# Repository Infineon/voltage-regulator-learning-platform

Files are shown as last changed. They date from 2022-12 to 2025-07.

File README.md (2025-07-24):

# Learning Platform for Switching Regulators

<p align="center">
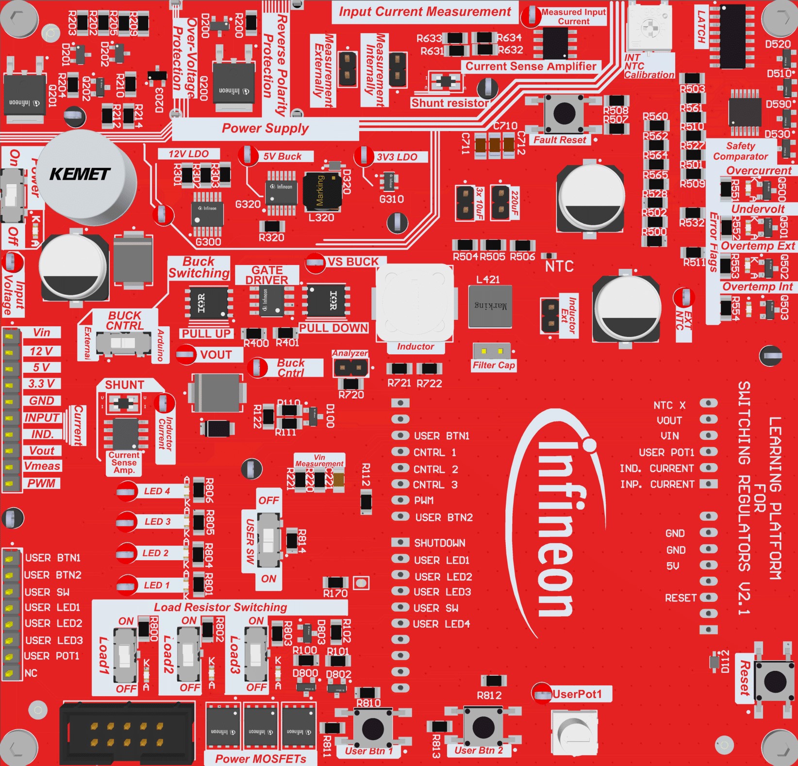
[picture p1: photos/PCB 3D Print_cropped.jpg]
  
</p>

This platform is designed with the intention of providing an interactive educational opertunity to university students with diverse technical backgrounds on switching regulators (namely buck converters). The project aims to develop the students' skills on using basic microcontroller IO features as starters and then build upon those skills to use a gate driver to implement a buck converter and monitor its output and efficiency. Along the Buck converter design process, the students get to use the the on board's peripherals to understand the different properties of buck converters and how they could be optimized. 

## Project's History
The project was introduced as a bachelor thesis of **Lukas Wiegert**. (*version 1.0*). Continued and further developed by **Adrian Keil** (*Versions: 1.0 ,1.1 ,1.2*) and finalized by **Youssef Tarkhan** (*versions: 2.0, 2.1*). The latest update was done 2025 from **David Lopez** (*version: PCBv3*). The boards are used by the Technical University of Munich to teach the students and assess the quality and functionality of these boards and provide an open source curriculum.

# Latest Update PCBv3

The latest update included mainly following changes:
- Removing the 3.3V rail. Only two remaining power supply rails (12V for power part, 5V for digital logik and measurements).
- Fixed common error that current measurement opamps burn because of shorted ouputs (male pinheaders get easily shorted when probed)
- Additional output resistance as second safety measure

# Board Breakdown

<p align="center">
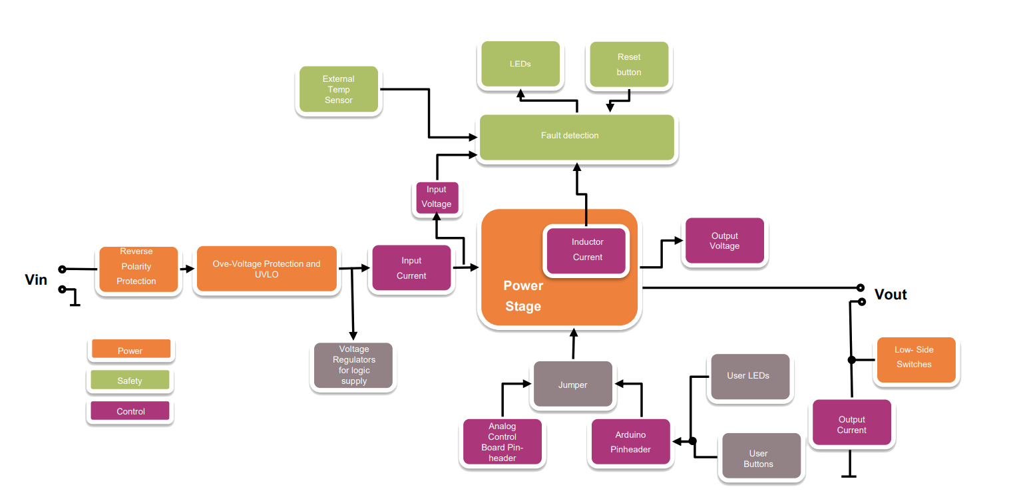
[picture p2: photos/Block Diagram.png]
  
</p>

**Brief summary**: As you can see from the block diagram, the board needs an input connection. (Bannana ports are provided at the bottom side of the board).  After the board makes sure that the polarity and the voltage are in check, the power is fed into the board's internal powersupply compartment. If the voltage level is below 10V then you will observe the undervoltage LED glowing in RED. The powerline feeding the whole board interfaces two optional possibilities for input current measurement. Power is then fed onto the power stage which consists of the components needed for the buck switching with a **VOut** output (*In older versions of the board there used to be additional banana ports for the **Vout** terminal and an additional ground banana port*.) Power is additionally fed into the arduino peripherals for basic microcontroller usage (LEDS, Switches, Buttons and Potentiometers). 

*Note that for every measurable quantity such as the input current for instance, there is a testpoint that could be attached onto an oscilloscope in order to have an easier experience when trying the measure this quantity*

# Microcontroller Pinouts
This platform is an arduino compatable shield. It is intended to be used in combination with the XMC1100 Bootkit
The labelling of the XMC1100 Bootkit pins is placed on the bottom layer's silk screen.

>An Arduino compatible shield is a hardware expansion board that is designed to be compatible with Arduino microcontroller boards. It is called a "shield" because it typically attaches on top of an Arduino board, extending its capabilities and providing additional functionalities

<p align="center">
  
</p>

<center>

## XMC 1100 Bootkit Pins
| Pin | Net | Type | Description |
|---|---|---|---|
| A0 | In_Curr_ADC | Input  | Analog input for current measurement |
| A1 | Inductor_Current_ADC  | Input  | Analog input for inductor current sensing |
| A2 | UserPot1 | Input  | Analog input for user potentiometer 1 |
| A3 | Vin_Meas | Input  | Analog input for voltage measurement |
| A4 | Vout_Meas | Input  | Analog input for output voltage measurement |
| A5 | NTC_ext | Input  | Analog input for external NTC temperature |
| D0 | NC | NC | Not connected |
| D1 | NC | NC | Not connected |
| D2 | UserBtn1 | Input  | Digital input for user button 1 |
| D3 | Cntrl1 | Output | Digital output for control signal 1 |
| D4 | Cntrl2 | Output | Digital output for control signal 2 |
| D5 | Cntrl3 | Output | Digital output for control signal 3 |
| D6 | Buck_Cntrl_Arduino | Output | Digital output for Arduino buck control |
| D7 | UserBtn2 | Input  | Digital input for user button 2 |
| D8 | Shutdown | Input  | Digital input for shutdown signal |
| D9 | User_LED1 | Output | Digital output for user LED 1 |
| D10 | User_LED2 | Output | Digital output for user LED 2 |
| D11 | User_LED3 | Output | Digital output for user LED 3 |
| D12 | UserSw | Input  | Digital input for user switch |
| D13 | User_LED4 | Output | Digital output for user LED 4 |

<br><br>
</center>

> **Note:** The following code snippet defines all the required arduino pins for using the platform, simply copy it to the beginning of your code (before the setup)

<br><br>
<center>

```cpp
// Define all Arduino pins
// Digital Out
#define USER_LED1     9
#define USER_LED2     10
#define USER_LED3     11
#define USER_LED4     13
#define BUCK_PIN      6

// Digital In
#define USER_BTN1     2
#define USER_BTN2     7
#define SHUTDOWN      8
#define USER_SW       12

// Analog In
#define IN_CURR       A0
#define INDUCTOR_CURR A1
#define USER_POTI     A2

#define VIN_MEAS      A3
#define VOUT_MEAS     A4
#define NTC           A5

```

</center>
<br>
<br>
Also add the following pin setup lines into your setup loop 

<center>

```cpp
  pinMode(BUCK_PIN, OUTPUT);
  pinMode(USER_LED1, OUTPUT);
  pinMode(USER_LED2, OUTPUT);
  pinMode(USER_LED3, OUTPUT);
  pinMode(USER_LED4, OUTPUT);
  pinMode(USER_BTN1, INPUT);
  pinMode(USER_BTN2, INPUT);
  pinMode(USER_SW, INPUT);
  pinMode(SHUTDOWN,INPUT);
  pinMode(USER_POTI,INPUT);
  pinMode(INDUCTOR_CURR,INPUT);
  pinMode(IN_CURR,INPUT);

```

</center>
<br>
<br>

> **Note:** In order to use both user buttons you'll have to unsolder the resistor at Pin 1.4 (check out the diagram below)

<p align="center">
  <a href="https://www.infineon.com/cms/de/product/evaluation-boards/kit_xmc11_boot_001/">
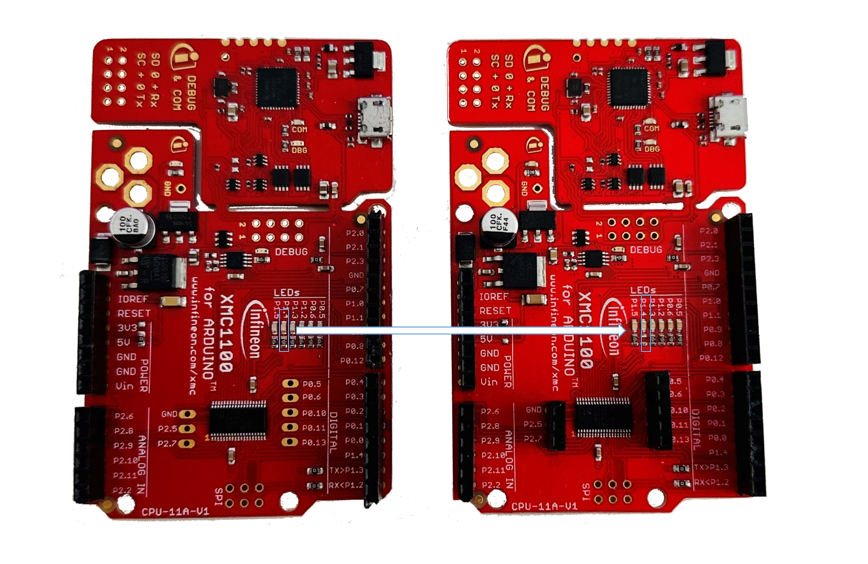
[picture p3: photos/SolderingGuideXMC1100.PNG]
  
  </a>
</p>

# Power Input
The board is equipped with a variety of safety measures to ensure that it not only has a long life, but also ensure that students get to have a higher level of freedom with it. The board is to be powered with a DC power supply through banana plugs. 

<p align="center">
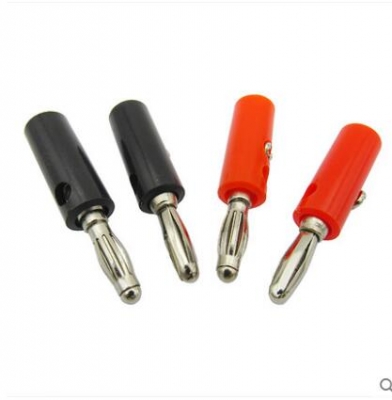
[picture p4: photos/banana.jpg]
  
</p>

- First stage of the power input is going through the reverse polarity protection circuit, following by over voltage detection circuit. ( In case of an overvoltage detection, power is cut from the main circuit through a MOSFET) Note that the board supports up to 30V but has a recommended to be used in the 15V input range
- Voltage is then delivered to the board compartments : Powersupply, Safety Comparator, Powerstage stage & Miscellaneous  

# Power Supply
The Optimum input Voltage for the board input is around **15V**. In case the voltage goes over 19V the board goes into a hysterisis where it only gets back in operation when the voltage level goes below ****. Feel free to check the simulation files if you want to get a deeper insight into how the hysterisis works on a circuit design level. (You will have to install the spice model files for the ATL431, [click here](https://www.youtube.com/watch?v=EwAxUvS5z-0) for a guide on how to do that)
Along with the input being fed into the board, the board additionally has 3 additional power components which are:
<center>

 **12V LDO**: 
<p align="center">
  <a href="https://www.infineon.com/cms/de/product/power/linear-voltage-regulator/linear-voltage-regulators-for-automotive-applications/tlt807b0epv/">
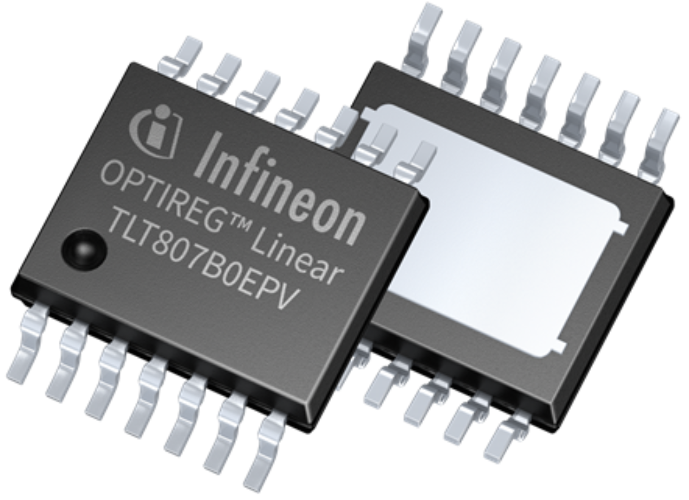
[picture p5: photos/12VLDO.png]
    
  </a>
</p>
	- Gate driver IC
	- Input Internal Current Sense Amplifier
	- Safety Latch 
	- Safety Circuit Comparator
	- Safety LEDs

**5V Buck**: 
<p align="center">
  <a href="https://www.infineon.com/cms/de/product/power/dc-dc-converters/switching-regulators/optireg-switchers-automotive/tlf50211el/">
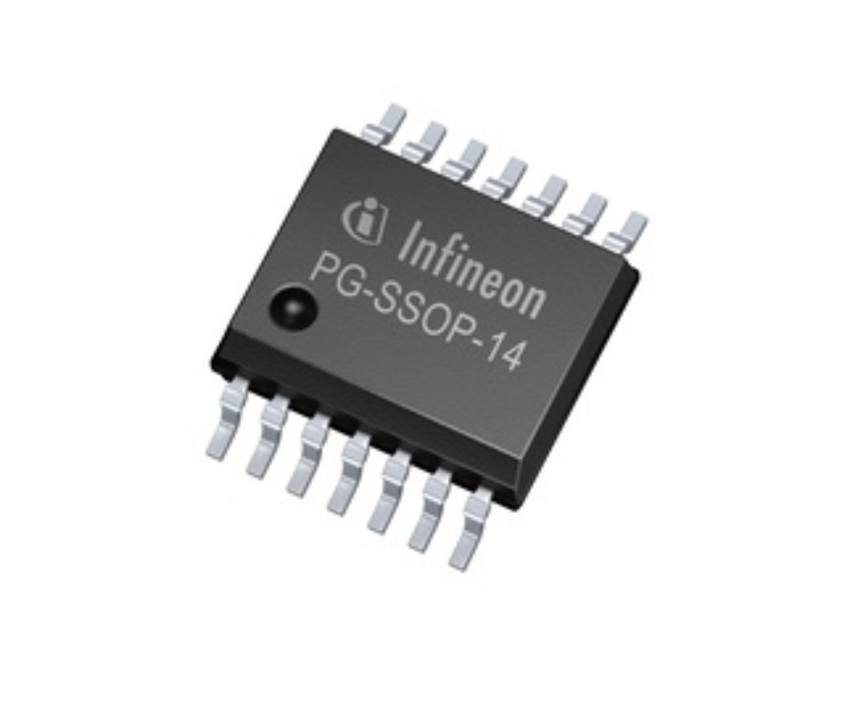
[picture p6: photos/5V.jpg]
    
  </a>
</p>
	- 3V3 LDO
	- Arduino Compatable MCU 
	- Safety Circuitry Voltage Threshhold (*Under-Voltage Detection*)
  
**3V3 LDO**:
<p align="center">
  <a href="https://www.infineon.com/cms/de/product/power/linear-voltage-regulator/linear-voltage-regulators-for-automotive-applications/tle4295g-v33/">
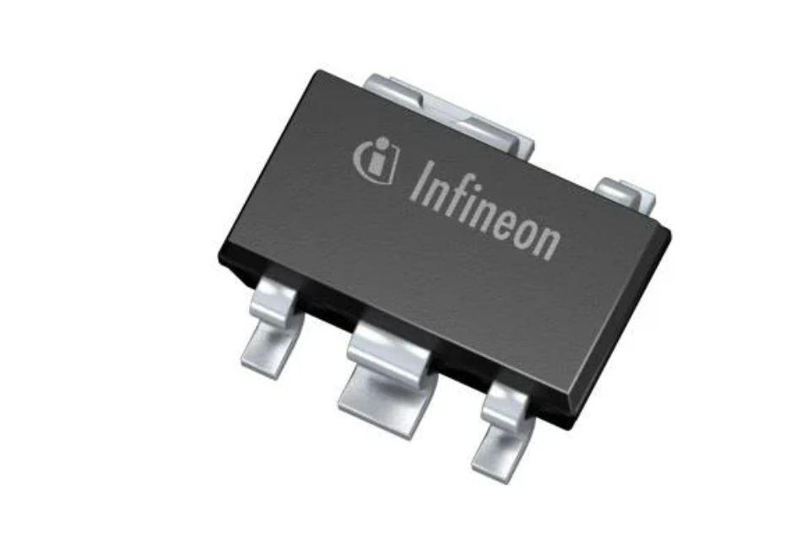
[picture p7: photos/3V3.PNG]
    
  </a>
</p>
	- Output Internal Current Sense Amplifier
	- ADC Compensation for MCU Input
	- Safety Comparator Circuit
</center>		

<br><br>

# Safety
The safety compartment of the board is comprised mainly of a comparator and a safety latch, where when the safety comparator detects a flag, this flag is saved on the latch. (To reset the latch all you'll have to do is press the latch reset button)

For example if the undervoltage flag is raised (Input voltage goes below 10V), the undervoltage flag will be raised and the corresponding LED will turn on. Aslong as the latch has not been reset, even if the input voltage goes above 10V, the LED will stay on and the shutdown signal will keep getting sent to the microcontroller and the power components. 

**Flags**

When safety flags are triggered, a **shutdown** signal is generated and the corresponding flag's LED is lit. The **shutdown** signal is delivered to the microcontroller and the power stage components. The powerstage is disabled as long as the shutdown signal is being delivered to its components.  

- **Overcurrent**
  - The output current from the powerstage is measured over a shuntresistor and a current sense amplifier. The output signal is then fed into a the safety comparator, which is compared to a constant reference voltage. (This reference voltage is equal to the corresponding output of the amplifier when the output current is around **2.8A**). 
  	<p align="center">
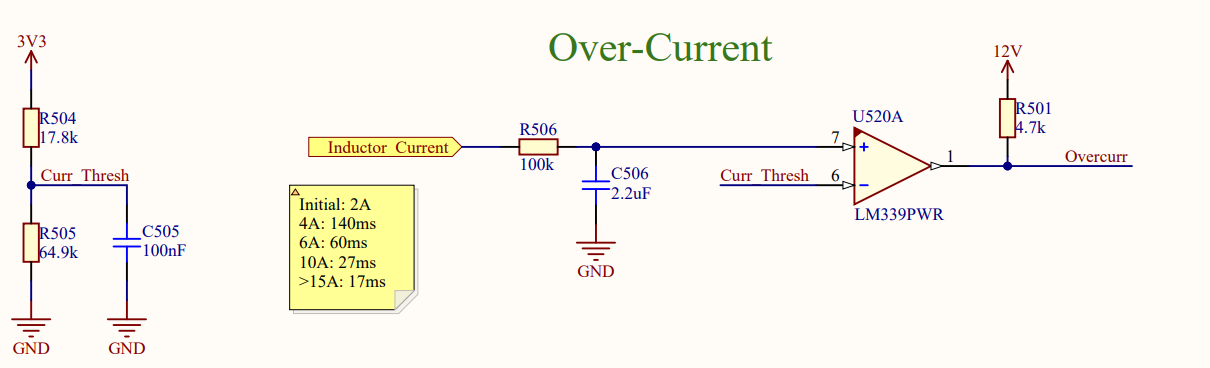
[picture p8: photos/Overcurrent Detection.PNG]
	
	</p>

- **Undervoltage**
  - the input voltage is fed through the two equal value resistors R510 and R511 and the signal is halfed (voltage divider Law), and is then fed into the comparator. As reference the 5V Buck output is fed into the other input of the comparator. If the input voltage goes below 10V , then half of that signal will be lower than 5V and so the undervoltage flag would be triggered.
  <p align="center">
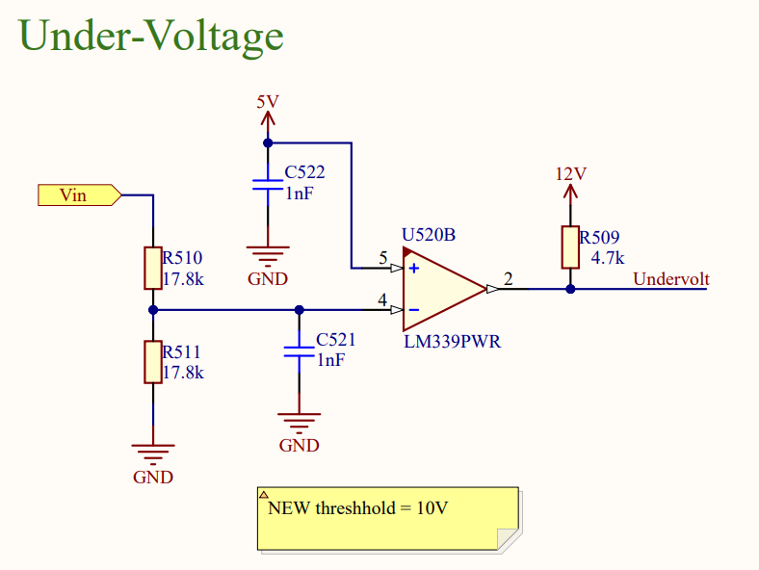
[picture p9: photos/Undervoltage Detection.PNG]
	
	</p>

- **Overtemperature (External)**
  - An NTC is connected on the external resistor board. (Negative Thermal cooefficient resistor; pretty much a fancy word for a resistor, who's resistance value changes when its temperature changes). The NTC's signal is connected to an input of the safety comparator with a reference signal connected to the other input.
    <p align="center">
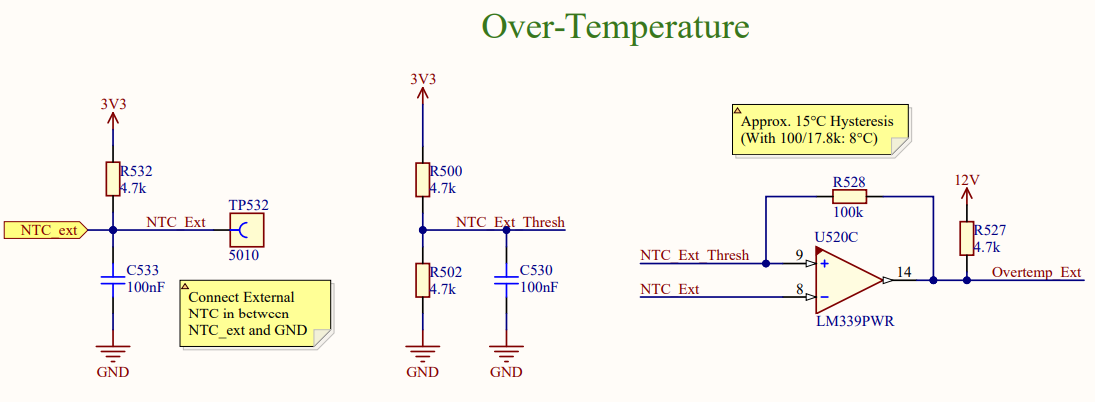
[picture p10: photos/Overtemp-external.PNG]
	
	</p>
- **Overtemperature (Internal)**
  - Similar to external overtemperature detection, however the NTC is onboard and there is a variable resisotr on board to calibrate the onboard overtemperature limit of the board. 
<p align="center">
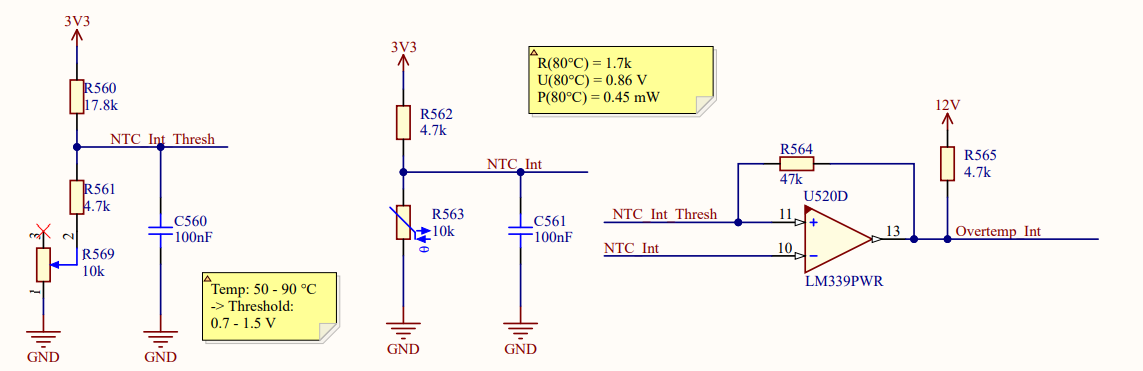
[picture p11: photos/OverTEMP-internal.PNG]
	
	</p>

- **Safety Flag LEDs**
  - you can find the safety LEDs are placed on the top right corner of the PCB
<p align="center">
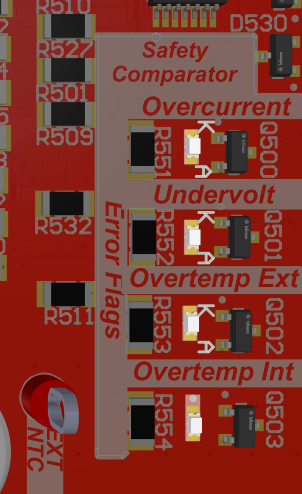
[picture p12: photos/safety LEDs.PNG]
	
	</p>

<br><br>
## Miscellaneous
The board is equipped with:
- 1 User programmable potentiometer
  
- 2 User programmable buttons
  
- 4 User programmable LEDs

- 1 User programmable Switch

<br>

##  Buck Operation
The buck operation takes place over a gate driver; what happens: is that the gate driver takes in pulse width modulated signals from the microcontroller (**XMC 1100 Bootkit**) or an external controller through the **PWM** pin on the external control pin header.  The users have to modify the **BUCK CNTRL** switch to adapt the circuitry to whether or not the control signal would be coming from the external control pin header or through the onboard controller pins. The students get to change the frequency and duty cycle of the signal in order to achieve their desired output voltage. 

<p align="center">
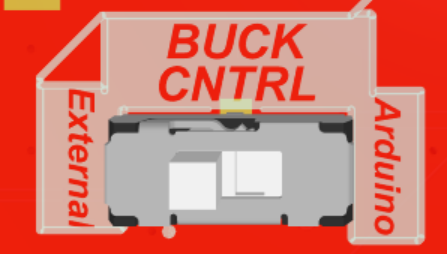
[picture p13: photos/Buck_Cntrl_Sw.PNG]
	
	</p>

There are also some jumpers on board that could adjust the output circuity of the buck operation.
Jumpers are available for: 
- Connecting three 10 uF Capacitors 
- Connecting a 220uF capacitor
- Connecting a 15uH inductor

<p align="center">
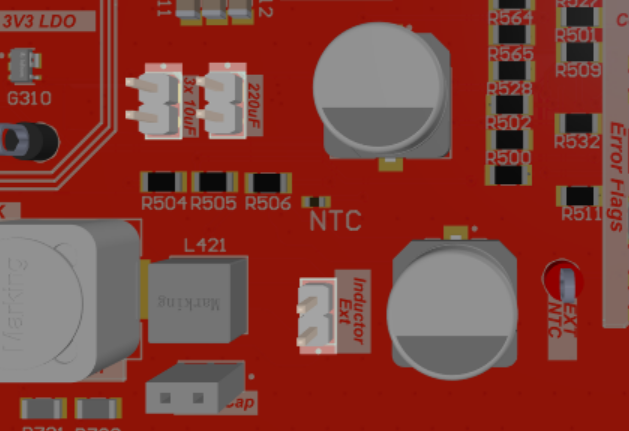
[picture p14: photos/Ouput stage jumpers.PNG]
	
	</p>

## External Control

Aside from using the board as a shield, it could also just be connected to an external controller circuit.

<p align="center">
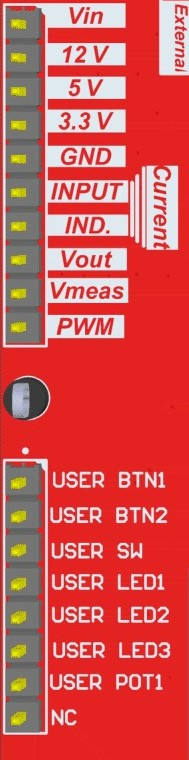
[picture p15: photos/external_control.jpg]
	
	</p>

As shown in the diagram above, using jumper cables, the user externally has access to: 

- Input voltage to through the Banana cables
- 12V Output of the LDO
- 5V Output of the Buck Controller
- 3.3V Output of the LDO
- Input Current Sensor Reading
- Output Current Sensor Reading
- Output Voltage 
- Output Voltage (Calibrated to 0 to 5V)
- External Buck Control
- User Button 1 Input
- User Button 2 Input
- User Switch Input
- User LEDs (1 to 3)
- User Potentiometer 1 Input

### NTC Calibration
- For making sure that the temperature on board is in check, negative thermal coefficient resistors are chosen . The onboard maximum temperature could easily be calibrated by adjusting a potentiometer for temperature limitation between (50°C and 90°C)

## Current Measurement
The main method of current measurement is the combination of a shunt resistor and a current sense amplifier. This setup is repeated in the input and output current measurement system. The operation relies on a voltage drop accross the shunt resistor proportional to the current flowing through it. This voltage drop is amplified by the current sense amplifier into a new voltage value. This voltage value is read by the micro-controller's ADC and it's used to subsequently calculate the value of the current.

<p align="center">
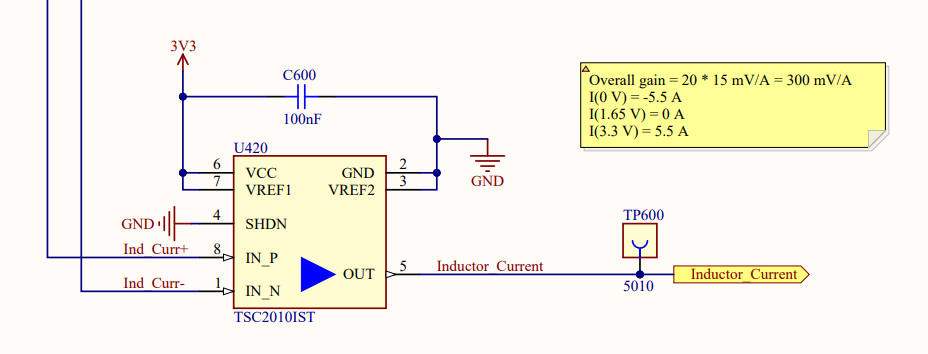
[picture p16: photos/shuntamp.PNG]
	
	</p>

the main component (TSC2010IST) in the diagram above is a current sense amplifier. This current sense amplifier is connected over a shunt resistor (pins: 1 & 8). The output of this amplifier is proportional to the amount of current going through the shunt resistor. 

<br>

# Testpoints

The board is equiped with test points to make it easier for students to observe different quantities using an oscilloscope.

<center>
<p align="center">
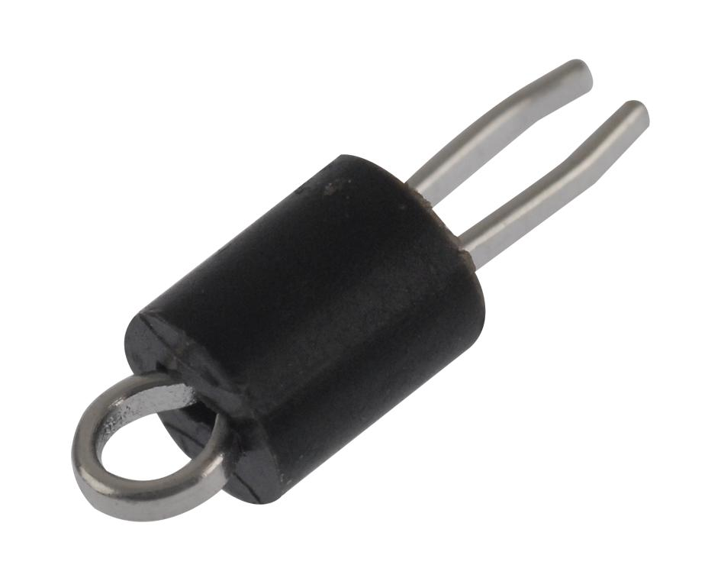
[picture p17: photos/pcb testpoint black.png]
	
	</p>
All black testpoints are Ground testpoints
 
<p align="center">
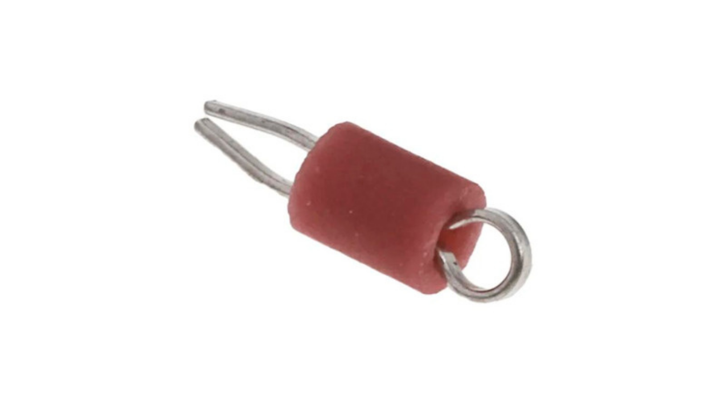
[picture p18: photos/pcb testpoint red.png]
	
	</p>
Red testpoints are labelled with their corresponding measurement quantity. 

</center>
<br>

# Simulation Files
To provide a rich experience to students, the simulation files for most of the building blocks of the learning platform are provided. These simulations are accessable on LTSPICE, which is an open source freeware, that is very popular in the industry.  

You can find these simulations under the Directory /Simulations.
<br>

# Future Strategy 
This project is not yet fully disclosed, and it will remain under  development so feel free to reach out to youssef.tarkhan@infineon.com for any inquiries or suggestions anytime.

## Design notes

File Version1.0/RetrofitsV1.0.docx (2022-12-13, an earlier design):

# Necessary Changes on V1.0 Board

# Drain and Soruce of Q201 are reversed

1. Desolder Q201
2. Cut the traces as shown by the red marks in the following image:

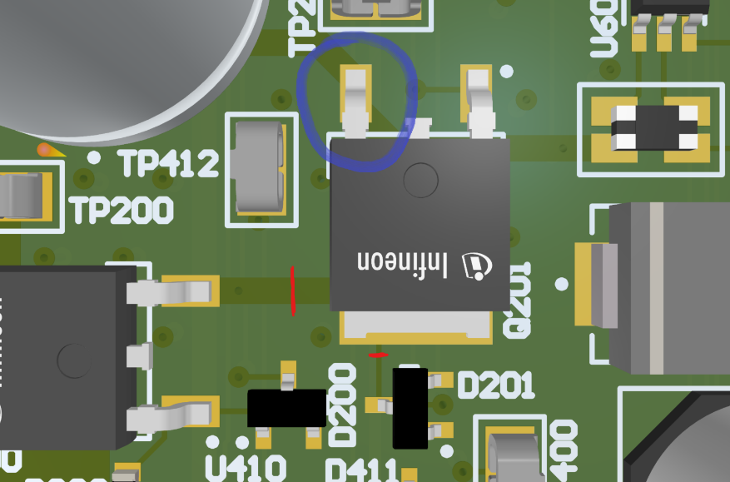
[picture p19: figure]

3. Straighten the leg of Q201 that is marked blue. Q201 has to be desoldered for this! Use flat pliers and just hold down on the leg, not at the case. Otherwise you will damage the transistor.
4. Use a piece of desoldering braid or something similar to connect the two pads of Q201 as shown below:

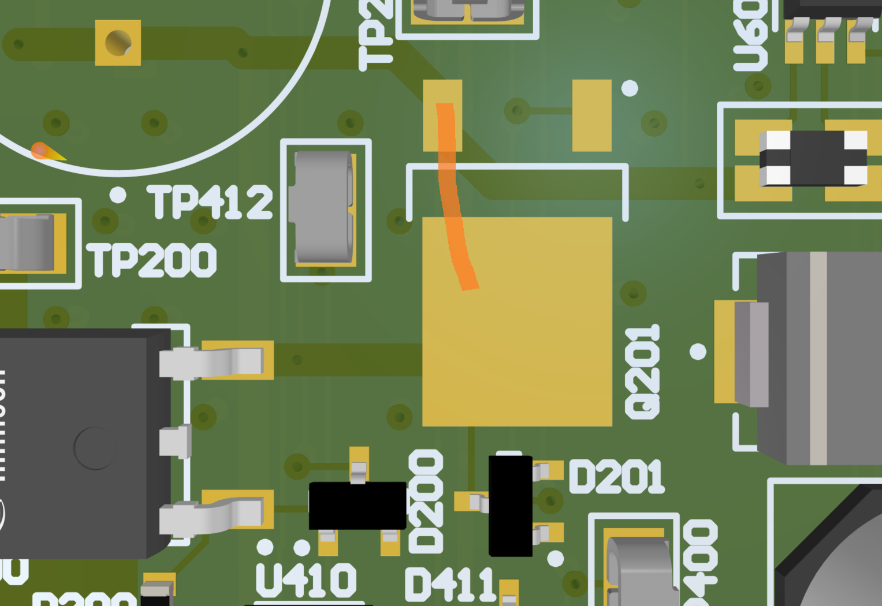
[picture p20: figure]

5. Now resolder Q201 (just on the two pads, the bent pin is left open)
6. Now use some thick copper wire to connect the bent leg of Q201 (not the pad below) and Q200 as shown below and finally some thin copper wire to connect Q201 to the Diode D201:

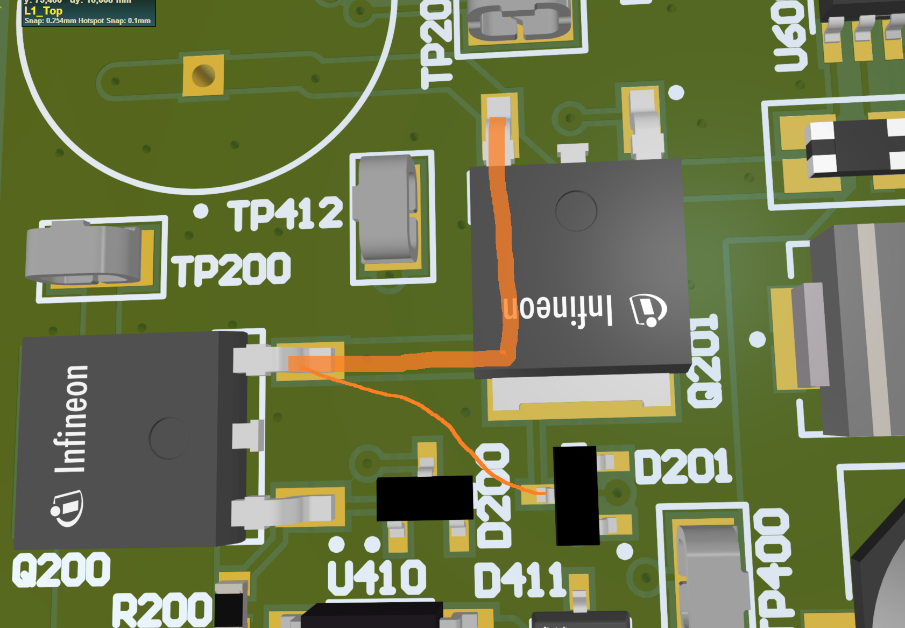
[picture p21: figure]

# Arduino powers logic supply through its Vin

Cut the trace in the shown location (red). Scrape off solder mask on both sides and solder the diode in place as shown. I used an MBR120ESFT1G (20V, 1A Schottky). But the diode can also be soldered somewhere else between Arduino 12V and Board 12V.

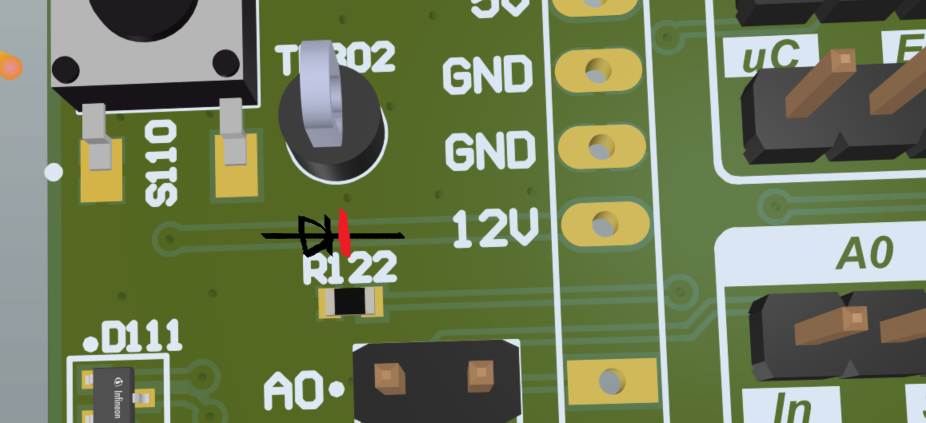
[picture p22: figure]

# Floating Boost_Cntrl

Rotate R123 90° and then connect its left leg to the center pin of the Boost Cntrl Header (run wire to the back side of the PCB)

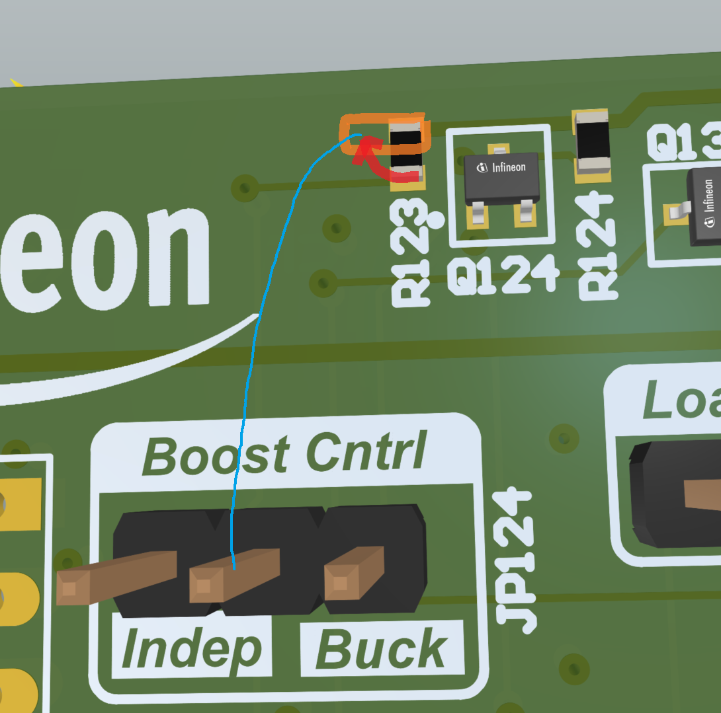
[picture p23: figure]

# Arduino powers logic supply through gate drivers

1. Option 1:
  a. Desolder U400 and U430
  b. Straighten Pin 1 or bend slightly upwards
  c. Resolder U400 and U430
  d. Insert a 4k7 resistor between Pin 1 and the pad below
2. Option 2:
  a. Cut the trace on the back, scrape off solder mask and insert 4k7 resistor (the banana plugs are the top ones)

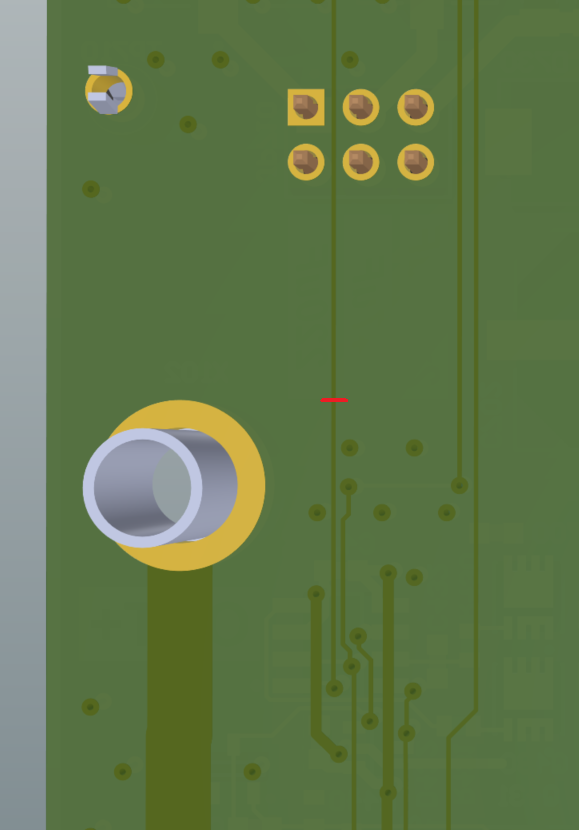
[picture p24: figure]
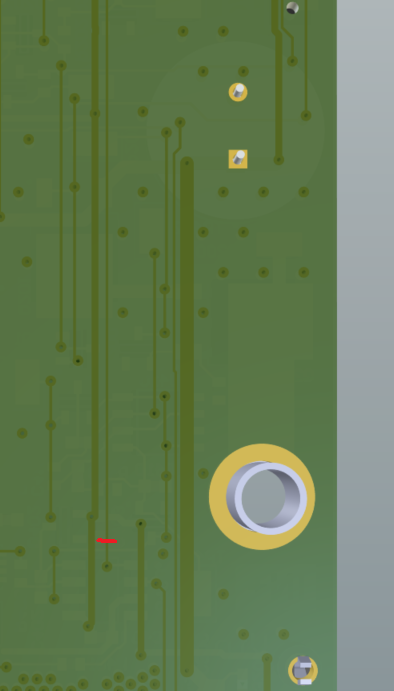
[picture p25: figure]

3. Add clamping diodes as shown below (make sure to use diodes with low leakage current and low capacitance)

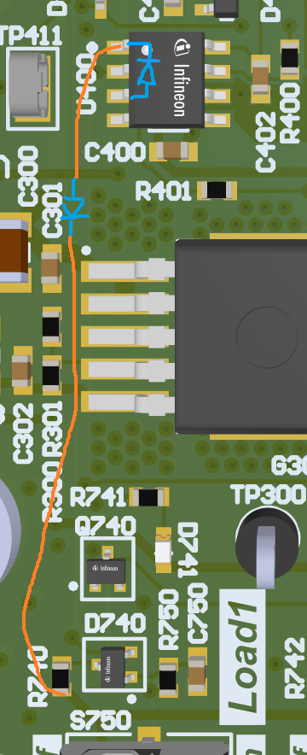
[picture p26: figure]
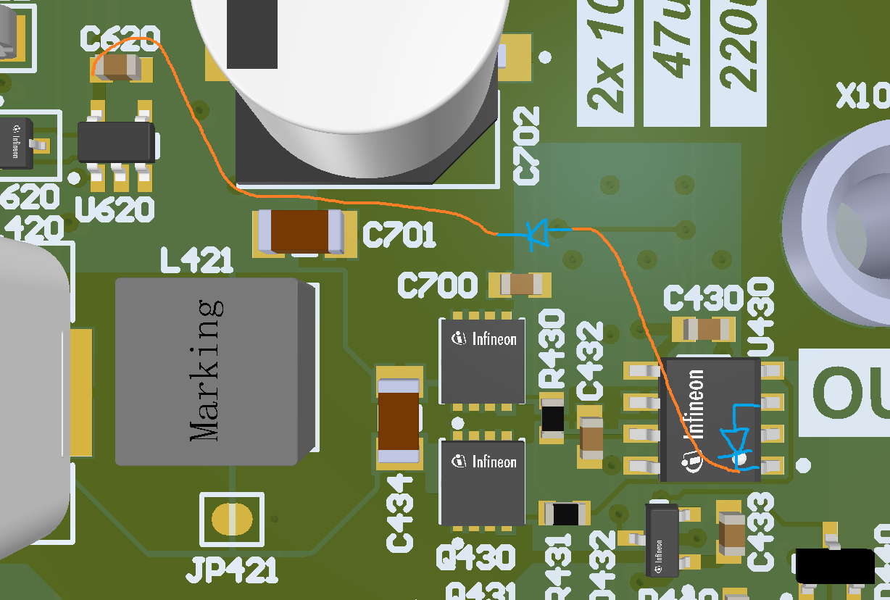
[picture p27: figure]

# Boost shutdown

Cut the trace going to D440 as shown. Add the clamping 15V Zener diode on top of U430. Then add the two diodes: VB->D440 and 12V->D440

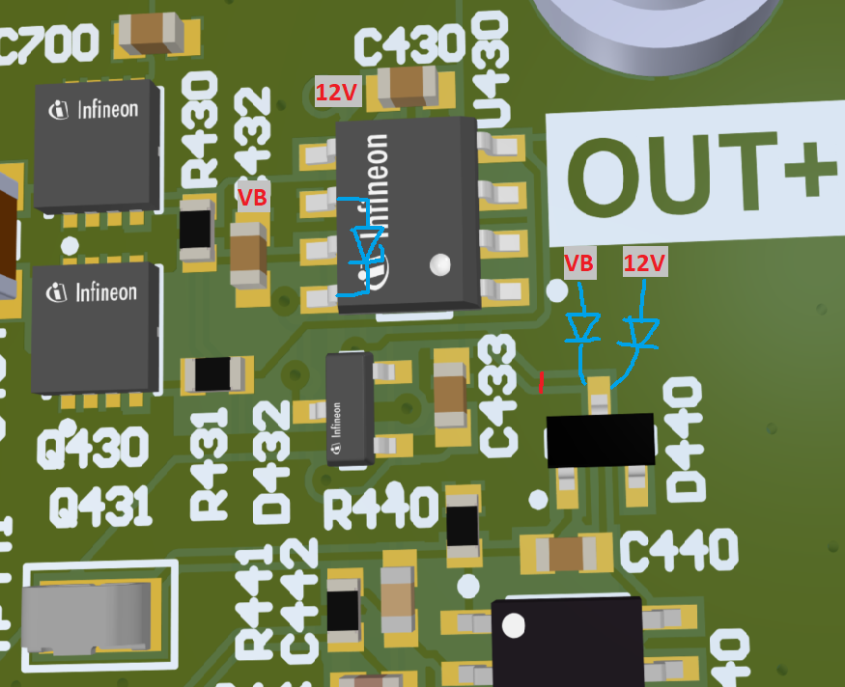
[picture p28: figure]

# Change Vcc of U500 to 12V

Cut the trace on the back side of the board:

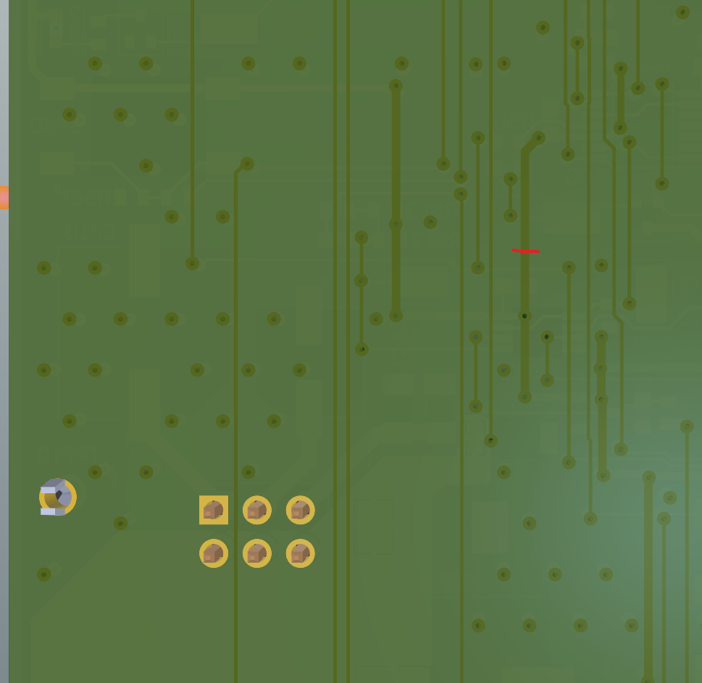
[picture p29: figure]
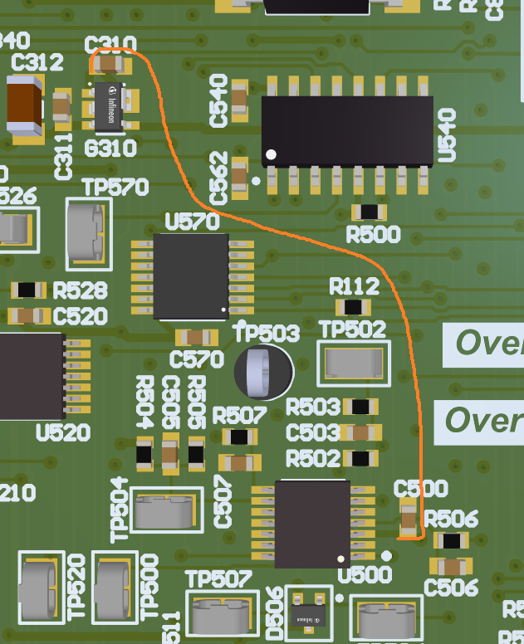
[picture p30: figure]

Rotate R502 180° and connect to D506

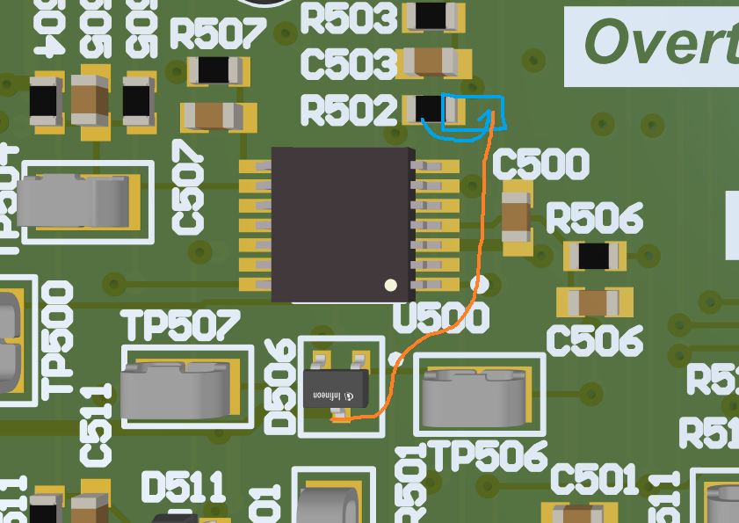
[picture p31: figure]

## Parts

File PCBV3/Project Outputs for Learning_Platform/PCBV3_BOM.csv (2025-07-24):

Quantity | Designator | Value | Part Type | Manufacturer | Article Number | Combined Parameters | Manufacturer Order Number | PackageReference | SheetNumber | LCSC Part # | MPN
1 | 190 | 61201021621 | Connector | Wurth Elektronik | 638630 | Board-to-Board/Cable Header (male);5x2;Mounting:THT;Orient:0° (vertical);Shielded:No | 61201021621 | THT |  |  | 61201021621
1 | C210 | 1mF | Capacitor | Kemet | 646789 | TC:Aluminiumelectrolytic;Tol.:-20%/+20%;Vdc:35V | ESY108M035AL4AA | Radial |  |  | ESY108M035AL4AA
3 | C212, C701, C715 | 220uF | Capacitor | Nippon Chemi-Con | 699376 | TC:Aluminiumelectrolytic;Tol.:-20%/+20%;Vdc:50V | EMZL500ARA221MJA0G | EMZL500ARA221MJA0G |  | C6845235 | EMZL500ARA221MJA0G
10 | C213, C321, C324, C331, C332, C404, C700, C710, C711, C712 | 10uF | Capacitor, [NoParam] | Taiyo Yuden, [NoParam] | 648992, [NoParam] | TC:X5R (EIA);Tol.:-20%/+20%;Vdc:50V, [NoParam] | C97712, UMK316BBJ106ML-T, [NoParam] | 1206 (3216), [NoParam] |  | [NoValue], [NoParam], C97712 | UMK316BBJ106ML-T
18 | C220, C320, C322, C400, C402, C500, C505, C520, C530, C533, C540, C560, C561, C600, C630, C811, C813, C814 | 100nF | Capacitor, [NoParam] | MuRata, [NoParam] | 282874, [NoParam] | TC:X7R (EIA);Tol.:-10%/+10%;Vdc:50V, [NoParam] | GRM31MR71H104KA01, [NoParam] | 1206 (3216), [NoParam] |  | C82601, C97928 | KAM31NR72A104KU
1 | C221 | 1nF | Capacitor | MuRata | 280698 | TC:X7R (EIA);Tol.:-10%/+10%;Vdc:50V | GRM319R71H102KA01 | 1206 (3216) |  | C440200 | C1206C102J1RACTU
1 | C506 | 22nF |  |  |  |  |  |  |  | C97929 | GRM3195C1H223JA01D
1 | D112, D320 | BAS3010A03WE6327HTSA1 |  |  |  |  |  |  |  |  | BAS3010A03WE6327HTSA1
3 | D200, D201, D202 | 12V | Diode | Nexperia | 659605 | Vf:900mV;If:10mA;Ur:8V;Ir:100nA;Pmax:250mW | BZX84-C12,215 | SOT-23 |  | C12773 | BZX84-C12,215
1 | D203 | ATL431AQDBZR | Integrated Circuit | Texas Instruments | 644060 | - -;Vdc min/max:-;Iout:-;Fmax:- | ATL431AQDBZR | SOT23-3 (DBZ) |  | C92572 | ATL431AQDBZR
12 | D210, D502, D503, D504, D550, D741, D801, D804, D805, D806, D807, D808 | Red | Diode | Wurth Elektronik | 625459 | Vf:2.4V;If:30mA;Ur:5V;Ir:10uA;Pmax:72mW | 150060RS75000 | 1608 (0603) |  | C3030991 | 150060RS75000
1 | D211 | SMDJ20A | Diode | Littelfuse | 646382 | Vf:5V;If:-;Ur:20V;Ir:2uA;Pmax:6.5W | SMDJ20A | DO-214AB |  | C2990194 | SMDJ20A
1 | D400 | PMEG3010ER,115 |  |  |  |  |  |  |  |  | PMEG3010ER,115
7 | D510, D520, D530, D590, D800, D802, D803 | BAT54-05 | Diode | Infineon Technologies | 430837 | Vf:800mV;If:200mA;Ur:30V;Ir:2uA;Pmax:230mW | BAT54-05 | PG-SOT23-3-11 |  | C533646 | BAT5405E6327HTSA1
1 | D730 | SMC5K40A-M3/I | Diode | Vishay | 646377 | Vf:-;If:-;Ur:40V;Ir:-;Pmax:5kW | SMC5K40A-M3/I | SMC (DO-214AB) |  |  | 5.0SMDJ40AS
1 | D731 | PMEG6030ETPX | Diode | Nexperia | 646087 | Vf:530mV;If:4.2A;Ur:60V;Ir:200uA;Pmax:750mW | PMEG6030ETPX | SOD128 |  |  | PMEG6030ETPX
1 | G320 | LMR51420XFDDCR |  |  |  |  |  |  |  | C5752071 | LMR51420XFDDCR
1 | G330 | LP3875EMP-5.0/NOPB |  |  |  |  |  |  |  | C2860557 | LP3875EMP-5.0/NOPB
4 | J421, J710, J715, P110 | 61300211121 | Connector, [NoParam] | Wurth Elektronik, [NoParam] | 386760, [NoParam] | Board-to-Board Header (male);2x1;Mounting:THT;Orient:0° (vertical);Shielded:No, [NoParam] | 61300211121, [NoParam] |  |  |  | 61300211121
1 | L320 | 22uH | Inductor | Wurth Elektronik | 638654 | Tol.:-20%/+20%;Rdc:89mR;Idc:2.1A;Fres:15MHz | 74404064220 | SMD |  | C1331921 | 74404064220
1 | L420 | 27uH | Inductor | Wurth Elektronik | 657324 | Tol.:-20%/+20%;Rdc:40mR;Idc:4.6A;Fres:8MHz | 7447709270 | 1210 |  | C6404671 | 7447709270
1 | L421 | 15uH | Inductor | Bourns | 657326 | Tol.:-20%/+20%;Rdc:43mR;Idc:5.8A;Fres:11MHz | SRP6060FA-150M | 6.6 x 6.4 mm |  | C2047415 | SRP6060FA-150M
1 | NTC | NTC | Resistor | MuRata | 466242 | TCR:-;Tol.:-1%/+1%;Vdc:-;Idc:-;P:100mW | NCP18XH103F03RB | 0603 |  |  | NCP18XH103F03RB
2 | Q200, Q201 | IPD650P06NM | Transistor FET | Infineon Technologies | 644075 | P-Channel Enhancement;Uds:-60V;Id:-22A;Rds:65R;P:83W | IPD650P06NM | PG-TO252-3-313 |  |  | IPD650P06NMATMA1
5 | Q202, Q500, Q501, Q502, Q503 | ISS17EP06LM | Transistor FET | Infineon Technologies | 615536 | P-Channel Enhancement;Uds:-60V;Id:-300mA;Rds:1.7R;P:360mW | ISS17EP06LM | PG-SOT23-3-5 |  |  | ISS17EP06LMXTSA1
2 | Q400, Q401 | BSC067N06LS3 G |  |  |  |  |  |  |  |  | BSC067N06LS3 G
1 | Q402 | IPD70P04P4L08ATMA2 |  |  |  |  |  |  |  |  | IPD70P04P4L08ATMA2
3 | Q741, Q800, Q801 | BSC0906NS | Transistor FET | Infineon Technologies | 691273 | N-Channel Enhancement;Uds:30V;Id:63A;Rds:4.5R;P:30W | BSC0906NS | TDSON-8 |  |  | BSC0906NSATMA1
7 | R100, R101, R102, R204, R507, R527, R565 | 100k | Resistor, [NoParam] | Vishay, Vishay Dale | 354752, [NoParam] | TCR:100ppm/K;Tol.:-1%/+1%;Vdc:200V;Idc:-;P:250mW, [NoParam] | CRCW1206100KFK, [NoParam] | 1206 (3216), [NoParam] |  | C205048 | CRCW1206100KFKEAC
11 | R112, R200, R202, R203, R205, R209, R503, R528, R564, R810, R812 | 47k | Resistor, [NoParam] | Vishay, Vishay Dale | 354562, [NoParam] | TCR:100ppm/K;Tol.:-1%/+1%;Vdc:200V;Idc:-;P:250mW, [NoParam] | CRCW120647K0FK, [NoParam] | 1206 (3216), [NoParam] |  | C844663 | CRCW120647K0FKEAC
1 | R160 | 3362P-1-103T_LF | Resistor | Bourns | 647233 | TCR:100ppm/K;Tol.:-10%/+10%;Vdc:300V;Idc:-;P:500mW | 3362P-1-103T_LF | THT |  | C6807374 | 3362P-1-103TLF
4 | R210, R212, R511, R814 | 18k |  |  |  |  |  |  |  |  | CRCW120618K0FKEA
2 | R211, SHUNT | 15mR | Resistor | Ohmite | 644055 | TCR:75ppm/K;Tol.:-1%/+1%;Vdc:-;Idc:-;P:500mW | L4T12FR015FER | 1206 (3216) |  |  | L4T12FR015FER
1 | R214 | 1MEG | Resistor | Vishay | 355322 | TCR:100ppm/K;Tol.:-1%/+1%;Vdc:200V;Idc:-;P:250mW | CRCW12061M00FK | 1206 (3216) |  | C108083 | CRCW12061M00FKEA
4 | R220, R500, R560, R721 | 22k |  |  |  |  |  |  |  | C844656 | CRCW120622K0FKEA
6 | R221, R332, R402, R501, R509, R722 | 4.7k | [NoParam], Resistor | Vishay Semiconductor, Vishay | [NoParam], 353992 | [NoParam], TCR:100ppm/K;Tol.:-1%/+1%;Vdc:200V;Idc:-;P:250mW | [NoParam], CRCW12064K70FK | [NoParam], 1206 (3216) |  | C137262, [NoParam] | CRCW12064K70FKEA
1 | R321 | 39k |  |  |  |  |  |  |  |  | CRCW120639K0FKEA
2 | R400, R401 | 20.5R | Resistor | Vishay | 352637 | TCR:100ppm/K;Tol.:-1%/+1%;Vdc:200V;Idc:-;P:250mW | CRCW120620R5FK | 1206 (3216) |  | C488728 | CRCW120620R5FKEA
13 | R502, R551, R552, R553, R554, R561, R800, R801, R802, R803, R804, R805, R806 | 4.7KOhm |  | Vishay Semiconductor |  |  |  |  |  | C137262 | CRCW12064K70FKEA
4 | R504, R505, R811, R813 | 64.9k | [NoParam], Resistor | [NoParam], Vishay | [NoParam], 354647 | [NoParam], TCR:100ppm/K;Tol.:-1%/+1%;Vdc:200V;Idc:-;P:250mW | [NoParam], CRCW120664K9FK | [NoParam], 1206 (3216) |  | C274045 | CRCW120664K9FKEA
3 | R506, R532, R562 | 10k |  | Vishay Dale |  |  |  |  |  | C313977 | CRCW120610K0FKEAHP
3 | R508, R610, R635 | 2.2k | Resistor, [NoParam] | Vishay, [NoParam] | 353792, [NoParam] | TCR:100ppm/K;Tol.:-1%/+1%;Vdc:200V;Idc:-;P:250mW, [NoParam] | CRCW12062K20FK, [NoParam] | 1206 (3216), [NoParam] |  | C204754 | CRCW12062K20FKEA
1 | R510 | 56k |  |  |  |  |  |  |  | C137251 | CRCW120656K0FKEA
1 | R569 | 3361P-1-103GLF |  |  |  |  |  |  |  | C840679 | 3361P-1-103GLF
2 | R611, R636 | 0k |  |  |  |  |  |  |  | C844861 | CRCW12060000Z0EA
4 | S110, S560, S810, S812 | 1301.9314 | Electro Mechanic | Schurter | 380147 |  | 1301.9314 |  |  |  | 1301.9314
6 | S122, S200, S800, S801, S802, S814 | 500SSP1S2M2QEA |  |  |  |  |  |  |  |  | 500SSP1S2M2QEA
6 | TP100, TP101, TP102, TP103, TP104, TP105 | 5011 | Connector | Keystone Electronics Corp. | 382410 | Board-to-Cable None (onboard);1x1;Mounting:THT;Orient:0° (vertical);Shielded:No | 5011 |  |  | [NoValue], C238127 | 5011
9 | TP160, TP211, TP320, TP400, TP401, TP431, TP532, TP600, TP630 | 5010 | Connector | Keystone Electronics Corp. | 382400 | Board-to-Cable None (onboard);1x1;Mounting:THT;Orient:0° (vertical);Shielded:No | 5010 |  |  | C2906765 | 5010
1 | U400 | LTC4449EDCBTRMPBF |  |  |  |  |  |  |  | C580913 | LTC4449EDCB#TRMPBF
1 | U420 | TSC2010HYDT |  |  |  |  |  |  |  | C4370994 | TSC2010HYDT
1 | U520 | LM339PWR | Analog Parts | Texas Instruments | 409035 | Res.:-;Fmax:- | LM339PWR | TSSOP-14 (PW) |  |  | LM339PWR
1 | U540 | HEF4043BT,653 | Integrated Circuit | Nexperia | 648079 | - Digital;Vdc min/max:3V/15V;Iout:2.4mA;Fmax:- | HEF4043BT,653 | SO-16 |  |  | HEF4043BT,653
1 | U630 | TSC2011HYDT |  |  |  |  |  |  |  |  | TSC2011HYDT
1 | X100 | 973 582-101 | Connector | Hirschmann Test & Measurement | 377341 | Board-to-Cable Socket (female);2x1;Mounting:THT;Orient:90° (right angle);Shielded:No | 973 582-101 |  |  |  | 973582101
1 | X101 | 973 582-100 | Connector | Hirschmann Test & Measurement | 377401 | Board-to-Cable Socket (female);-x-;Mounting:THT;Orient:90° (right angle);Shielded:No | 973 582-100 |  |  |  | 973582100
1 | X110 | Arduino-Uno | Connector | Infineon Technologies | 644888 | Board-to-Board Socket (female);-x-;Mounting:THT;Orient:0° (vertical);Shielded:- | Arduino-Uno | THT
1 | X140 | CES-105-01-L-S |  |  |  |  |  |  |  |  | CES-105-01-L-S

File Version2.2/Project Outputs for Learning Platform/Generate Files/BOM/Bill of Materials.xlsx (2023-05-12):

Quantity | Article Number | Designator | Value | Manufacturer | Manufacturer Order Number | Combined Parameters | Fitted | Part Type | PackageReference | SheetNumber | Supplier 1 | Supplier 2 | Supplier 3 | Supplier Part Number 1 | Supplier Part Number 2 | Supplier Part Number 3
1 | 646789 | C210 | 1mF | Kemet | ESY108M035AL4AA | TC:Aluminiumelectrolytic;Tol.:-20%/+20%;Vdc:35V | Fitted | Capacitor | Radial |  | Farnell | DigiKey | Mouser | 2835188 | 399-6120-ND | 80-ESY108M035AL4AA
3 | 699376 | C212, C701, C715 | 220uF | Nippon Chemi-Con | EMZL500ARA221MJA0G | TC:Aluminiumelectrolytic;Tol.:-20%/+20%;Vdc:50V | Fitted | Capacitor | EMZL500ARA221MJA0G |  | Farnell | DigiKey | Mouser |  |  | 661-EMZL500ARA221MJA
8 | 648992 | C213, C321, C324, C404, C700, C710, C711, C712 | 10uF | Taiyo Yuden | UMK316BBJ106ML-T | TC:X5R (EIA);Tol.:-20%/+20%;Vdc:50V | Fitted | Capacitor | 1206 (3216) |  | Farnell | DigiKey | Mouser | 2779059 | 587-3248-1-ND | 963-UMK316BBJ106ML-T
19 | 282874 | C220, C300, C310, C320, C400, C401, C402, C500, C505, C520, C530, C533, C540, C560, C561, C630, C811, C813, C814 | 100nF | MuRata | GRM31MR71H104KA01 | TC:X7R (EIA);Tol.:-10%/+10%;Vdc:50V | Fitted | Capacitor | 1206 (3216) |  | Farnell | DigiKey | Mouser
3 | 280698 | C221, C521, C522 | 1nF | MuRata | GRM319R71H102KA01 | TC:X7R (EIA);Tol.:-10%/+10%;Vdc:50V | Fitted | Capacitor | 1206 (3216) |  | Farnell | DigiKey | Mouser
4 | 279853 | C301, C311, C312, C506 | 2.2uF | MuRata | GRM316R61E225KA12 | TC:X5R (EIA);Tol.:-10%/+10%;Vdc:25V | Fitted | Capacitor | 1206 (3216) |  | Farnell | DigiKey | Mouser
1 | 687895 | Current Sense Amp. | TSC2010HYDT | STMicroelectronics | TSC2010HYDT | Res.:-;Fmax:- | Fitted | Analog Parts | SOIC-8 |  | Farnell | DigiKey | Mouser | 3864633RL | 497-TSC2010HYDTCT-ND | 511-TSC2010HYDT
8 | 430837 | D100, D510, D520, D530, D590, D800, D802, D803 | BAT54-05 | Infineon Technologies | BAT54-05 | Vf:800mV;If:200mA;Ur:30V;Ir:2uA;Pmax:230mW | Fitted | Diode | PG-SOT23-3-11 |  | Farnell | DigiKey | Mouser | 2725759 | BAT5405E6327HTSA1TR-ND | 726-BAT5405E6327HTSA
2 | 420617 | D112, D320 | BAS3010A-03W | Infineon Technologies | BAS3010A-03W | Vf:410mV;If:1A;Ur:30V;Ir:200uA;Pmax:- | Fitted | Diode | SOD323 |  | Farnell | DigiKey | Mouser |  | BAS3010A03WE6327HTSA1TR-ND | 726-BAS3010A-03WE6
3 | 659605 | D200, D201, D202 | 12V | Nexperia | BZX84-C12,215 | Vf:900mV;If:10mA;Ur:8V;Ir:100nA;Pmax:250mW | Fitted | Diode | SOT-23 |  | Farnell | DigiKey | Mouser | 1081407 | 1727-2936-1-ND | 771-BZX84-C12-T/R
1 | 644060 | D203 | ATL431AQDBZR | Texas Instruments | ATL431AQDBZR | - -;Vdc min/max:-;Iout:-;Fmax:- | Fitted | Integrated Circuit | SOT23-3 (DBZ) |  | Farnell | DigiKey | Mouser |  | 296-47201-1-ND | 595-ATL431AQDBZR
12 | 625459 | D210, D502, D503, D504, D550, D741, D801, D804, D805, D806, D807, D808 | Red | Wurth Elektronik | 150060RS75000 | Vf:2.4V;If:30mA;Ur:5V;Ir:10uA;Pmax:72mW | Fitted | Diode | 1608 (0603) |  | Farnell | DigiKey | Mouser | 2322071 | 732-4978-1-ND | 710-150060RS75000
1 | 646382 | D211 | SMDJ20A | Littelfuse | SMDJ20A | Vf:5V;If:-;Ur:20V;Ir:2uA;Pmax:6.5W | Fitted | Diode | DO-214AB |  | Farnell | DigiKey | Mouser | 2777300 | SMDJ20ACT-ND | 576-SMDJ20A
1 | 646377 | D730 | SMC5K40A-M3/I | Vishay | SMC5K40A-M3/I | Vf:-;If:-;Ur:40V;Ir:-;Pmax:5kW | Fitted | Diode | SMC (DO-214AB) |  | Farnell | DigiKey | Mouser |  | SMC5K40A-M3/IGICT-ND | 78-SMC5K40A-M3/I
1 | 646087 | D731 | PMEG6030ETPX | Nexperia | PMEG6030ETPX | Vf:530mV;If:4.2A;Ur:60V;Ir:200uA;Pmax:750mW | Fitted | Diode | SOD128 |  | Farnell | DigiKey | Mouser | 2311228 | 1727-1348-1-ND | 771-PMEG6030ETPX
1 | 431580 | G300 | TLT807B0EPV | Infineon Technologies | TLT807B0EPV | Linear Not applicable -;Vo:1.2V to 20V | Fitted | Power Supply | PG-TSDSO-14 |  | Farnell | DigiKey | Mouser |  | TLT807B0EPVXUMA1TR-ND | 726-TLT807B0EPVXUMA1
1 | 617559 | G310 | TLE4295G V33 | Infineon Technologies | TLE4295G V33 | - - -;Vo:3.17V to 3.43V | Fitted | Power Supply | PG-SCT595-5-2 |  | Farnell | DigiKey | Mouser | 2762385 | 448-TLE4295GV33HTSA1CT-ND | 726-TLE4295GV33HTSA1
1 | 508204 | G320 | TLF50211EL | Infineon Technologies | TLF50211EL | - - -;Vo:- to - | Fitted | Power Supply | PG-SSOP-14-3 |  | Farnell | DigiKey | Mouser |  | TLF50211ELXUMA2-ND | 726-TLF50211ELXUMA2
1 | 583359 | GATE DRIVER | 2ED2184S06F | Infineon Technologies | 2ED2184S06F |  | Fitted | Motors and Drives | PG-DSO-8-53 |  | Farnell | DigiKey | Mouser |  | 448-2ED2184S06FXUMA1TR-ND | 726-2ED2184S06FXUMA1
6 | 386760 | J211, J219, J421, J710, J715, X720 | 61300211121 | Wurth Elektronik | 61300211121 | Board-to-Board Header (male);2x1;Mounting:THT;Orient:0° (vertical);Shielded:No | Fitted | Connector |  |  | Farnell | DigiKey | Mouser | 2356153 | 732-5315-ND | 710-61300211121
1 | 638654 | L320 | 22uH | Wurth Elektronik | 74404064220 | Tol.:-20%/+20%;Rdc:89mR;Idc:2.1A;Fres:15MHz | Fitted | Inductor | SMD |  | Farnell | DigiKey | Mouser | 2431542 | 732-5554-1-ND | 710-74404064220
1 | 657324 | L420 | 27uH | Wurth Elektronik | 7447709270 | Tol.:-20%/+20%;Rdc:40mR;Idc:4.6A;Fres:8MHz | Fitted | Inductor | 1210 |  | Farnell | DigiKey | Mouser | 2211547 | 732-4121-1-ND | 710-7447709270
1 | 657326 | L421 | 15uH | Bourns | SRP6060FA-150M | Tol.:-20%/+20%;Rdc:43mR;Idc:5.8A;Fres:11MHz | Fitted | Inductor | 6.6 x 6.4 mm |  | Farnell | DigiKey | Mouser | 2901829 | SRP6060FA-150MCT-ND | 652-SRP6060FA-150M
4 | 455343 | MP100, MP101, MP102, MP103 | 0082 3 16 | Wurth Elektronik | 0082 3 16 | Steel Hexagonal 19x5.68 Screw | Fitted | Mechanical | THT |  | Farnell | DigiKey | Mouser
1 | 466242 | NTC | 10k | MuRata | NCP18XH103F03RB | TCR:-;Tol.:-1%/+1%;Vdc:-;Idc:-;P:100mW | Fitted | Resistor | 0603 |  | Farnell | DigiKey | Mouser | 2456122RL | 490-4800-2-ND | 81-NCP18XH103F03RB
2 | 584303 | PULL DOWN, PULL UP | IRFH5406TRPbF | Infineon Technologies | IRFH5406TRPbF | N-Channel Enhancement;Uds:60V;Id:40A;Rds:14.4R;P:46W | Fitted | Transistor FET | PQFN-5X6 |  | Farnell | DigiKey | Mouser | 2580010 | IRFH5406TRPBFCT-ND | 942-IRFH5406TRPBF
2 | 644075 | Q200, Q201 | IPD650P06NM | Infineon Technologies | IPD650P06NM | P-Channel Enhancement;Uds:-60V;Id:-22A;Rds:65R;P:83W | Fitted | Transistor FET | PG-TO252-3-313 |  | Farnell | DigiKey | Mouser | 3267848 | 448-IPD650P06NMATMA1CT-ND | 726-IPD650P06NMATMA1
5 | 615536 | Q202, Q500, Q501, Q502, Q503 | ISS17EP06LM | Infineon Technologies | ISS17EP06LM | P-Channel Enhancement;Uds:-60V;Id:-300mA;Rds:1.7R;P:360mW | Fitted | Transistor FET | PG-SOT23-3-5 |  | Farnell | DigiKey | Mouser | 3267800 | 448-ISS17EP06LMXTSA1CT-ND | 726-ISS17EP06LMXTSA1
3 | 691273 | Q741, Q800, Q801 | BSC0906NS | Infineon Technologies | BSC0906NS | N-Channel Enhancement;Uds:30V;Id:63A;Rds:4.5R;P:30W | Fitted | Transistor FET | TDSON-8 |  | Farnell | DigiKey | Mouser | 2480745 | BSC0906NSATMA1CT-ND | 726-BSC0906NS
8 | 354752 | R100, R101, R102, R122, R204, R506, R507, R528 | 100k | Vishay | CRCW1206100KFK | TCR:100ppm/K;Tol.:-1%/+1%;Vdc:200V;Idc:-;P:250mW | Fitted | Resistor | 1206 (3216) |  | Farnell | DigiKey | Mouser
10 | 354562 | R110, R111, R112, R200, R202, R203, R205, R209, R320, R564 | 47k | Vishay | CRCW120647K0FK | TCR:100ppm/K;Tol.:-1%/+1%;Vdc:200V;Idc:-;P:250mW | Fitted | Resistor | 1206 (3216) |  | Farnell | DigiKey | Mouser
1 | 647233 | R160 | 10k | Bourns | 3362P-1-103T_LF | TCR:100ppm/K;Tol.:-10%/+10%;Vdc:300V;Idc:-;P:500mW | Fitted | Resistor | THT |  | Farnell | DigiKey | Mouser | 1739325 | 3362P-103TLF-ND | 652-3362P-1-103TLF
4 | 352637 | R170, R400, R401, R720 | 20.5R | Vishay | CRCW120620R5FK | TCR:100ppm/K;Tol.:-1%/+1%;Vdc:200V;Idc:-;P:250mW | Fitted | Resistor | 1206 (3216) |  | Farnell | DigiKey | Mouser
14 | 354312 | R210, R212, R220, R301, R504, R510, R511, R551, R552, R553, R554, R560, R721, R814 | 17.8k | Vishay | CRCW120617K8FK | TCR:100ppm/K;Tol.:-1%/+1%;Vdc:200V;Idc:-;P:250mW | Fitted | Resistor | 1206 (3216) |  | Farnell | DigiKey | Mouser
2 | 644055 | R211, SHUNT | 15mR | Ohmite | L4T12FR015FER | TCR:75ppm/K;Tol.:-1%/+1%;Vdc:-;Idc:-;P:500mW | Fitted | Resistor | 1206 (3216) |  | Farnell | DigiKey | Mouser | 3274221 | 273-L4T12FR015FERCT-ND | 284-L4T12FR015FER
1 | 355322 | R214 | 1MEG | Vishay | CRCW12061M00FK | TCR:100ppm/K;Tol.:-1%/+1%;Vdc:200V;Idc:-;P:250mW | Fitted | Resistor | 1206 (3216) |  | Farnell | DigiKey | Mouser
1 |  | R219 |  |  |  |  | Fitted
12 | 353792 | R221, R302, R303, R508, R722, R800, R801, R802, R803, R804, R805, R806 | 2.2k | Vishay | CRCW12062K20FK | TCR:100ppm/K;Tol.:-1%/+1%;Vdc:200V;Idc:-;P:250mW | Fitted | Resistor | 1206 (3216) |  | Farnell | DigiKey | Mouser
12 | 353992 | R500, R501, R502, R503, R509, R527, R532, R561, R562, R565, R810, R812 | 4.7k | Vishay | CRCW12064K70FK | TCR:100ppm/K;Tol.:-1%/+1%;Vdc:200V;Idc:-;P:250mW | Fitted | Resistor | 1206 (3216) |  | Farnell | DigiKey | Mouser
5 | 354647 | R505, R632, R634, R811, R813 | 64.9k | Vishay | CRCW120664K9FK | TCR:100ppm/K;Tol.:-1%/+1%;Vdc:200V;Idc:-;P:250mW | Fitted | Resistor | 1206 (3216) |  | Farnell | DigiKey | Mouser
1 | 630020 | R569 | 10k | Bourns | 3361P-1-103GLF | TCR:100ppm/K;Tol.:-10%/+10%;Vdc:-;Idc:-;P:500mW | Fitted | Resistor | SMD |  | Farnell | DigiKey | Mouser | 1696060 | 3361P-103GLFCT-ND | 652-3361P-1-103GLF
2 | 353672 | R631, R633 | 1.3k | Vishay | CRCW12061K30FK | TCR:100ppm/K;Tol.:-1%/+1%;Vdc:200V;Idc:-;P:250mW | Fitted | Resistor | 1206 (3216) |  | Farnell | DigiKey | Mouser
4 | 380147 | S110, S560, S810, S812 | 1301.9314 | Schurter | 1301.9314 |  | Fitted | Electro Mechanic |  |  | Farnell | DigiKey | Mouser | 1217763 | 1301.9314-ND | 693-1301.9314
6 | 650099 | S122, S200, S800, S801, S802, S814 | CL-SB-12A-01T | NIDEC COPAL ELECTRONICS, Inc. | CL-SB-12A-01T |  | Fitted | Electro Mechanic |  |  | Farnell | DigiKey | Mouser | 2854744 | 563-1314-1-ND | 229-CL-SB-12A-01T
6 | 382410 | TP100, TP101, TP102, TP103, TP104, TP105 | 5011 | Keystone Electronics Corp. | 5011 | Board-to-Cable None (onboard);1x1;Mounting:THT;Orient:0° (vertical);Shielded:No | Fitted | Connector |  |  | Farnell | DigiKey | Mouser | 2431148 | 36-5011-ND | 534-5011
15 | 382400 | TP211, TP300, TP310, TP320, TP400, TP532, TP600, TP630, UserPot1, VOUT, VS BUCK, X801, X805, X806, X808 | 5010 | Keystone Electronics Corp. | 5010 | Board-to-Cable None (onboard);1x1;Mounting:THT;Orient:0° (vertical);Shielded:No | Fitted | Connector |  |  | Farnell | DigiKey | Mouser | 2301288 | 36-5010-ND | 534-5010
1 | 409035 | U520 | LM339PWR | Texas Instruments | LM339PWR | Res.:-;Fmax:- | Fitted | Analog Parts | TSSOP-14 (PW) |  | Farnell | DigiKey | Mouser | 2436009 | 296-6607-2-ND | 595-LM339PWR
1 | 648079 | U540 | HEF4043BT,653 | Nexperia | HEF4043BT,653 | - Digital;Vdc min/max:3V/15V;Iout:2.4mA;Fmax:- | Fitted | Integrated Circuit | SO-16 |  | Farnell | DigiKey | Mouser |  | 1727-1799-1-ND | 771-HEF4043BT653
1 | 699374 | U630 | OPA197IDR | Texas Instruments | OPA197IDR | Res.:-;Fmax:10MHz | Fitted | Analog Parts | SOIC |  | Farnell | DigiKey | Mouser | 3117357 | 296-43866-1-ND | 595-OPA197IDR
1 | 377341 | X100 | 973 582-101 | Hirschmann Test & Measurement | 973 582-101 | Board-to-Cable Socket (female);2x1;Mounting:THT;Orient:90° (right angle);Shielded:No | Fitted | Connector |  |  | Farnell | DigiKey | Mouser | 497332 |  | 845-973582101
1 | 377401 | X101 | 973 582-100 | Hirschmann Test & Measurement | 973 582-100 | Board-to-Cable Socket (female);-x-;Mounting:THT;Orient:90° (right angle);Shielded:No | Fitted | Connector |  |  | Farnell | DigiKey | Mouser | 497344 |  | 845-973582100
1 | 433601 | X105 | Solder Jumper 2 Pins | Infineon Technologies | Solder Jumper 2 Pins | - None (onboard);2x1;Mounting:SMT;Orient:None (onboard);Shielded:No | Fitted | Connector |  |  | Farnell | DigiKey | Mouser
1 | 644888 | X110 | Arduino-Uno | Infineon Technologies | Arduino-Uno | Board-to-Board Socket (female);-x-;Mounting:THT;Orient:0° (vertical);Shielded:- | Fitted | Connector | THT |  | Farnell | DigiKey | Mouser
1 | 382944 | X140 | TSW-110-07-L-S | Samtec | TSW-110-07-L-S | Board-to-Board Header (male);10x1;Mounting:THT;Orient:0° (vertical);Shielded:No | Fitted | Connector |  |  | Farnell | DigiKey | Mouser | 2035612 | SAM1031-10-ND
1 | 382934 | X150 | TSW-108-07-L-S | Samtec | TSW-108-07-L-S | Board-to-Board Header (male);8x1;Mounting:THT;Orient:0° (vertical);Shielded:No | Fitted | Connector |  |  | Farnell | DigiKey | Mouser | 2035610 | SAM1031-08-ND
1 | 638630 | X150 | 61201021621 | Wurth Elektronik | 61201021621 | Board-to-Board/Cable Header (male);5x2;Mounting:THT;Orient:0° (vertical);Shielded:No | Fitted | Connector | THT |  | Farnell | DigiKey | Mouser | 1642019 | 732-2094-ND | 710-61201021621
1 | 614137 | X400 | SSW-102-01-G-S | Samtec | SSW-102-01-G-S | Board-to-Board/Cable Socket (female);2x1;Mounting:THT;Orient:0° (vertical);Shielded:Yes | Fitted | Connector | THT |  | Farnell | DigiKey | Mouser | 200-SSW10201GS | SAM1209-02-ND | 1668331

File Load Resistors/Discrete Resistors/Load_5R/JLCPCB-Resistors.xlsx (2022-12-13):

Widerstand Gesamt | Widersand Einzeln | Bestellnummer | Toleranz | Preis in ct | Gesamtpreis pro Last (bei 10 Stück)
3.96 | 2.2 | C25480 | 5% | 1.53 | 6.885
19.8 | 11 | C30206 | 1% | 2.08 | 9.36
3.6 | 2 | C49298 | 1% | 2.53 | 11.385
21.6 | 12 | C32443 | 5% | 0.98 | 4.41
21.6 | 12 | C30210 | 1% | 2.02 | 9.09

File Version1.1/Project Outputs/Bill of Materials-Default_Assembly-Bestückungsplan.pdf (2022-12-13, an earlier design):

Quantity | Designator | Value | Manufacturer | Manufacturer Order Number | Part Type | SheetNumber
2 | U500, U520 | LM339PWR | Texas Instruments | LM339PWR | Analog Parts | 6
1 | U501 | MCP6567-E/MS | Microchip Technology | MCP6567-E/MS | Analog Parts | 6
1 | U600 | MAX4073FAUT+T | Maxim Integrated Products | MAX4073FAUT+T | Analog Parts | 7
1 | U610 | MAX40056TAUA+ | Maxim Integrated Products | MAX40056TAUA+ | Analog Parts | 7
1 | U620 | INA180A1IDBVR | Texas Instruments | INA180A1IDBVR | Analog Parts | 7
1 | U630 | TLV197QDGKRQ1 | Texas Instruments | TLV197QDGKRQ1 | Analog Parts | 7
3 | C204, C411, C441 | 10nF | TDK Corporation | C1608X8R1H103K080AA | Capacitor | 3, 5
Don't place | C210 | 1mF | Kemet | ESY108M035AL4AA | Capacitor | 3
3 | C211, C702, C710 | 220uF | Wurth Elektronik | 865080657018 | Capacitor | 3, 8
8 | C212, C300, C313, C404, C434, C701, C712, C713 | 10uF | Taiyo Yuden | UMK316BBJ106ML-T | Capacitor | 3, 4, 5, 8
40 | C213, C214, C215, C301, C302, C311, C312, C400, C402, C403, C410, C430, C432, C433, C440, C500, C501, C503, C505, C510, C514, C520, C523, C526, C530, C533, C540, C562, C570, C600, C610, C620, C630, C700, C750, C751, C752, C811, C813, C814 | 100nF | AVX | 06035C104KAT2A | Capacitor | 3, 4, 5, 6, 7, 8, 9
5 | C221, C412, C442, C722, C723 | 1nF | Wurth Elektronik | 885012206083 | Capacitor | 3, 5, 8
1 | C303 | 22uF | Taiyo Yuden | TMK325BJ226KM-P | Capacitor | 4
5 | C310, C405, C435, C506, C507 | 2.2uF | MuRata | GRM188R61E225KA12D | Capacitor | 4, 5, 6
Don't place | C511, C515 | 22pF | AVX | 06035A220K4T2A | Capacitor | 6
1 | C711 | 47uF | Wurth Elektronik | 865080645012 | Capacitor | 8
1 | JP110 | 61301221121 | Wurth Elektronik | 61301221121 | Connector | 2
1 | JP111 | 61302021121 | Wurth Elektronik | 61302021121 | Connector | 2
1 | JP112 | 61301621121 | Wurth Elektronik | 61301621121 | Connector | 2
7 | JP120, JP121, JP122, JP123, JP124, JP128, JP130 | 61300311121 | Wurth Elektronik | 61300311121 | Connector | 2
5 | JP125, JP126, JP127, X720, X723 | 61300211121 | Wurth Elektronik | 61300211121 | Connector | 2, 8
1 | JP710 | 61300621121 | Wurth Elektronik | 61300621121 | Connector | 8
7 | TP103, TP202, TP300, TP421, TP503, TP710, TP802 | 5011 | Keystone Electronics Corp. | 5011 | Connector | 2, 3, 4, 5, 6, 8, 9
44 | TP200, TP201, TP203, TP205, TP210, TP220, TP400, TP401, TP411, TP412, TP430, TP431, TP441, TP442, TP500, TP501, TP502, TP504, TP506, TP507, TP508, TP511, TP520, TP522, TP525, TP526, TP528, TP532, TP540, TP541, TP542, TP543, TP570, TP600, TP601, TP602, TP610, TP611, TP612, TP620, TP621, TP622, TP630, TP721 | S1751-46R | Harwin | S1751-46R | Connector | 3, 5, 6, 7, 8
4 | X100, X101, X102, X103 | 575-8 | Keystone Electronics Corp. | 575-8 | Connector | 2
1 | X140 | 61301211121 | Wurth Elektronik | 61301211121 | Connector | 2
1 | X150 | 61201021621 | Wurth Elektronik | 61201021621 | Connector | 2
3 | D110, D111, D112 | BAT54-05W | Infineon | BAT54-05W | Diode | 2
3 | D200, D201, D202 | 12V | Nexperia | BZX84-C12,215 | Diode | 3
1 | D203 | 20V | Nexperia | BZX84-C20,215 | Diode | 3
1 | D211 | SMDJ20A | Littelfuse | SMDJ20A | Diode | 3
14 | D320, D330, D340, D550, D551, D552, D553, D741, D743, D745, D801, D803, D805, D807 | Red | Wurth Elektronik | 150060RS75000 | Diode | 4, 6, 8, 9

Quantity | Designator | Value | Manufacturer | Manufacturer Order Number | Part Type | SheetNumber
12 | D402, D404, D405, D411, D432, D434, D435, D441, D442, D443, D511, D515 | BAS70-04 | Infineon | BAS70-04 | Diode | 5, 6
3 | D410, D433, D440 | 15V | Nexperia | BZX84-C15,215 | Diode | 5
4 | D620, D740, D742, D744 | BAT54-06W | Infineon | BAT54-06W | Diode | 7, 8
1 | D730 | SMC5K40A-M3/I | Vishay | SMC5K40A-M3/I | Diode | 8
1 | D731 | PMEG6030ETPX | Nexperia | PMEG6030ETPX | Diode | 8
4 | S110, S560, S810, S812 | 1301.9314 | Schurter | 1301.9314 | Electro Mechanic | 2, 6, 9
5 | S200, S750, S751, S752, S814 | CL-SB-12A-01T | NIDEC COPAL ELECTRONICS, Inc. | CL-SB-12A-01T | Electro Mechanic | 3, 8, 9
1 | L420 | 27uH | Wurth Elektronik | 7447709270 | Inductor | 5
1 | L421 | 15uH | Bourns | SRP6060FA-150M | Inductor | 5
1 | D204 | ATL431AQDBZR | Texas Instruments | ATL431AQDBZR | Integrated Circuit | 3
2 | U410, U440 | ICM7555IBAZ | Renesas | ICM7555IBAZ | Integrated Circuit | 5
1 | U540 | HEF4043BT,653 | Nexperia | HEF4043BT,653 | Integrated Circuit | 6
1 | U570 | 74HC4002PW,118 | Nexperia | 74HC4002PW,118 | Integrated Circuit | 6
1 | G300 | TLE42764GV | Infineon | TLE42764GV | Power Supply | 4
1 | G310 | TLE4266-2GS V33 | Infineon | TLE4266-2GS V33 | Power Supply | 4
2 | U400, U430 | IRS2184SPBF | Infineon | IRS2184SPBF | Power Supply | 5
4 | R103, R211, R420, R421 | 15mR | Ohmite | L4T12FR015FER | Resistor | 2, 3, 5
22 | R110, R111, R112, R130, R200, R202, R203, R205, R209, R220, R411, R441, R503, R504, R508, R512, R521, R528, R800, R802, R804, R806 | 47k | Vishay | CRCW060347K0FK | Resistor | 2, 3, 5, 6, 9
9 | R122, R123, R173, R505, R506, R507, R740, R742, R744 | 100k | Vishay | CRCW0603100KFK | Resistor | 2, 6, 8
8 | R124, R131, R132, R410, R440, R631, R633, R722 | 1.3k | Vishay | CRCW06031K30FK | Resistor | 2, 5, 7, 8
4 | R160, R524, R531, R611 | 10k | Bourns | 3361P-1-103GLF | Resistor | 2, 6, 7
15 | R170, R207, R300, R320, R330, R500, R522, R529, R621, R622, R721, R741, R743, R745, R814 | 17.8k | Vishay | CRCW060317K8FK | Resistor | 2, 3, 4, 6, 7, 8, 9
6 | R171, R400, R401, R430, R431, R720 | 20R | Vishay | CRCW060320R0FK | Resistor | 2, 5, 8
24 | R172, R221, R301, R404, R405, R434, R501, R502, R510, R511, R514, R515, R520, R523, R525, R527, R530, R532, R561, R750, R751, R752, R810, R812 | 4.7k | Vishay | CRCW06034K70FK | Resistor | 2, 3, 4, 5, 6, 8, 9
2 | R204, R208 | 2MEG | Vishay | CRCW06032M00FK | Resistor | 3
6 | R206, R562, R632, R634, R811, R813 | 64.9k | Vishay | CRCW060364K9FK | Resistor | 3, 6, 7, 9
12 | R340, R402, R403, R435, R550, R551, R552, R553, R801, R803, R805, R807 | 2.2k | Vishay | CRCW06032K20FK | Resistor | 4, 5, 6, 9
Don't place | R509, R513 | 100k | Vishay | CRCW0603100KFK | Resistor | 6
1 | R526 | 10k | MuRata | NCP18XH103F03RB | Resistor | 6
13 | Q124, Q130, Q550, Q551, Q552, Q553, Q740, Q742, Q744, Q800, Q802, Q804, Q806 | BSS816NW | Infineon | BSS816NW | Transistor FET | 2, 6, 8, 9
2 Q170, Q202 | | BSS84PH6327XTSA 2 | Infineon | BSS84PH6327XTSA2 | Transistor FET | 2, 3
2 | Q200, Q201 | IPD650P06NM | Infineon | IPD650P06NM | Transistor FET | 3
7 | Q400, Q401, Q430, Q431, Q741, Q743, Q745 | BSZ100N06NS | Infineon | BSZ100N06NS | Transistor FET | 5, 8

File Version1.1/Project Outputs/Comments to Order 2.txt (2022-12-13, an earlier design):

Spares from first V1.1 order: 
8x ATL431
8x 27uH 
8x 15uH
3x Shunt
6x IRS2184

Deleted in new Order because of new order: ATL431, 27uH Inductor, IRS2184
Deleted because spares from V1.0 available: SMDJ20A, BAT54-05, 74HC4002PW, MCP6567, SMDJ20A

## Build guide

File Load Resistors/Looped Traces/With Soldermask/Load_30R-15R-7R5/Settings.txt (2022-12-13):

FILENAME = "output.txt"                     # Output file
NETNAMES = ["net 3", "net 3", "net 3"]      # Net names for the load resitors

# Thickness of the individual load resitors. Add more entries to generate more resistors
THICKNESS = [0.163, 0.257, 0.395]

# Board Specific
BOARDX = 100  # Board dimensions
BOARDY = 100
OFFSETX = 50  # Offset refers to top left corner
OFFSETY = 50
CLEARANCE = 0.15  # Between traces of the same net
LOAD_CLEARANCE = 0.2  # Between traces of different nets (how much do you trust the manufacturer?)
OUTLINE_CLEARANCE = 0.3  # Between traces and the edge
COPPER_THICKNESS = 35e-6  # Thickness of the copper layer

# Keepouts
# There are keepouts in each edge for mounting holes and a keepout in the top center for a connector
# You have to add clearance by yourself!
SCREW_KEEPOUT = 7.5  # Square keepout in the corners for the screw
CONNECTOR_KEEPOUT_X = 6.5  # 1/2 of the width of the connector
CONNECTOR_KEEPOUT_Y = 7.5  # Height of the connector

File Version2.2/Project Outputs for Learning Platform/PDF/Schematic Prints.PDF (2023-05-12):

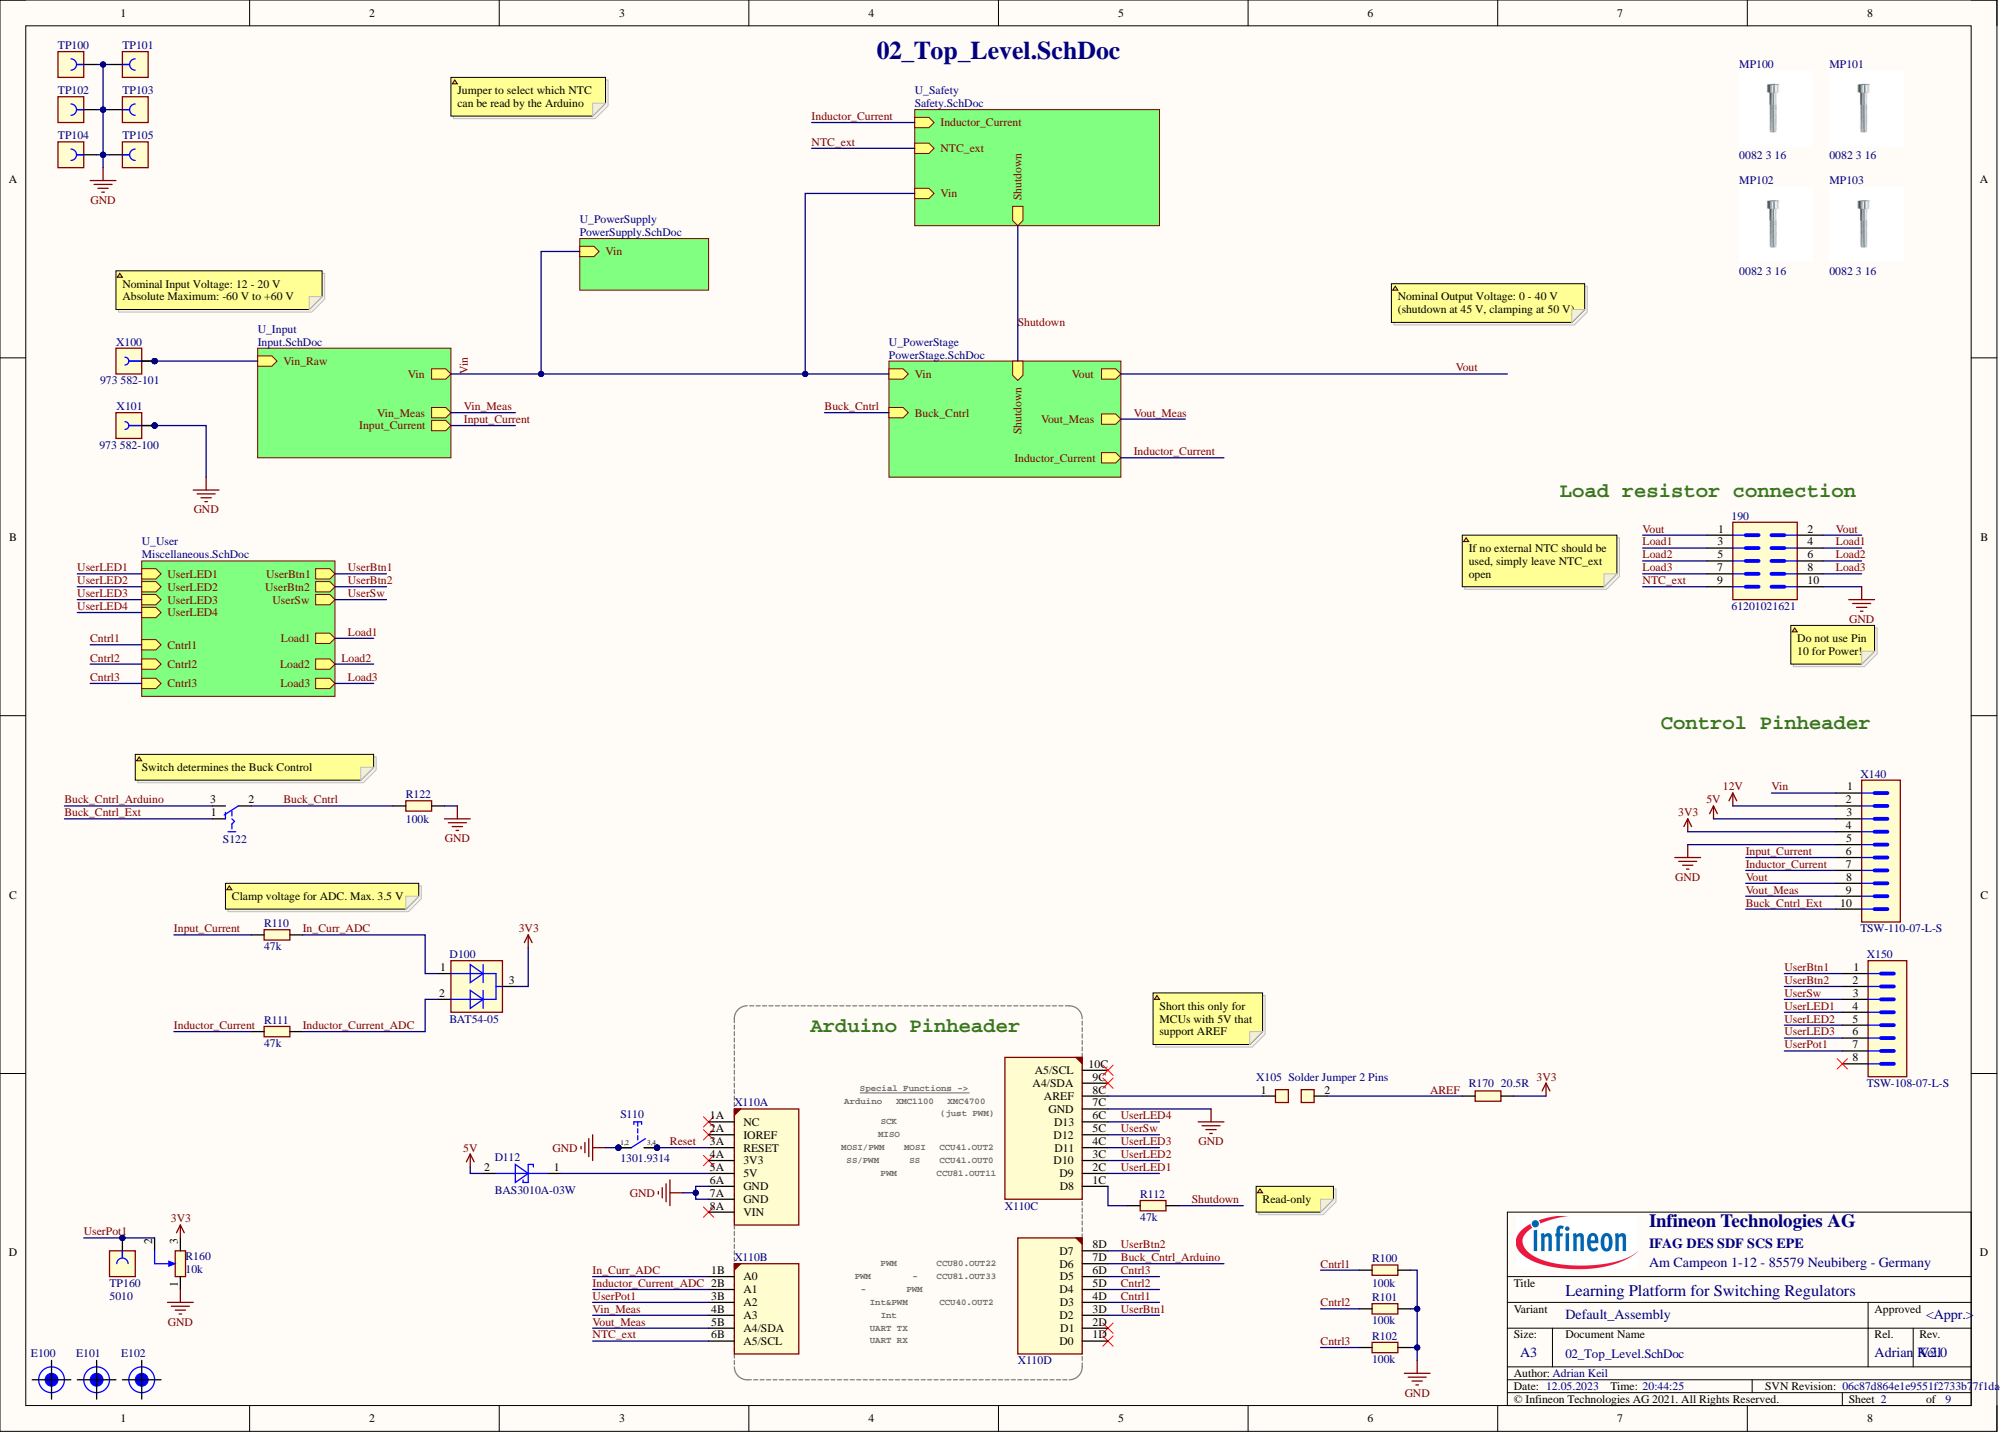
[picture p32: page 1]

Jumper to select which NTC
can be read by the Arduino

(shutdown at 45 V, clamping at 50 V)

If no external NTC should be
used, simply leave NTC_ext
open

Do not use Pin
10 for Power!

Switch determines the Buck Control

Clamp voltage for ADC. Max. 3.5 V

Short this only for
MCUs with 5V that
support AREF

Infineon Technologies AG
IFAG DES SDF SCS EPE
Am Campeon 1-12 - 85579 Neubiberg - Germany

Learning Platform for Switching Regulators

Date: 12.05.2023 Time: 20:44:25
© Infineon Technologies AG 2021. All Rights Reserved. | Sheet of

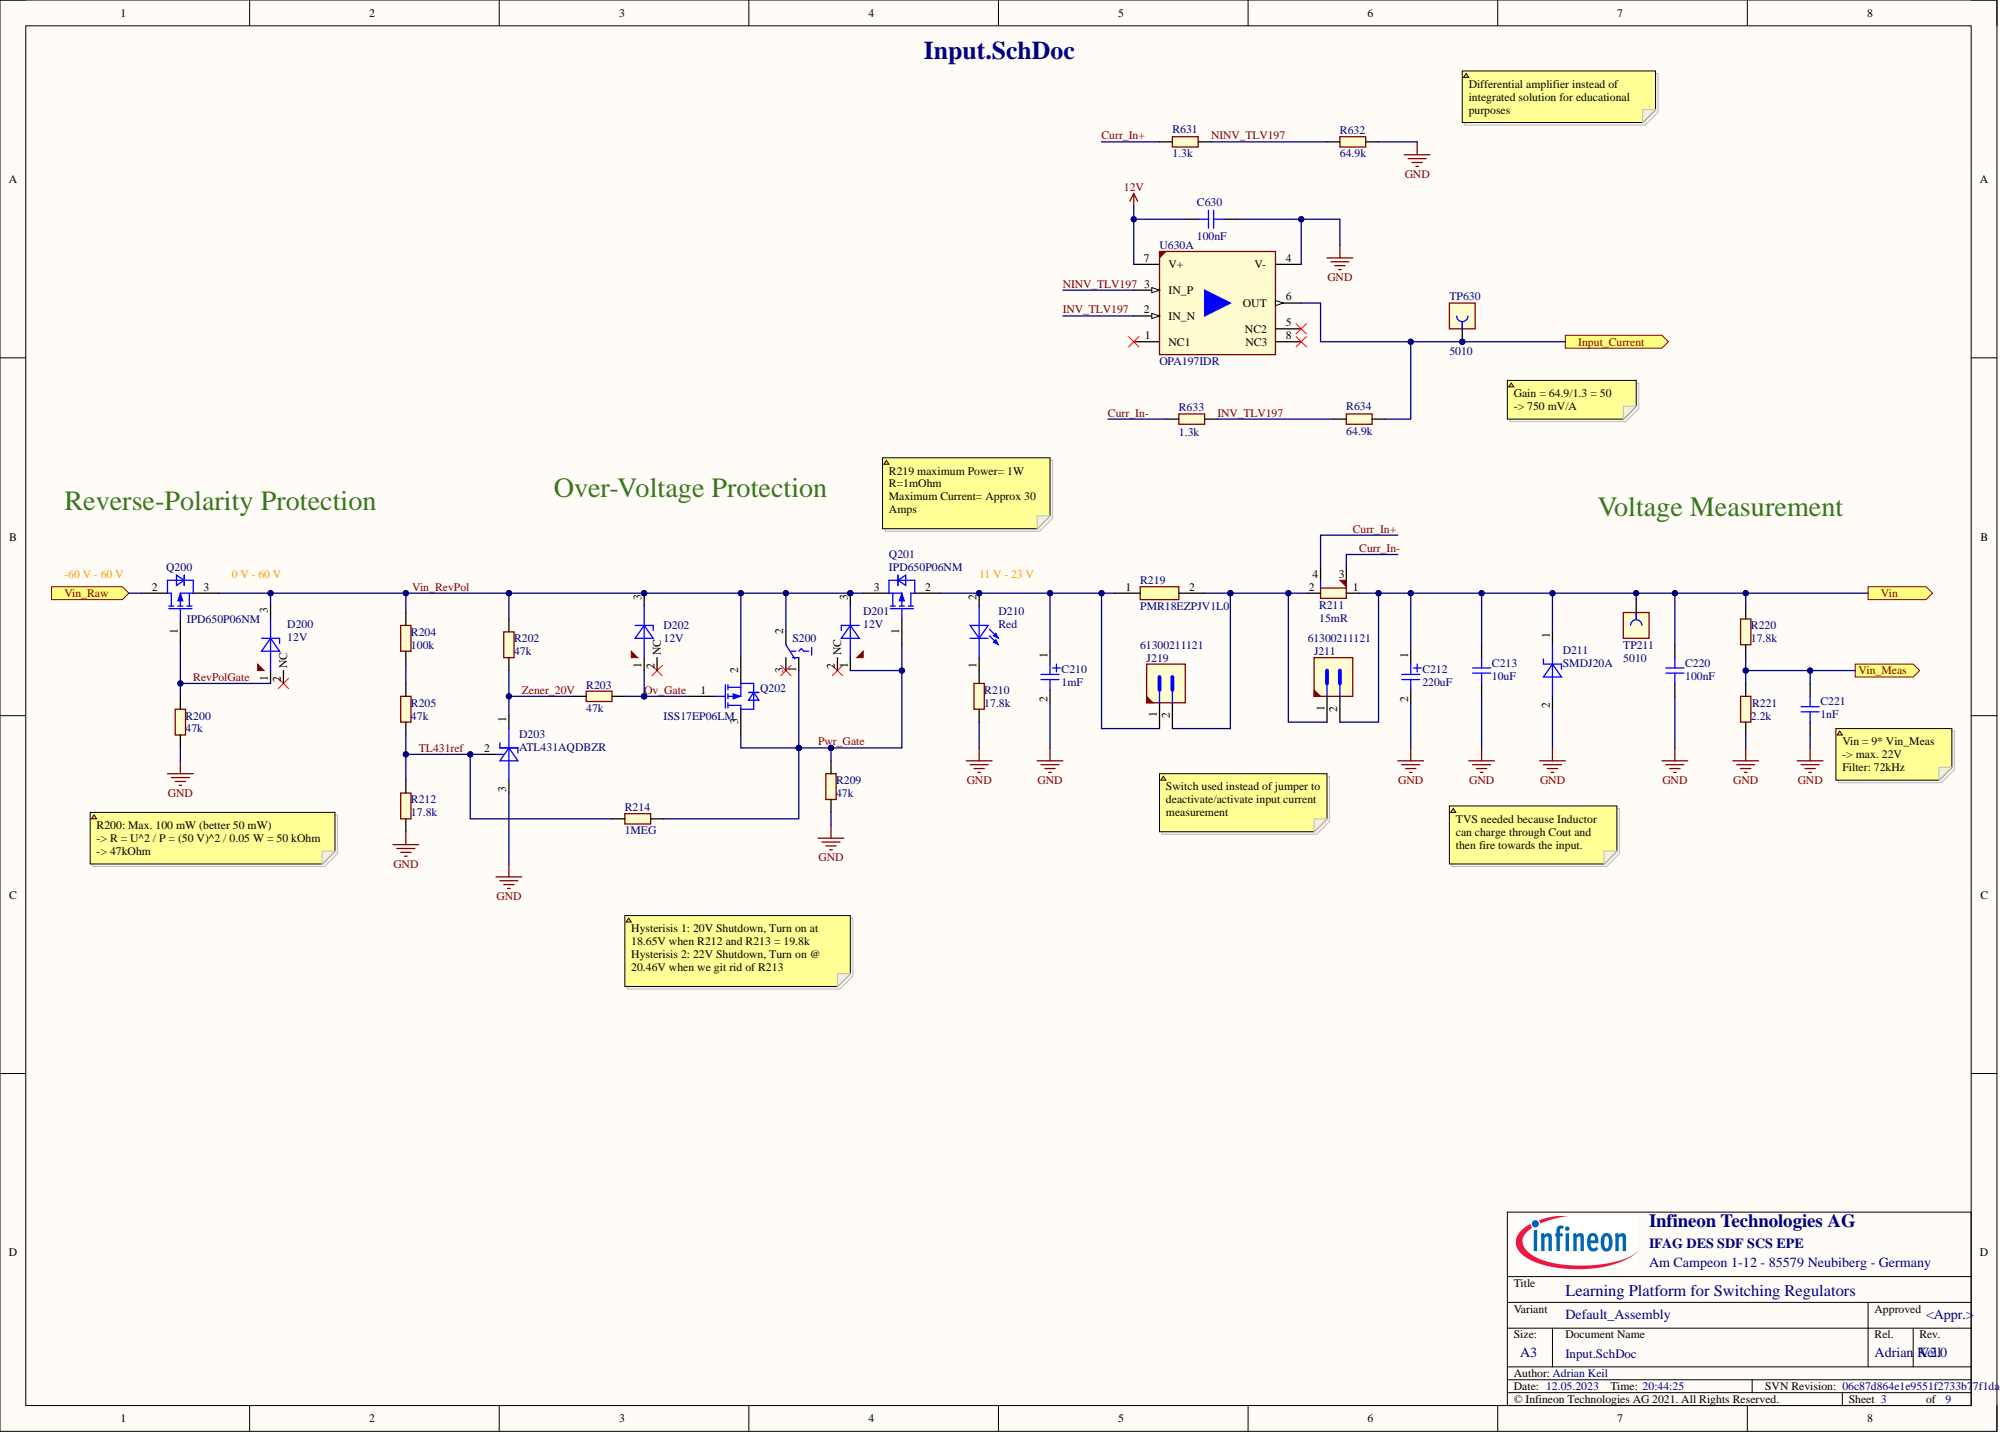
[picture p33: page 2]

Differential amplifier instead of
integrated solution for educational
purposes

Switch used instead of jumper to
deactivate/activate input current
measurement

TVS needed because Inductor
can charge through Cout and
then fire towards the input.

Hysterisis 1: 20V Shutdown, Turn on at
18.65V when R212 and R213 = 19.8k
Hysterisis 2: 22V Shutdown, Turn on @
20.46V when we git rid of R213

Infineon Technologies AG
IFAG DES SDF SCS EPE
Am Campeon 1-12 - 85579 Neubiberg - Germany

Learning Platform for Switching Regulators

Variant Default_Assembly | Approved <Appr.>

Input.SchDoc

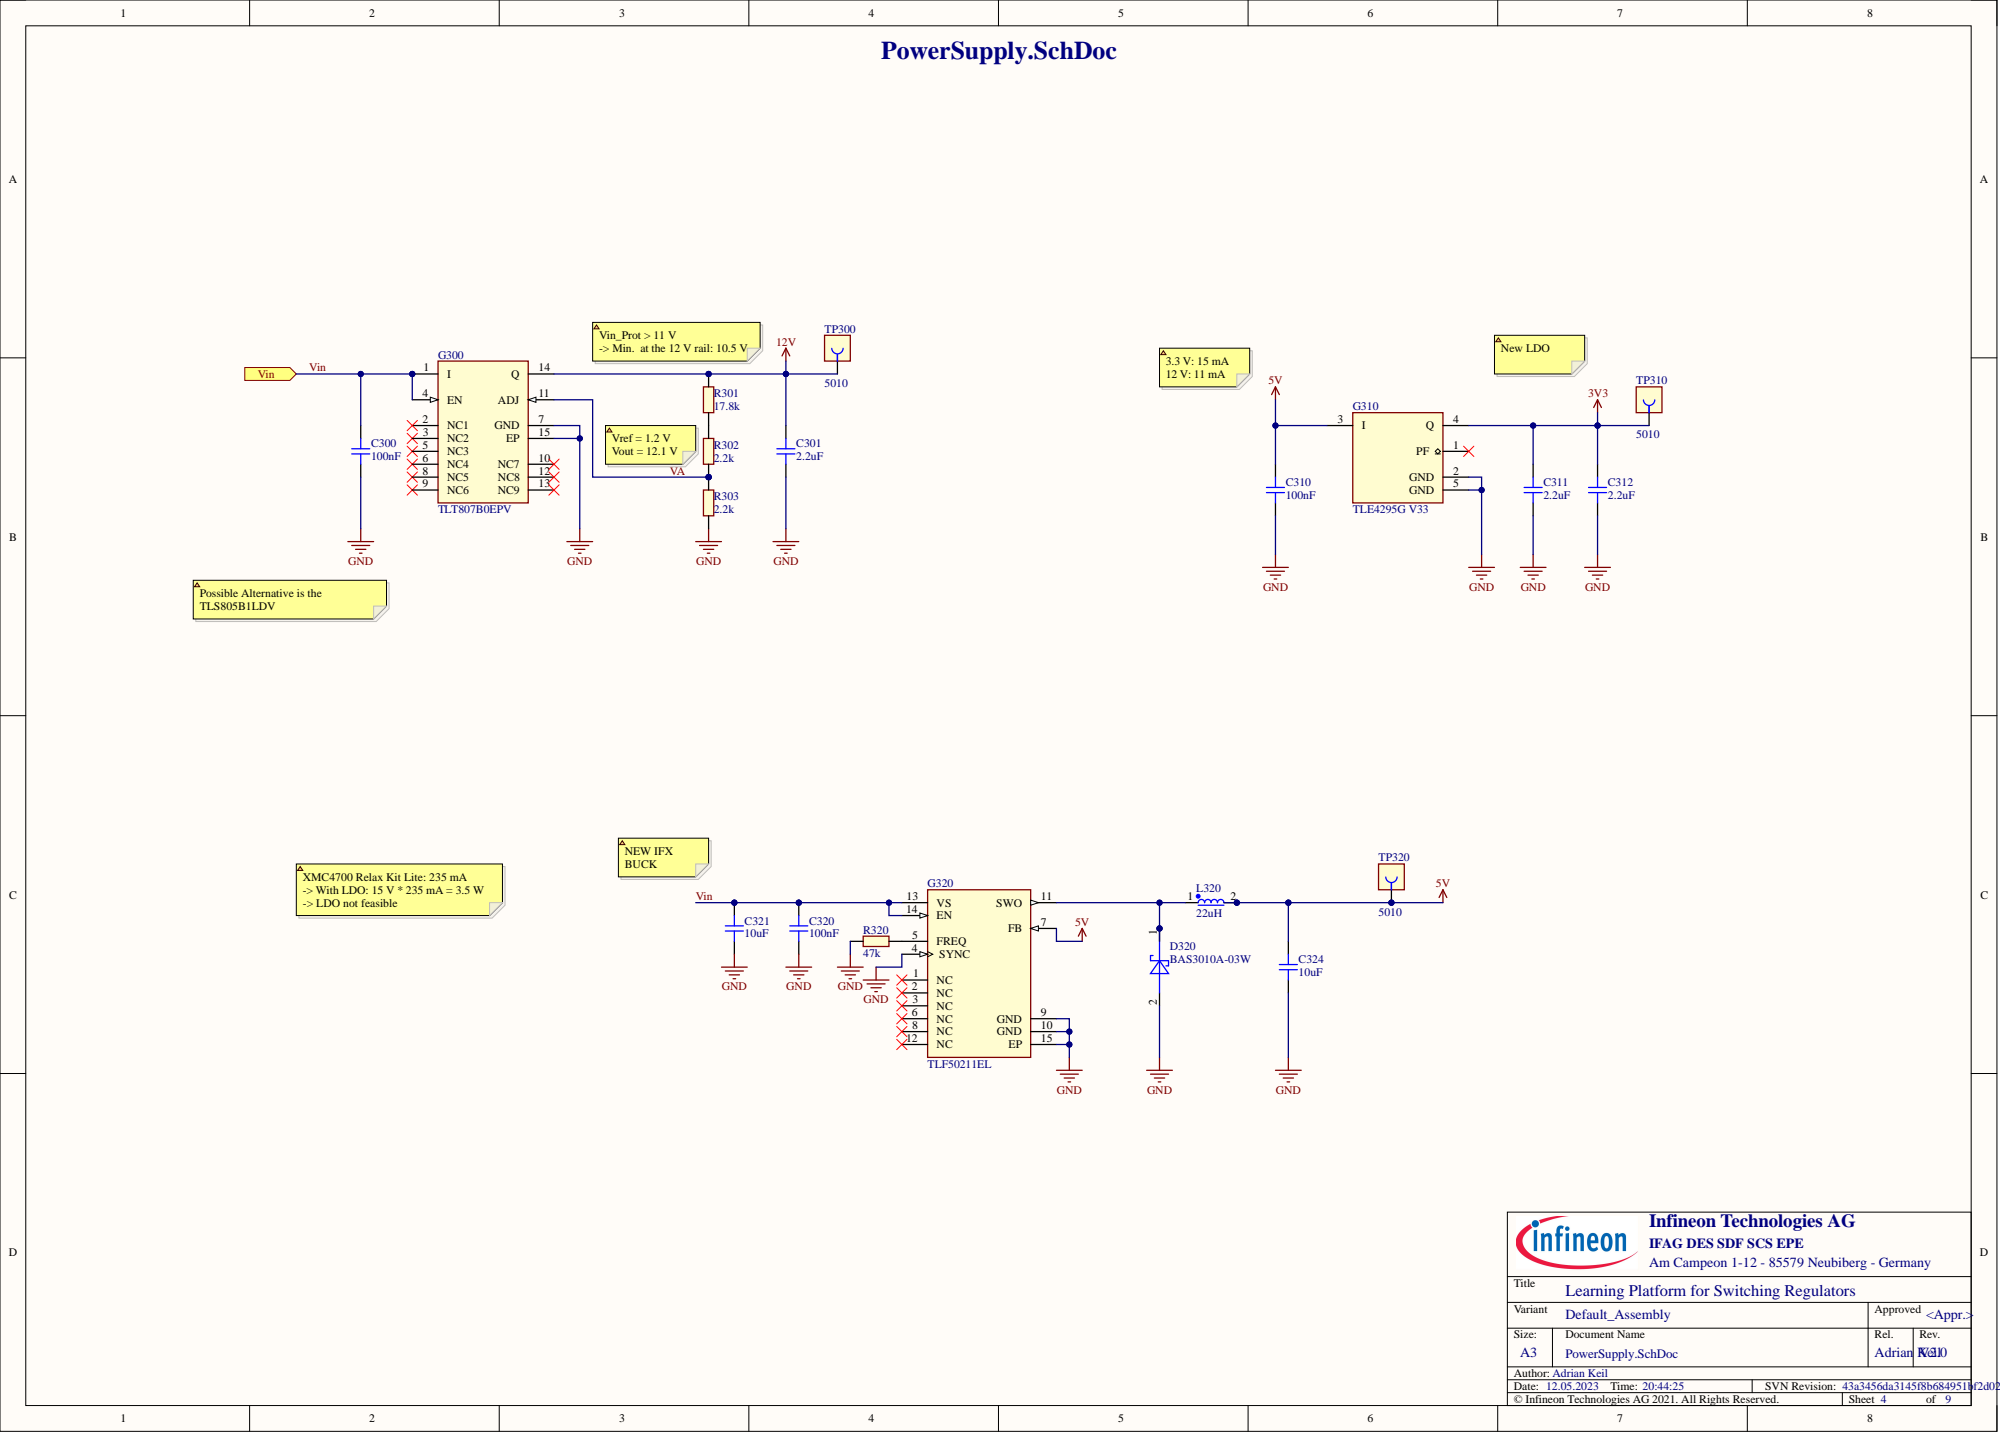
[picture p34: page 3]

Vin_Prot > 11 V
-> Min. at the 12 V rail: 10.5 V

Possible Alternative is the
TLS805B1LDV

XMC4700 Relax Kit Lite: 235 mA
-> With LDO: 15 V * 235 mA = 3.5 W
-> LDO not feasible

Infineon Technologies AG
IFAG DES SDF SCS EPE
Am Campeon 1-12 - 85579 Neubiberg - Germany

Learning Platform for Switching Regulators

Variant Default_Assembly | Approved <Appr.>

PowerSupply.SchDoc

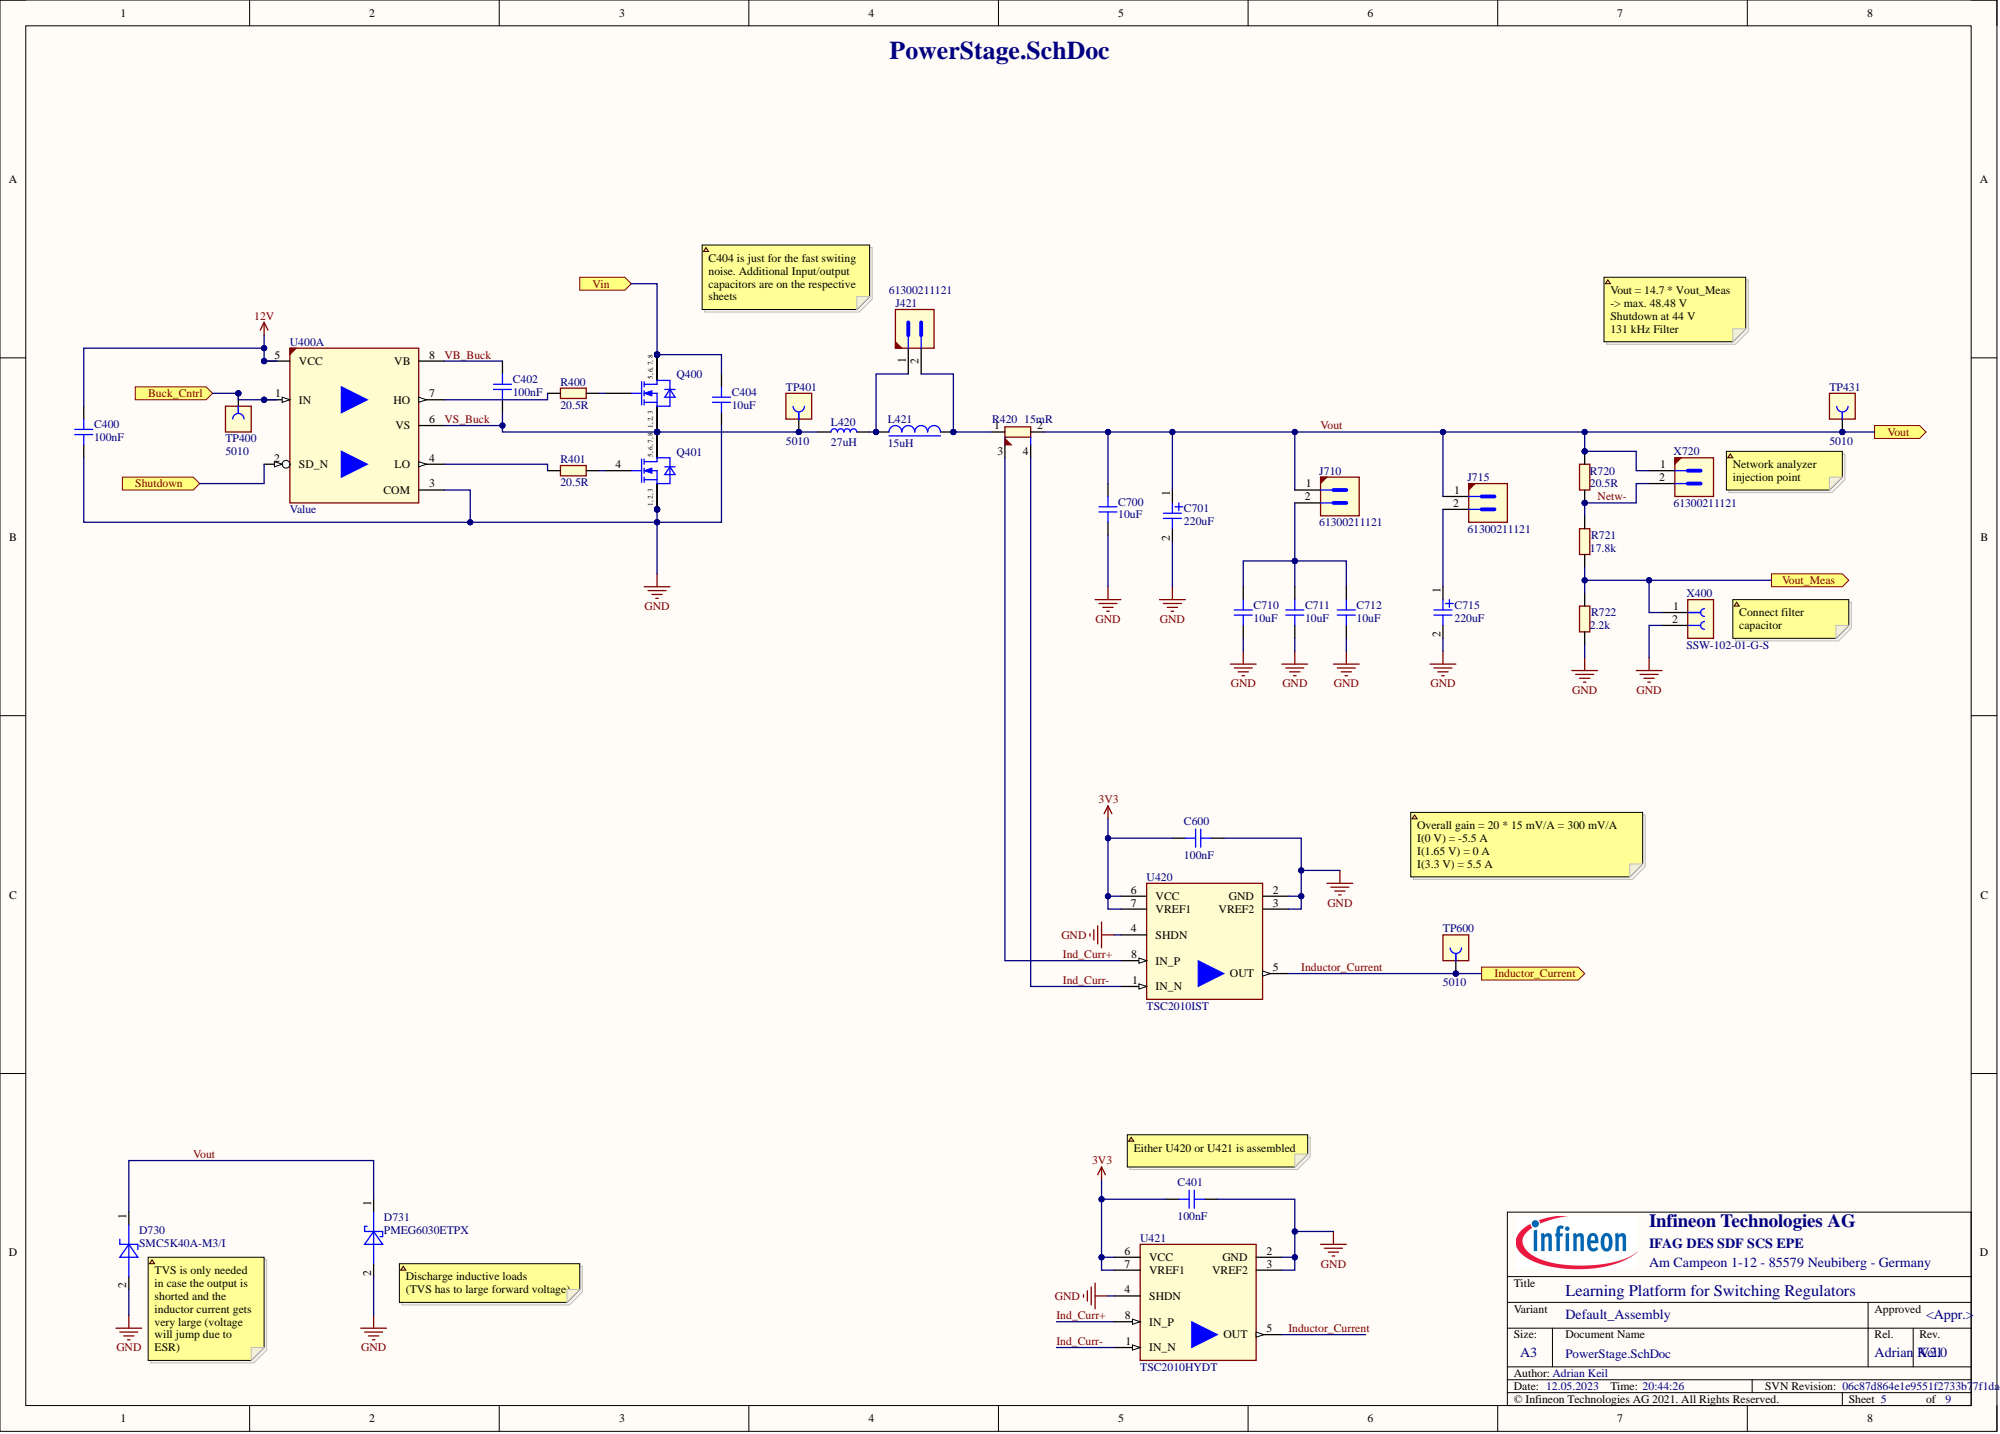
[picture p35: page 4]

C404 is just for the fast switing
noise. Additional Input/output
capacitors are on the respective
sheets

Either U420 or U421 is assembled

Infineon Technologies AG
IFAG DES SDF SCS EPE
Am Campeon 1-12 - 85579 Neubiberg - Germany

TVS is only needed
in case the output is
shorted and the
inductor current gets
very large (voltage
will jump due to
ESR)

Discharge inductive loads
(TVS has to large forward voltage)

Learning Platform for Switching Regulators

Variant Default_Assembly | Approved <Appr.>

PowerStage.SchDoc

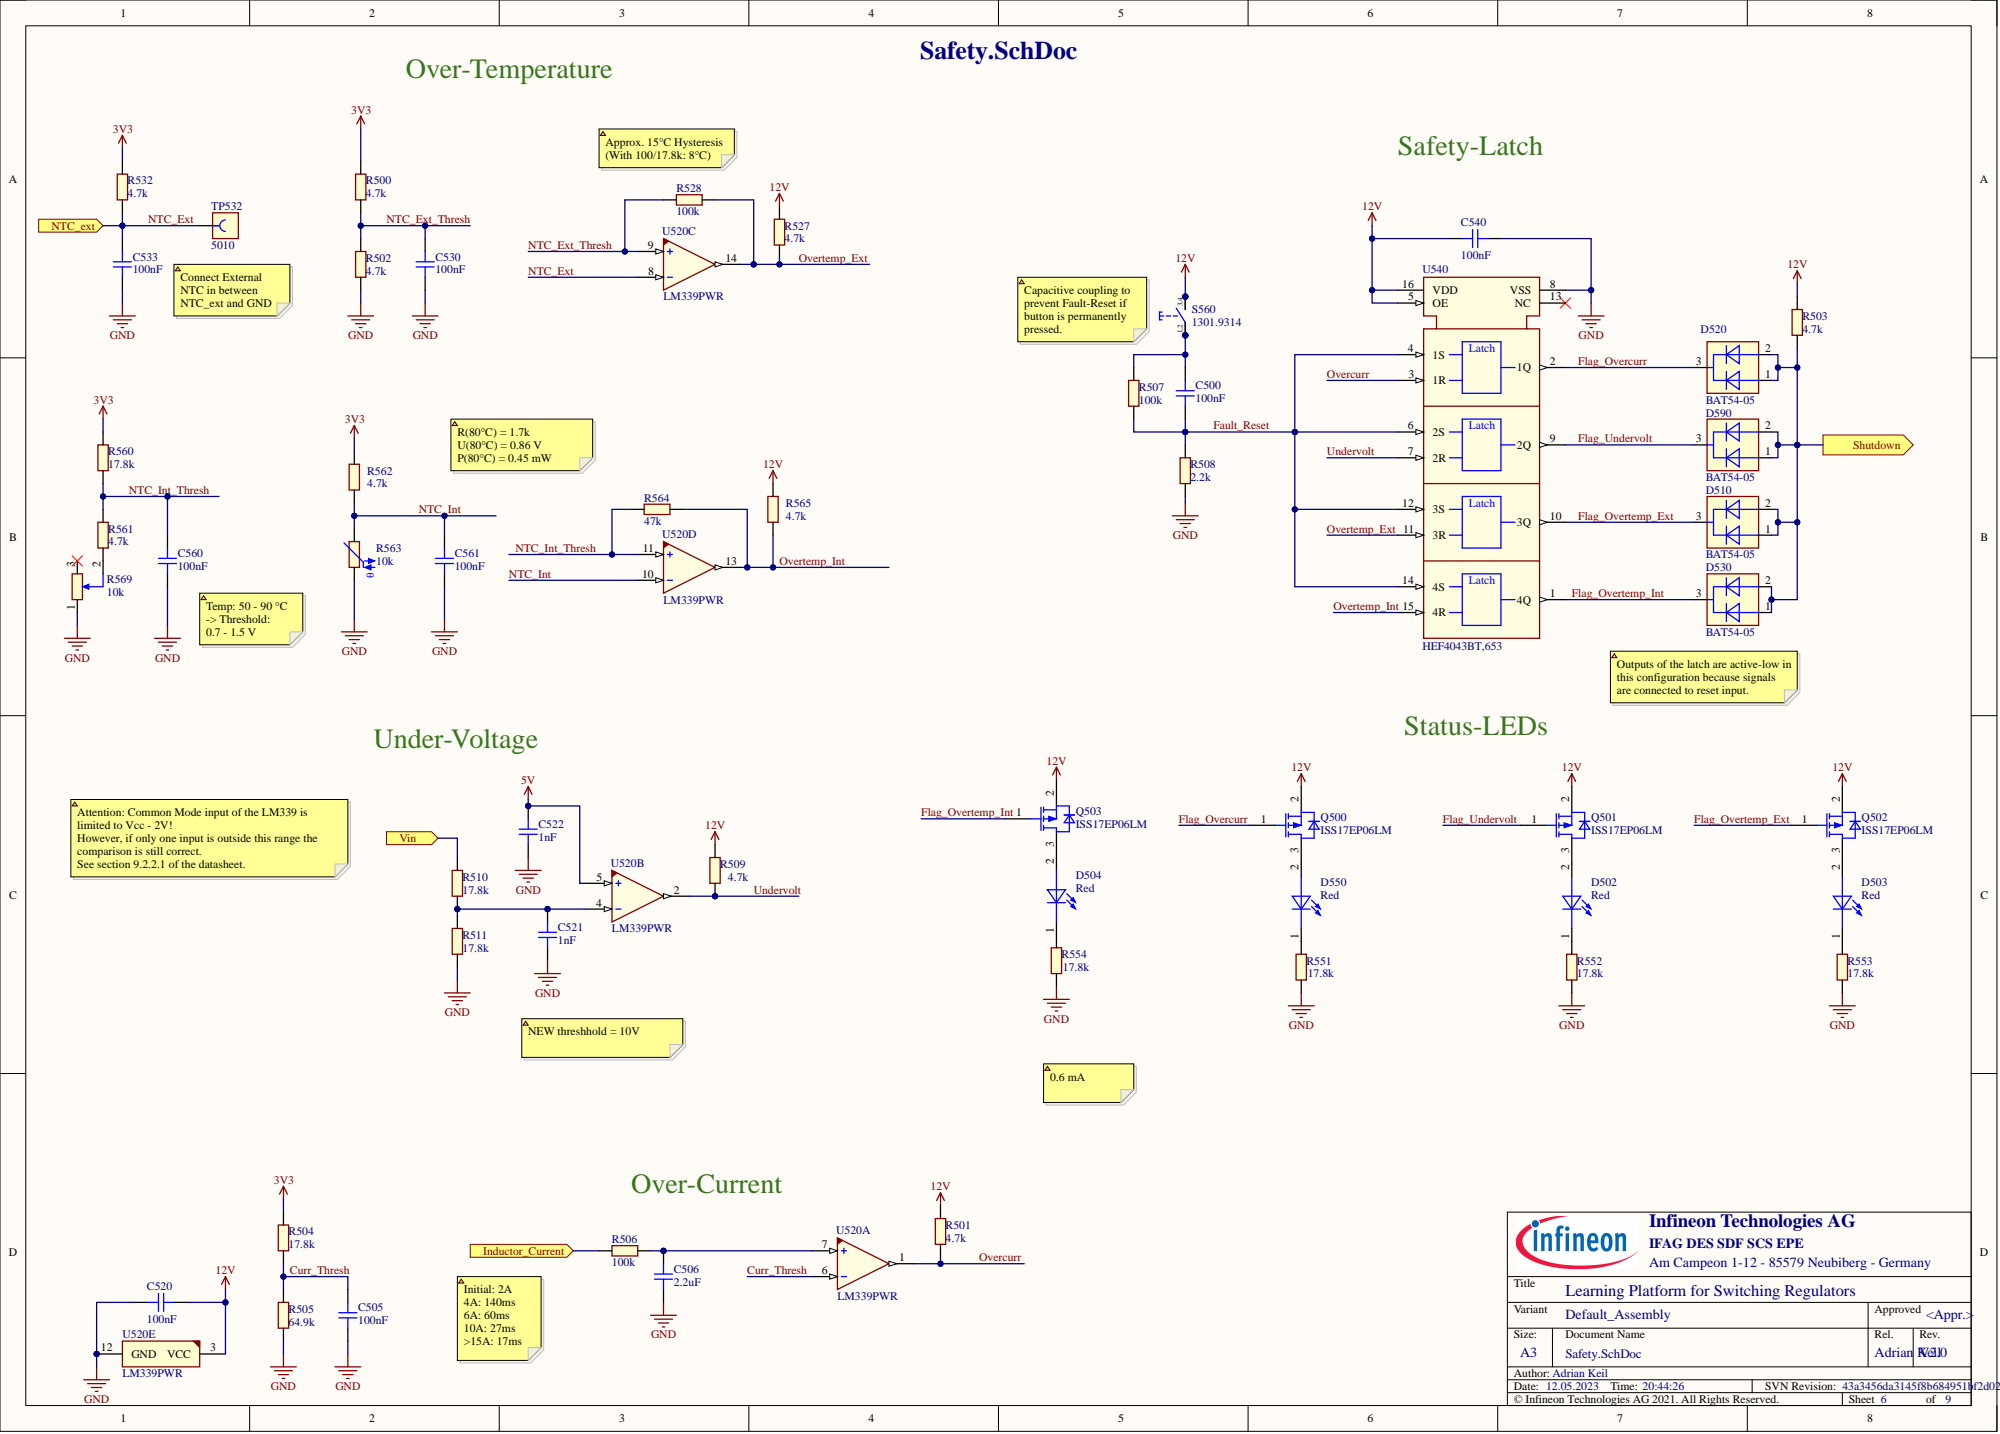
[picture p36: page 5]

Capacitive coupling to
prevent Fault-Reset if
button is permanently
pressed.

Outputs of the latch are active-low in
this configuration because signals
are connected to reset input.

Attention: Common Mode input of the LM339 is
limited to Vcc - 2V!
However, if only one input is outside this range the
comparison is still correct.
See section 9.2.2.1 of the datasheet.

Infineon Technologies AG
IFAG DES SDF SCS EPE
Am Campeon 1-12 - 85579 Neubiberg - Germany

Learning Platform for Switching Regulators

VCC | 3 GND 12

Safety.SchDoc

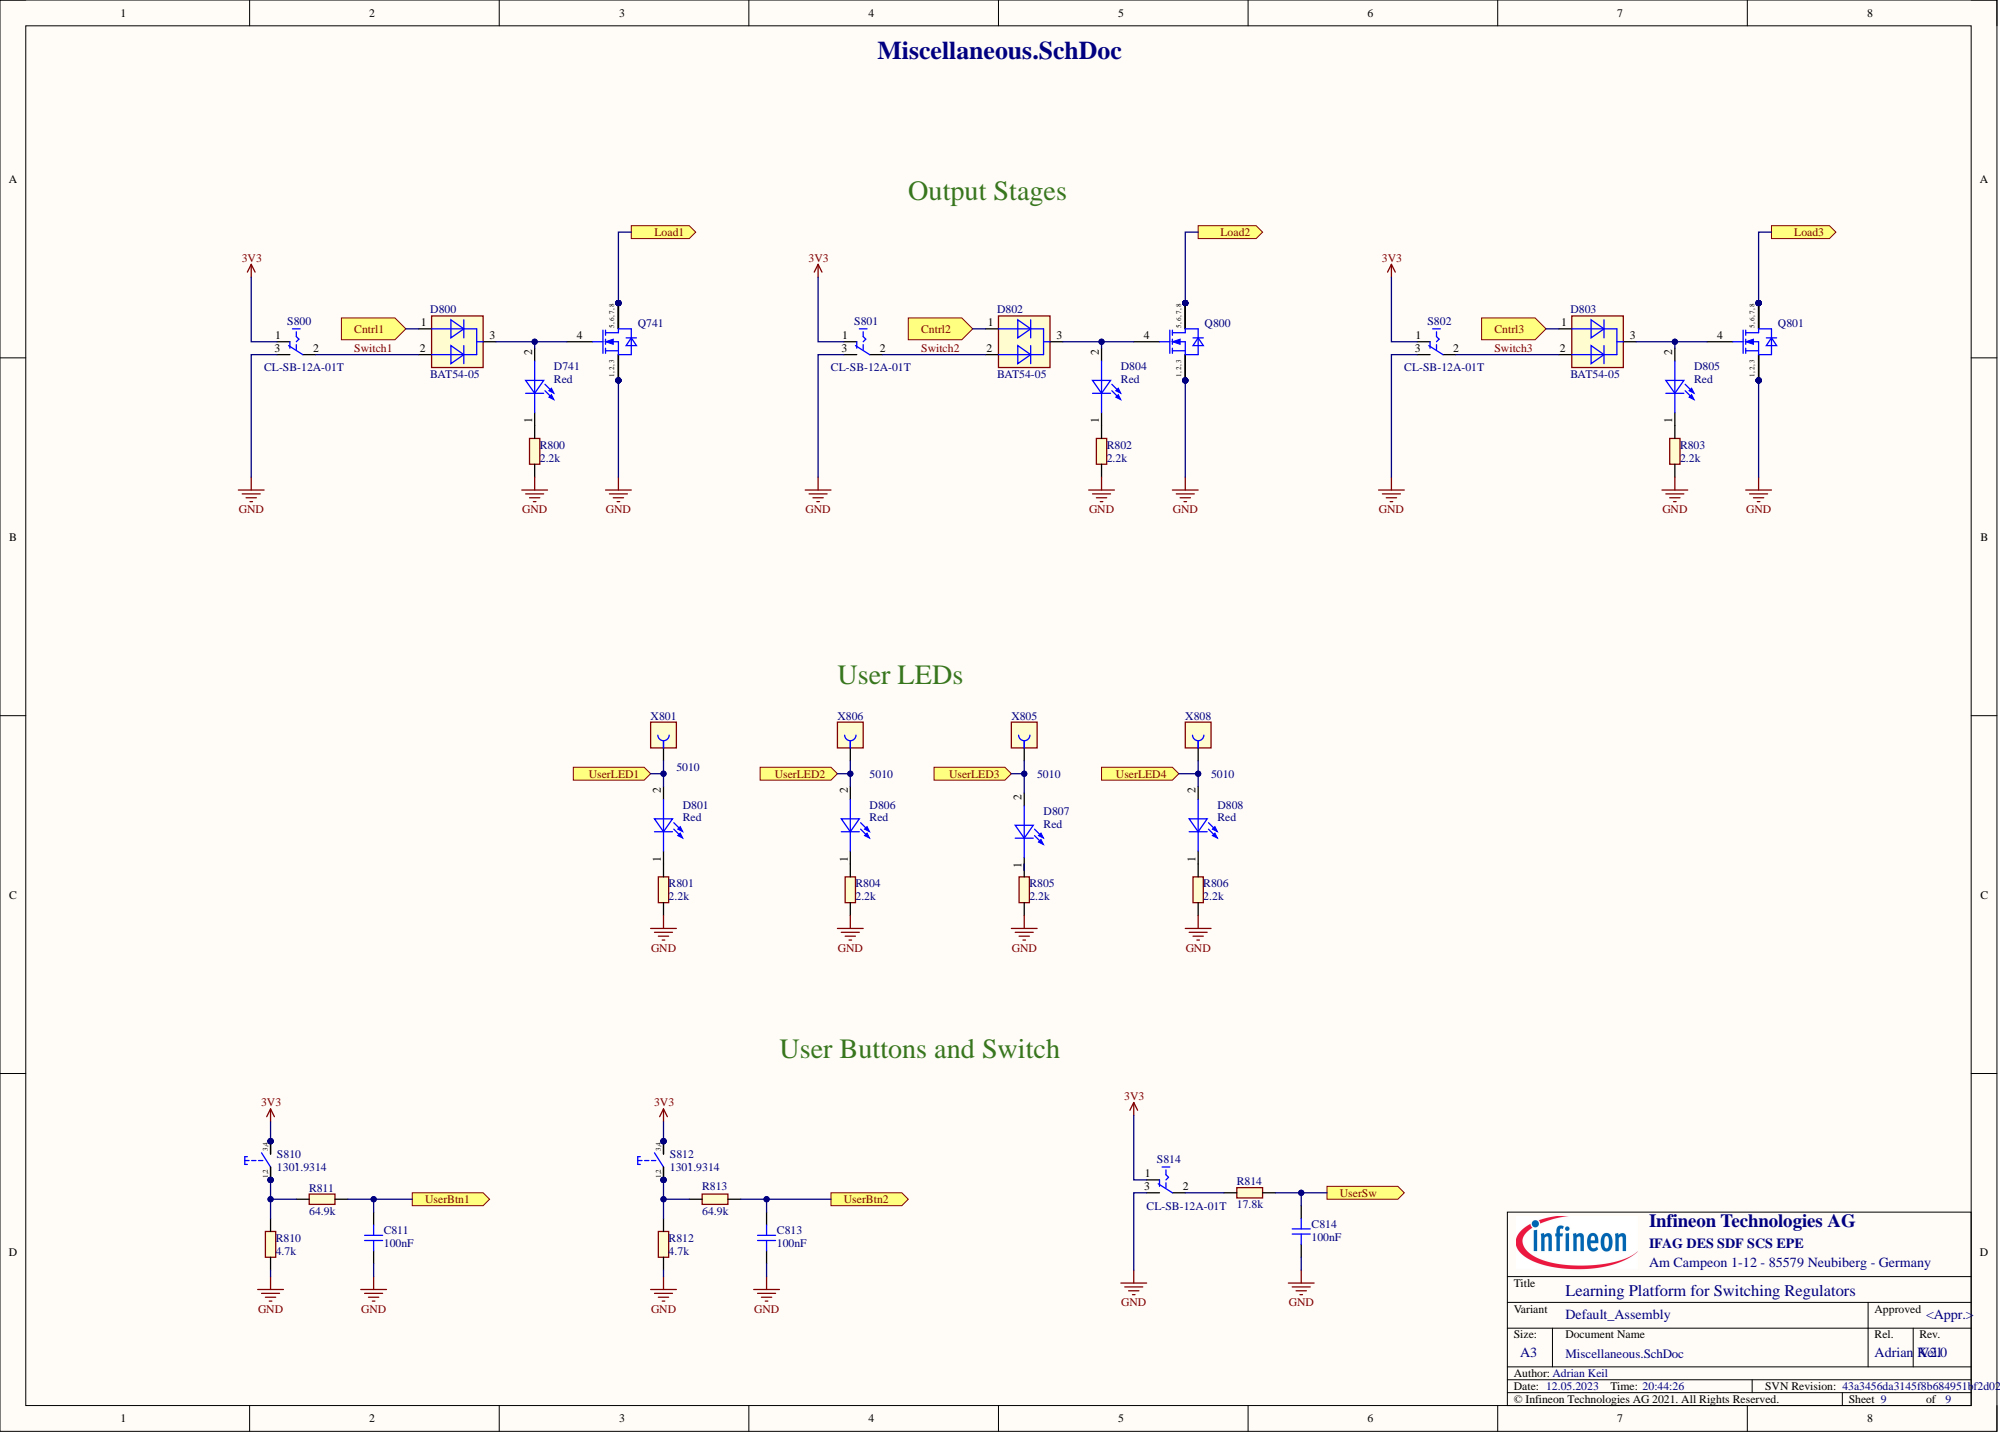
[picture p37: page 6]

User Buttons and Switch

Infineon Technologies AG
IFAG DES SDF SCS EPE
Am Campeon 1-12 - 85579 Neubiberg - Germany

Learning Platform for Switching Regulators

Variant Default_Assembly | Approved <Appr.>

Miscellaneous.SchDoc

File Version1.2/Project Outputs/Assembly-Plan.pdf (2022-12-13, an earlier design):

Quantity | Designator | Placed? | Value | Manufacturer | Manufacturer Order Number | Part Type | Sheet
3 C204, C411, C441 | | | 10nF | TDK Corporation | C1608X8R1H103K080AA | Capacitor | 3, 5
1 C210 | | | 1mF | Kemet | ESY108M035AL4AA | Capacitor | 3
3 C212, C701, C715 | | | 220uF | Panasonic | EEEFP1H221AV | Capacitor | 3, 8
10 | C213, C321, C323, C324, C404, C434, C700, C710, C711, C712 | | 10uF | Murata Electronics | GRT31CR61H106ME01L | Capacitor | 3, 4, 5, 8
34 | C220, C300, C310, C320, C322, C400, C402, C410, C430, C432, C440, C500, C501, C503, C505, C510, C514, C520, C523, C526, C530, C533, C540, C562, C570, C600, C610, C630, C750, C751, C752, C811, C813, C814 | | 100nF | AVX | 06035C104KAT2A | Capacitor | 3, 4, 5, 6, 7, 8, 9
5 C221, C412, C442, C722, C723 | | | 1nF | Würth | 885012206083 | Capacitor | 3, 5, 8
6 | C301, C311, C405, C435, C506, C507 | | 2.2uF | MuRata | GRM188R61E225KA12D | Capacitor | 4, 5, 6
Don't place | C511, C515 | | 22pF | AVX | 06035A220K4T2A | Capacitor | 6
2 D110, D111 | | | BAT54-05W | Infineon | BAT54-05W | Diode | 2
2 D112, D320 | | | BAS3010A-03W | Infineon | BAS3010A-03W | Diode | 2, 4
3 D200, D201, D202 | | | 12V | Nexperia | BZX84-C12,215 | Diode | 3
1 D203 | | | 20V | Nexperia | BZX84-C20,215 | Diode | 3
1 D204 | | | ATL431AQDBZR | Texas Instruments | ATL431AQDBZR | Integrated Circuit | 3
12 | D210, D550, D551, D552, D553, D741, D743, D745, D801, D803, D805, D807 | | Red | Würth | 150060RS75000 | Diode | 3, 6, 8, 9
1 D211 | | | SMDJ20A | Littelfuse | SMDJ20A | Diode | 3
13 | D321, D402, D404, D405, D411, D432, D434, D435, D441, D442, D443, D511, D515 | | BAS70-04 | Infineon | BAS70-04 | Diode | 4, 5, 6
3 D410, D433, D440 | | | 15V | Nexperia | BZX84-C15,215 | Diode | 5
1 D730 | | | SMC5K40A-M3/I | Vishay | SMC5K40A-M3/I | Diode | 8
1 D731 | | | PMEG6030ETPX | Nexperia | PMEG6030ETPX | Diode | 8
3 D740, D742, D744 | | | BAT54-06W | Infineon | BAT54-06W | Diode | 8
1 G300 | | | TLS805B1LDV | Infineon | TLS805B1LDV | Power Supply | 4
1 G310 | | | TPS7B83-Q1 | Texas Instruments | TPS7B8333QDCYRQ1 | Power Supply | 4
1 G320 | | | MCP16301T-E/CH | Microchip | MCP16301T-E/CH | Power Supply | 4
1 JP110 | | | 61301221121 | Würth | 61301221121 | Connector | 2
2 JP111, JP112 | | | 61301621121 | Würth | 61301621121 | Connector | 2
5 | JP120, JP122, JP123, JP124, JP128 | | 61300311121 | Würth | 61300311121 | Connector | 2
9 | JP125, JP126, JP127, JP212, JP421, JP701, JP723, TP421, X720 | | 61300211121 | Würth | 61300211121 | Connector | 2, 3, 5, 8
1 JP710 | | | 61300421121 | Würth | 61300421121 | Connector | 8
1 L320 | | | 22uH | Würth | 74404064220 | Inductor | 4
1 L420 | | | 27uH | Würth | 7447709270 | Inductor | 5
1 L421 | | | 15uH | Bourns | SRP6060FA-150M | Inductor | 5
13 | Q124, Q130, Q550, Q551, Q552, Q553, Q740, Q742, Q744, Q800, Q802, Q804, Q806 | | BSS816NW | Infineon | BSS816NW | Transistor FET | 2, 6, 8, 9
2 Q200, Q201 | | | IPD650P06NM | Infineon | IPD650P06NM | Transistor FET | 3
1 Q202 | | | BSS84PH6327XTSA 2 | Infineon | BSS84PH6327XTSA2 | Transistor FET | 3

7 | Q400, Q401, Q430, Q431, Q741, Q743, Q745 | BSZ100N06NS | Infineon | BSZ100N06NS | Transistor FET | 5, 8
4 R103, R211, R420, R421 | | 15mR | Ohmite | L4T12FR015FER | Resistor | 2, 3, 5
22 | R110, R111, R112, R130, R200, R202, R203, R205, R209, R220, R411, R441, R503, R504, R508, R512, R521, R528, R800, R802, R804, R806 | 47k | Vishay | CRCW060347K0FK | Resistor | 2, 3, 5, 6, 9
11 | R122, R123, R320, R505, R506, R507, R509, R513, R740, R742, R744 | 100k | Vishay | CRCW0603100KFK | Resistor | 2, 6, 8
8 | R124, R131, R322, R410, R440, R631, R633, R722 | 1.3k | Vishay | CRCW06031K30FK | Resistor | 2, 5, 7, 8
4 R160, R524, R531, R611 | | 10k | Bourns | 3361P-1-103GLF | Resistor | 2, 6, 7
6 | R170, R400, R401, R430, R431, R720 | 20R | Vishay | CRCW060320R0FK | Resistor | 2, 5, 8
2 R204, R208 | | 2MEG | Vishay | CRCW06032M00FK | Resistor | 3
6 | R206, R562, R632, R634, R811, R813 | 64.9k | Vishay | CRCW060364K9FK | Resistor | 3, 6, 7, 9
12 | R207, R210, R301, R321, R500, R522, R529, R721, R741, R743, R745, R814 | 17.8k | Vishay | CRCW060317K8FK | Resistor | 2, 3, 4, 6, 7, 8, 9
2 R212, R701 | | 300mR | Vishay | WSL2512R3000FEA | Resistor | 3, 8
22 | R221, R404, R405, R434, R501, R502, R510, R511, R514, R515, R520, R523, R525, R527, R530, R532, R561, R750, R751, R752, R810, R812 | 4.7k | Vishay | CRCW06034K70FK | Resistor | 2, 3, 4, 5, 6, 8, 9
13 | R302, R303, R402, R403, R435, R550, R551, R552, R553, R801, R803, R805, R807 | 2.2k | Vishay | CRCW06032K20FK | Resistor | 4, 5, 6, 9
1 R526 | | 10k | MuRata | NCU18XH103D60RB | NTC | 6
4 S110, S560, S810, S812 | | 1301.9314 | Schurter | 1301.9314 | Electro Mechanic | 2, 6, 9
5 S200, S750, S751, S752, S814 | | CL-SB-12A-01T | NIDEC COPAL. | CL-SB-12A-01T | Electro Mechanic | 3, 8, 9
6 | TP100, TP101, TP102, TP103, TP104, TP105 | 5011 | Keystone | 5011 | Connector | 2
18 | TP160, TP211, TP320, TP400, TP401, TP430, TP431, TP432, TP525, TP532, TP540, TP541, TP542, TP543, TP600, TP610, TP611, TP630 | S1751-46R | Harwin | S1751-46R | Connector | 2, 3, 4, 5, 6, 7
2 U400, U430 | | IRS2184SPBF | Infineon | IRS2184SPBF | Power Supply | 5
2 U410, U440 | | ICM7555IBAZ | Renesas | ICM7555IBAZ | Integrated Circuit | 5
2 U500, U520 | | LM339PWR | Texas Instruments | LM339PWR | Analog Parts | 6
1 U501 | | MCP6567-E/MS | Microchip | MCP6567-E/MS | Analog Parts | 6
1 U540 | | HEF4043BT,653 | Nexperia | HEF4043BT,653 | Integrated Circuit | 6
1 U570 | | 74HC4002PW,118 | Nexperia | 74HC4002PW,118 | Integrated Circuit | 6
1 U600 | | MAX4073FAUT+T | Maxim Integrated | MAX4073FAUT+T | Analog Parts | 7
1 U610 | | MAX40056TAUA+ | Maxim Integrated | MAX40056TAUA+ | Analog Parts | 7
1 U630 | | TLV197QDGKRQ1 | Texas Instruments | TLV197QDGKRQ1 | Analog Parts | 7
2 X100, X102 | | 973 582-101 | Hirschmann | 973 582-101 | Connector | 2
2 X101, X103 | | 973 582-100 | Hirschmann | 973 582-100 | Connector | 2
1 X140 | | 61301211121 | Würth | 61301211121 | Connector | 2
1 X150 | | 61201021621 | Würth | 61201021621 | Connector | 2

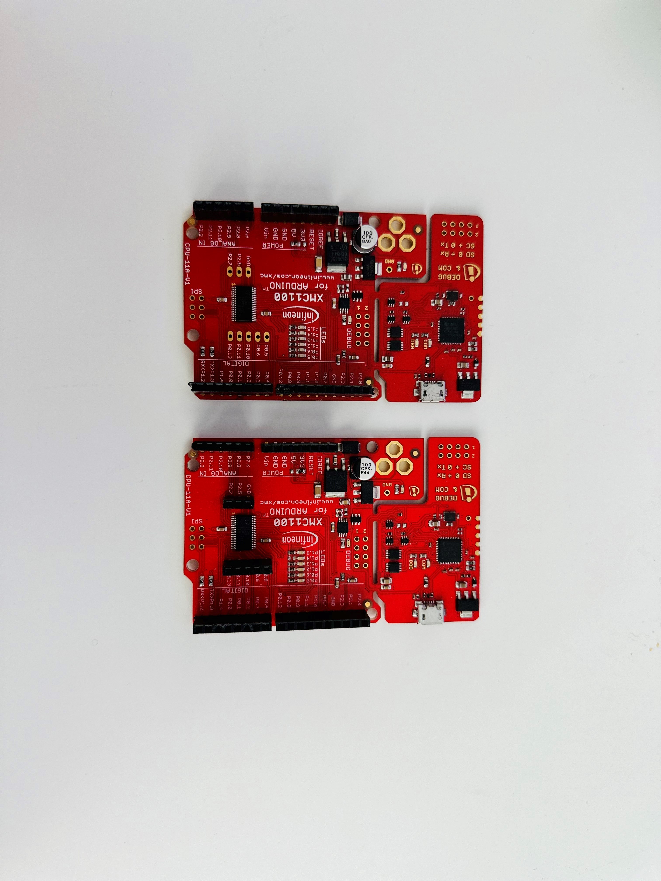
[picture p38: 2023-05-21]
photos/XMCSOLDER.jpg

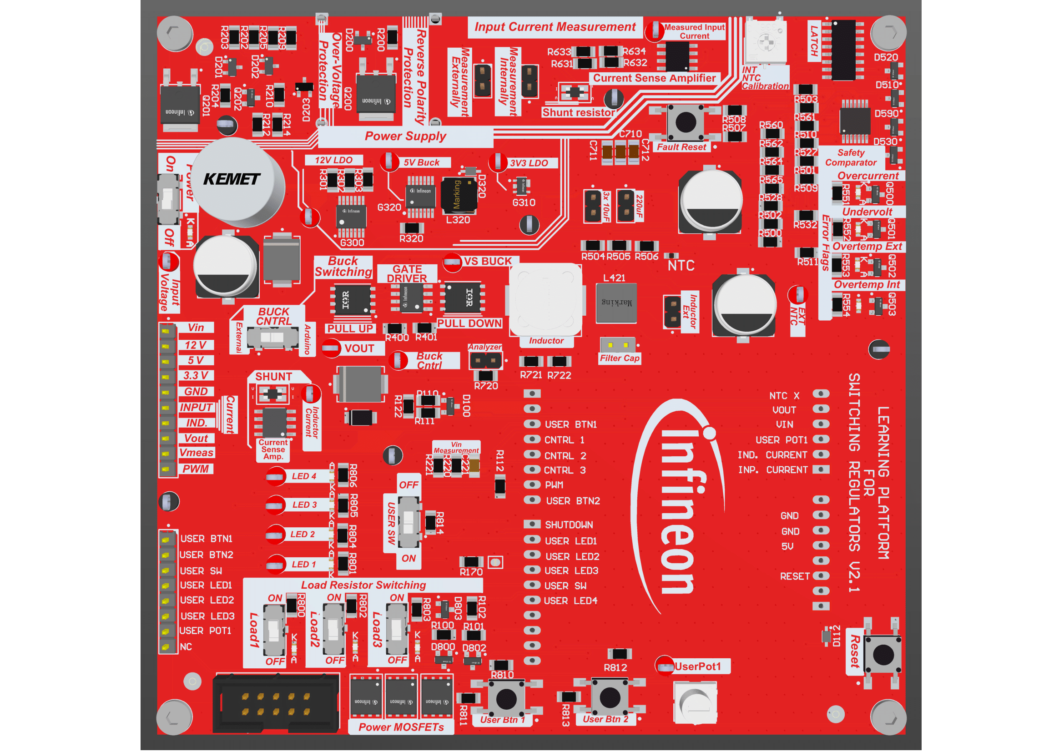
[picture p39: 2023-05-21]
Version2.2/Project Outputs for Learning Platform/PDF/PCB 3D Prints-1.png

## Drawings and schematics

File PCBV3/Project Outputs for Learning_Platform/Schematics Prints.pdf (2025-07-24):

# 02_Top_Level.SchDoc

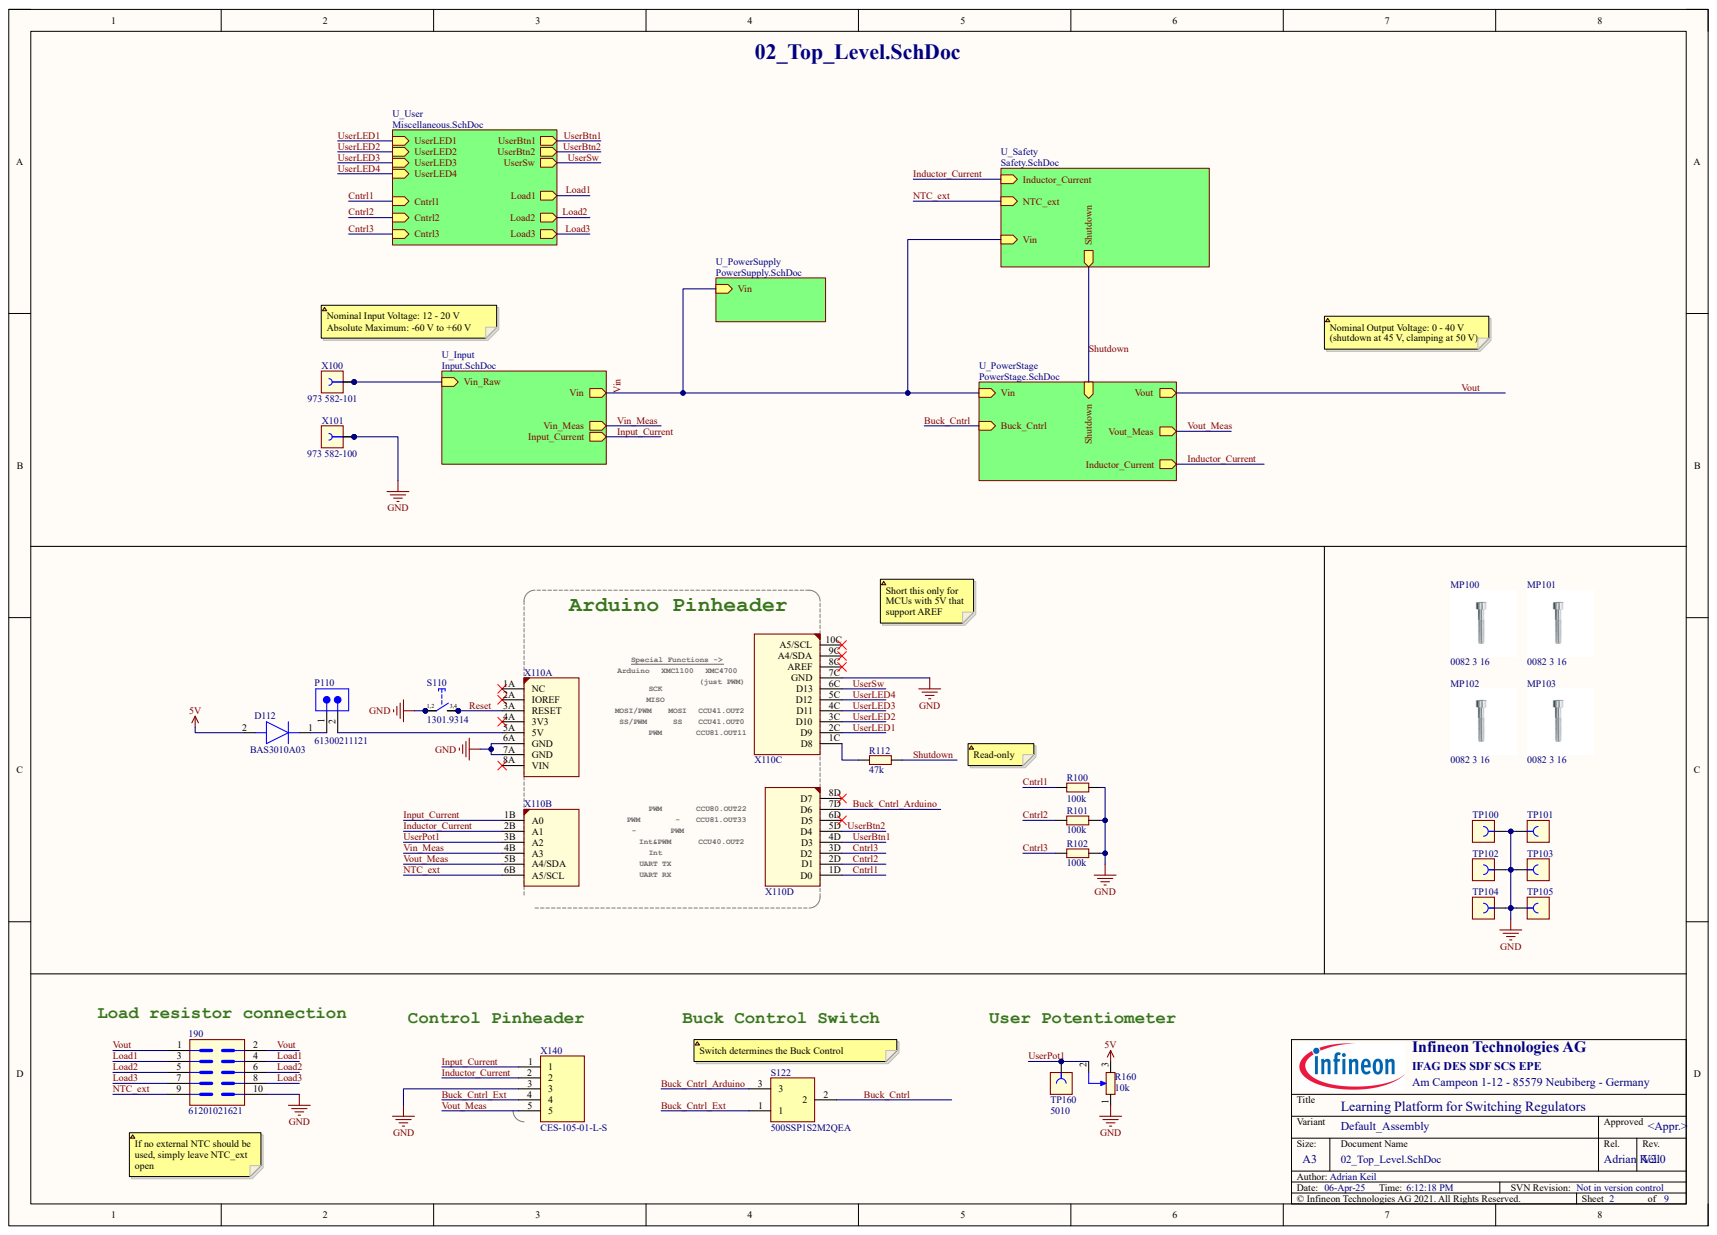
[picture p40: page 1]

(shutdown at 45 V, clamping at 50 V)

Short this only for
MCUs with 5V that
support AREF

Infineon Technologies AG
IFAG DES SDF SCS EPE
Am Campeon 1-12 - 85579 Neubiberg - Germany

Switch determines the Buck Control

Title
Learning Platform for Switching Regulators
Default_Assembly
Document Name
Author: Adrian Keil
© Infineon Technologies AG 2021. All Rights Reserved.

If no external NTC should be
used, simply leave NTC_ext
open

SVN Revision: Not in version control

# Input.SchDoc

Reverse-Polarity Protection | Over-Voltage Protection | Voltage Measurement

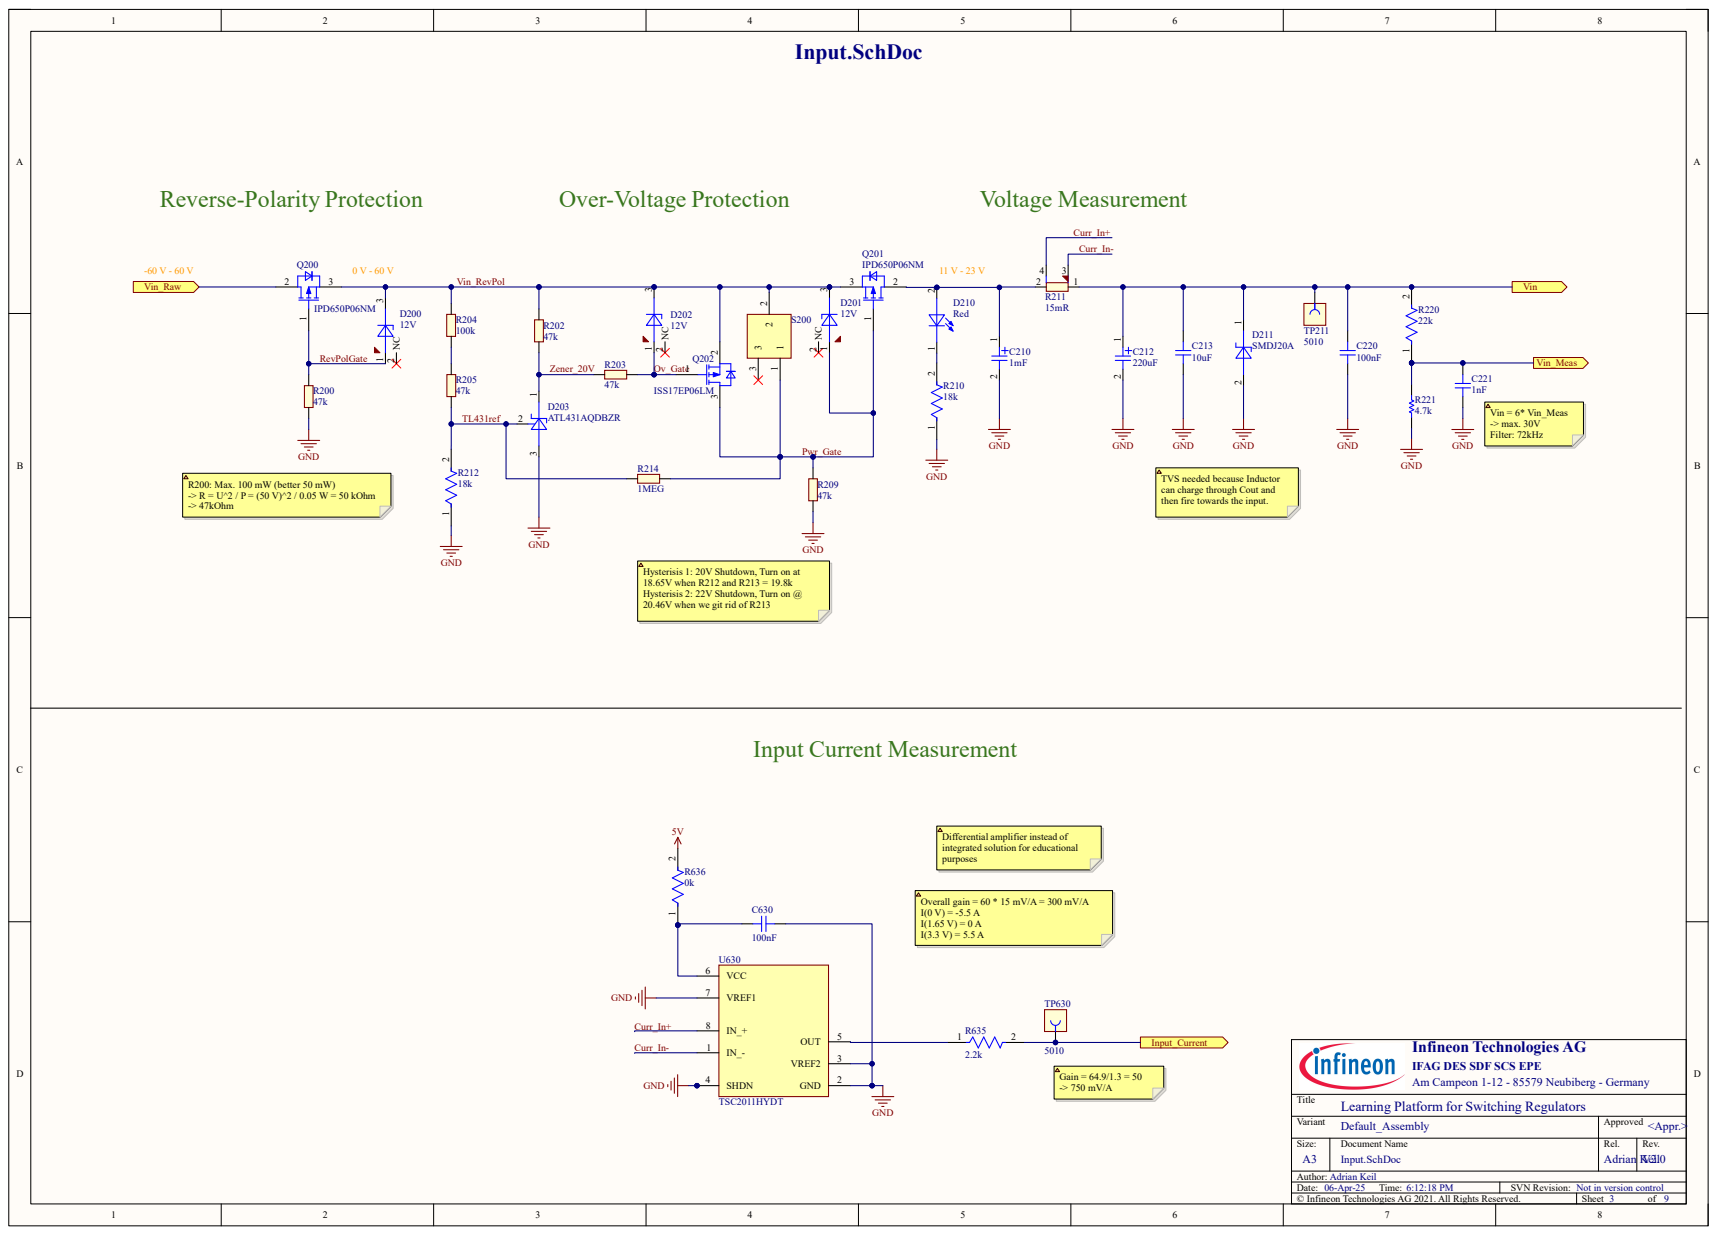
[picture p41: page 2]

TVS needed because Inductor
can charge through Cout and
then fire towards the input.

Hysterisis 1: 20V Shutdown, Turn on at
18.65V when R212 and R213 = 19.8k
Hysterisis 2: 22V Shutdown, Turn on @
20.46V when we git rid of R213

Differential amplifier instead of
integrated solution for educational
purposes

Infineon Technologies AG
IFAG DES SDF SCS EPE
Am Campeon 1-12 - 85579 Neubiberg - Germany

Title
Learning Platform for Switching Regulators
Default_Assembly

# PowerSupply.SchDoc

5.6 V Buck Converter | 5V LDO

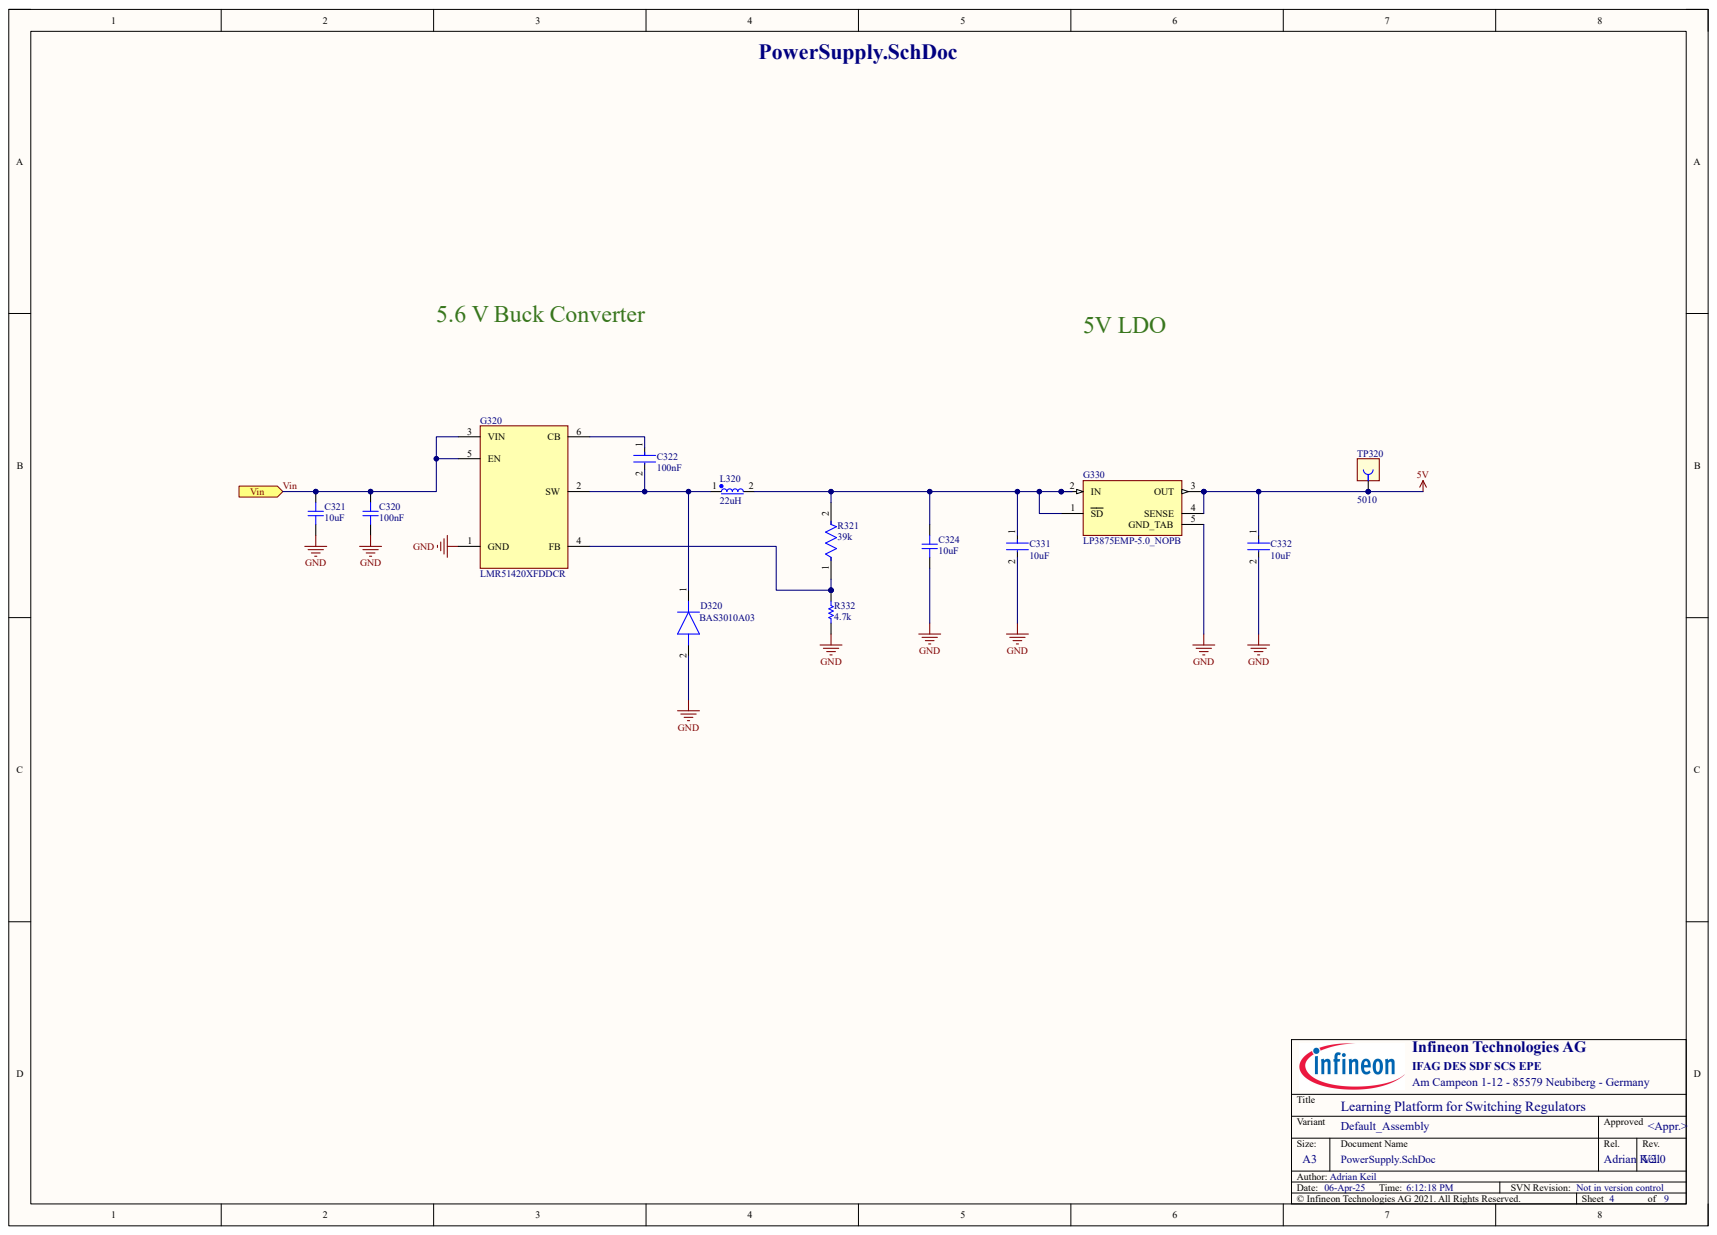
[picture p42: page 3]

Infineon Technologies AG
IFAG DES SDF SCS EPE
Am Campeon 1-12 - 85579 Neubiberg - Germany

Title
Learning Platform for Switching Regulators
Default_Assembly

# PowerStage.SchDoc

# Gate-Driver/ Switching

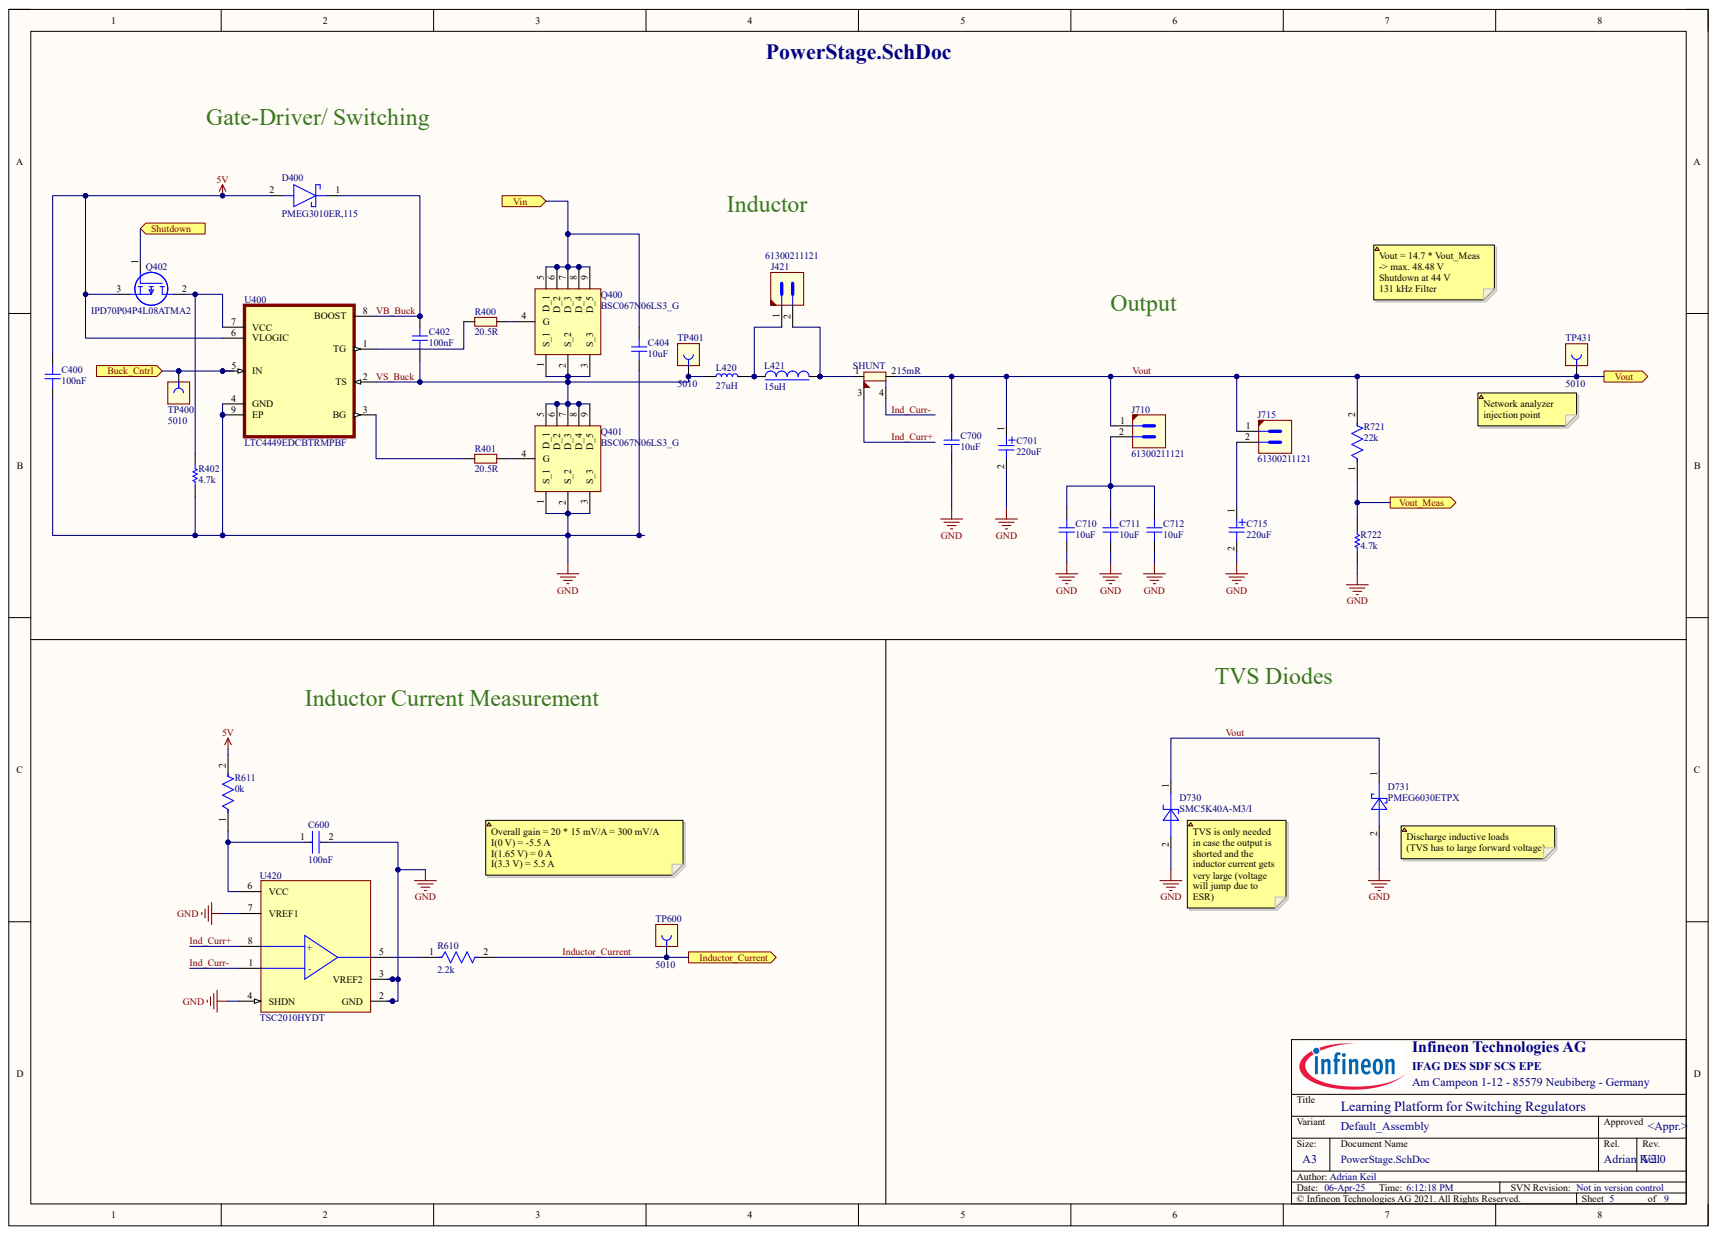
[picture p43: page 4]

TVS is only needed
in case the output is
shorted and the
inductor current gets
very large (voltage
will jump due to

Discharge inductive loads
(TVS has to large forward voltage)

Infineon Technologies AG
IFAG DES SDF SCS EPE
Am Campeon 1-12 - 85579 Neubiberg - Germany

Title
Learning Platform for Switching Regulators
Default_Assembly

# Safety.SchDoc

# Safety-Latch

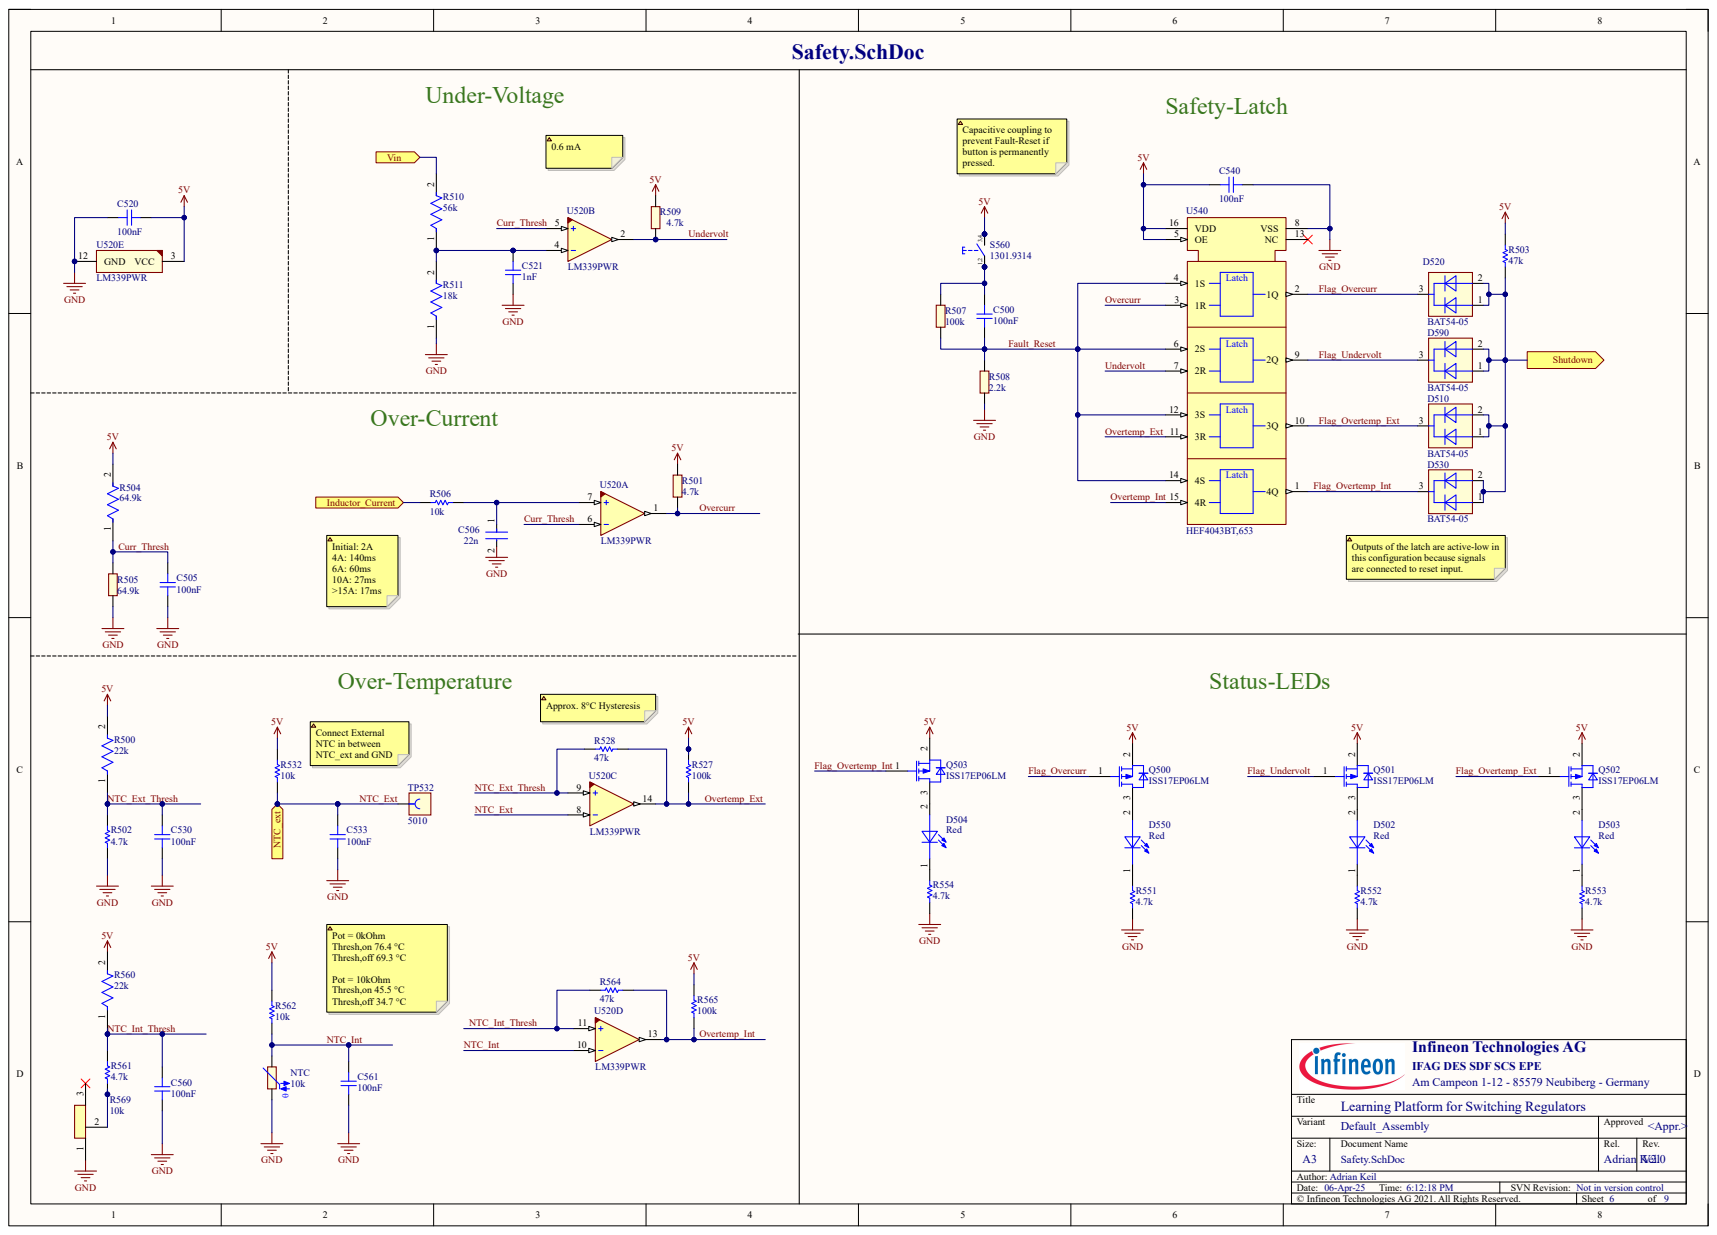
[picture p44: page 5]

Capacitive coupling to
prevent Fault-Reset if
button is permanently
pressed.

Outputs of the latch are active-low in
this configuration because signals
are connected to reset input.

Infineon Technologies AG
IFAG DES SDF SCS EPE
Am Campeon 1-12 - 85579 Neubiberg - Germany

Title
Learning Platform for Switching Regulators
Default_Assembly

# Miscellaneous.SchDoc

# Output Stages

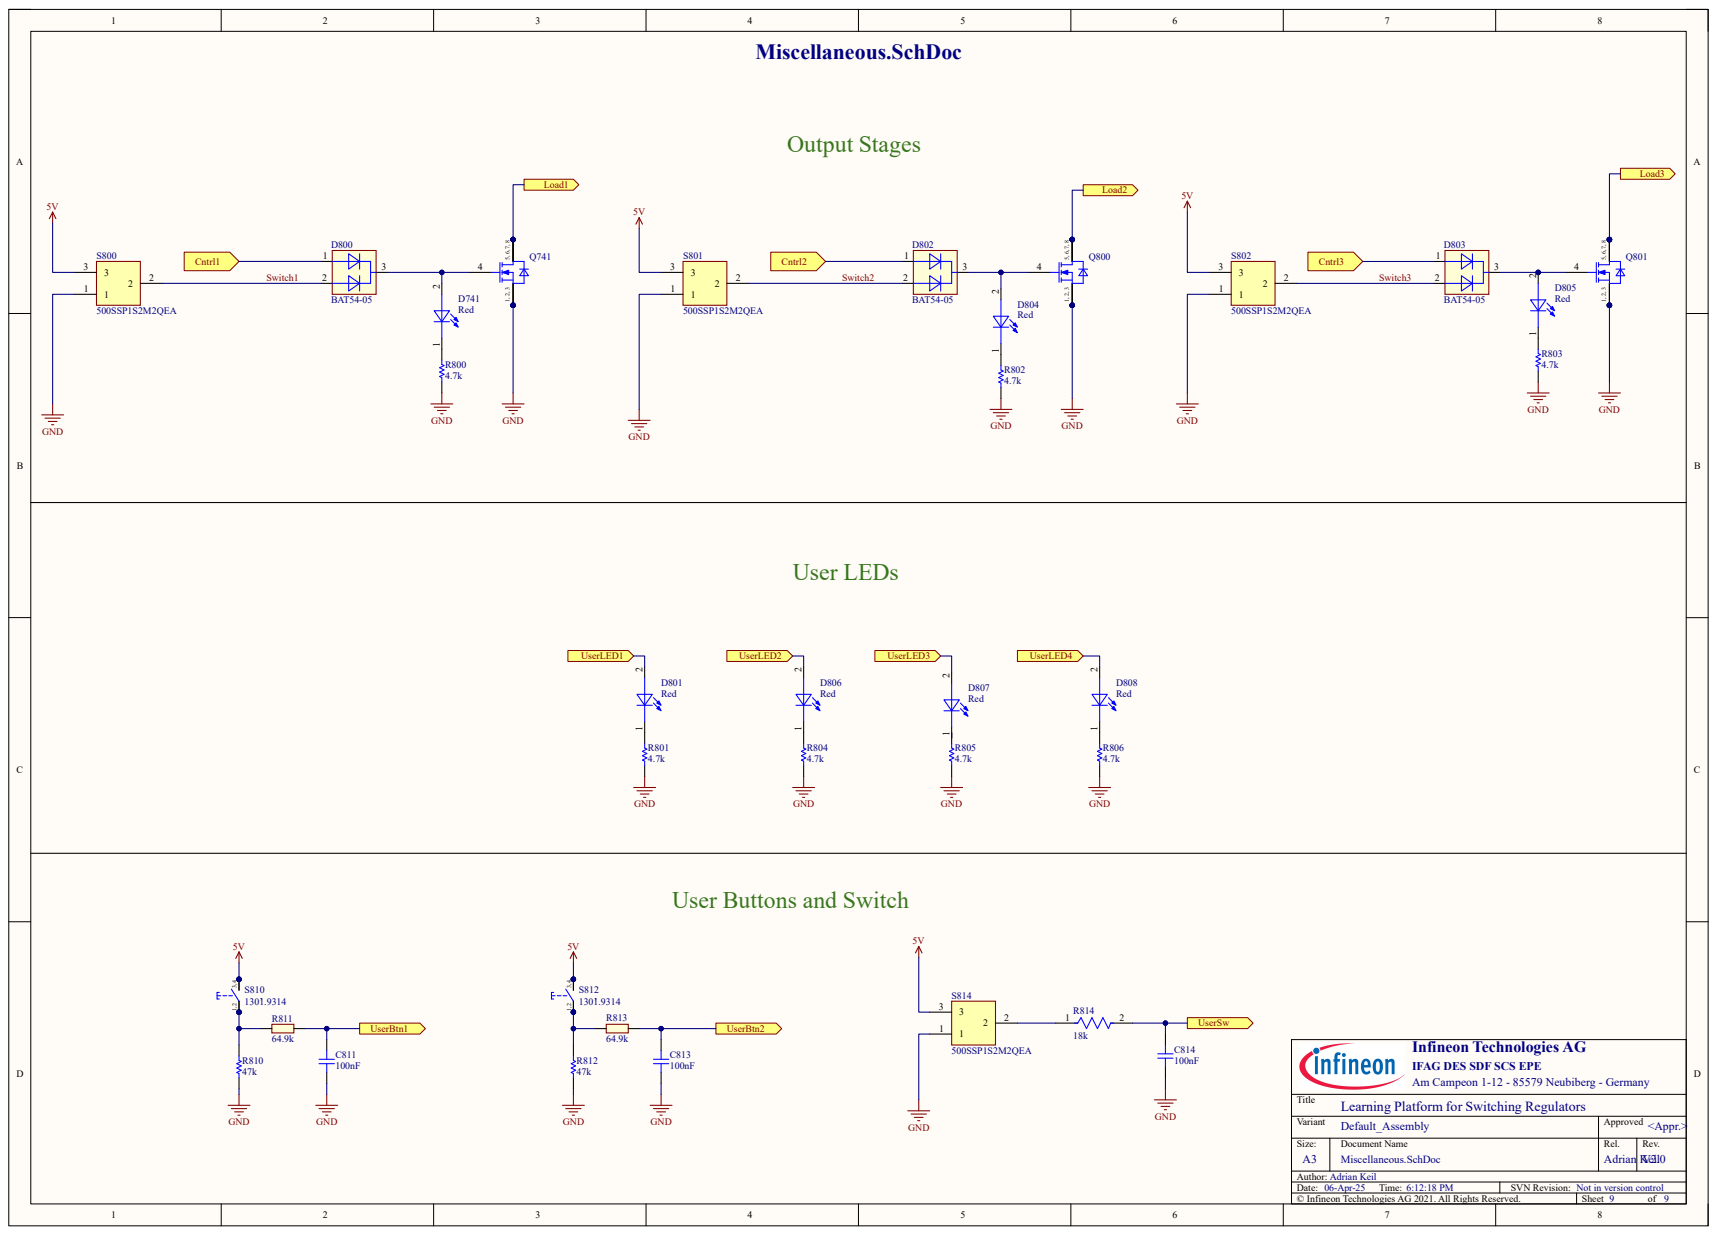
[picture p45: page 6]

User Buttons and Switch

Infineon Technologies AG
IFAG DES SDF SCS EPE
Am Campeon 1-12 - 85579 Neubiberg - Germany

Title
Learning Platform for Switching Regulators
Default_Assembly

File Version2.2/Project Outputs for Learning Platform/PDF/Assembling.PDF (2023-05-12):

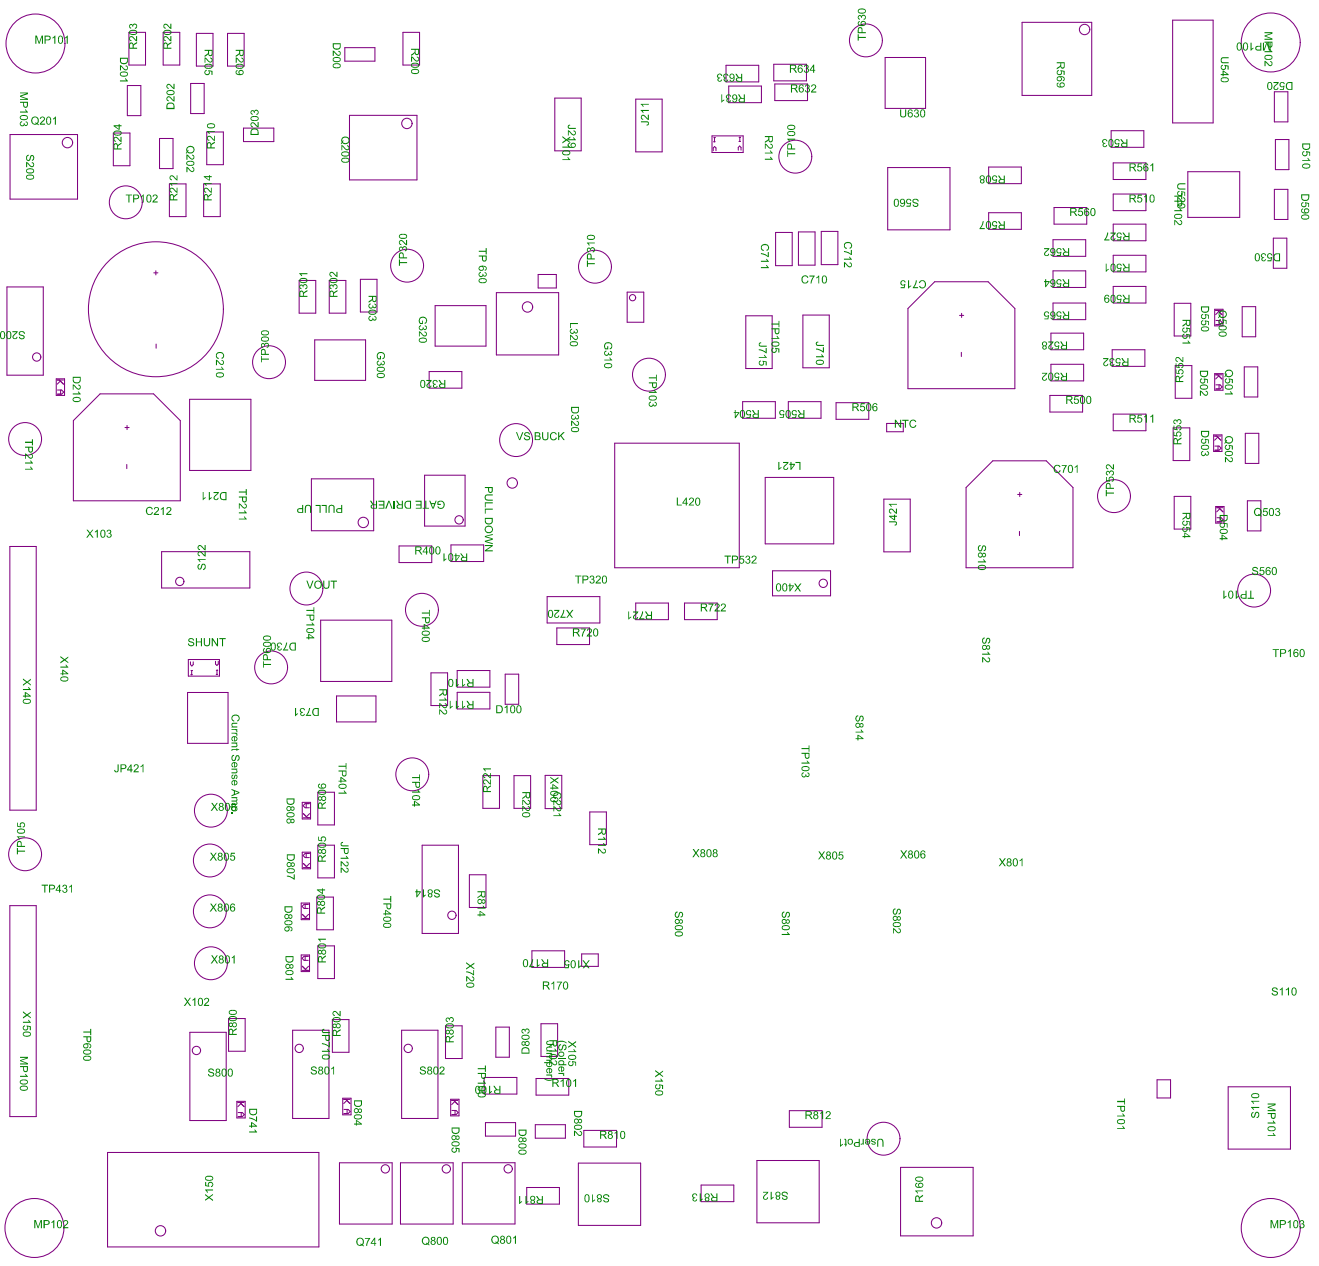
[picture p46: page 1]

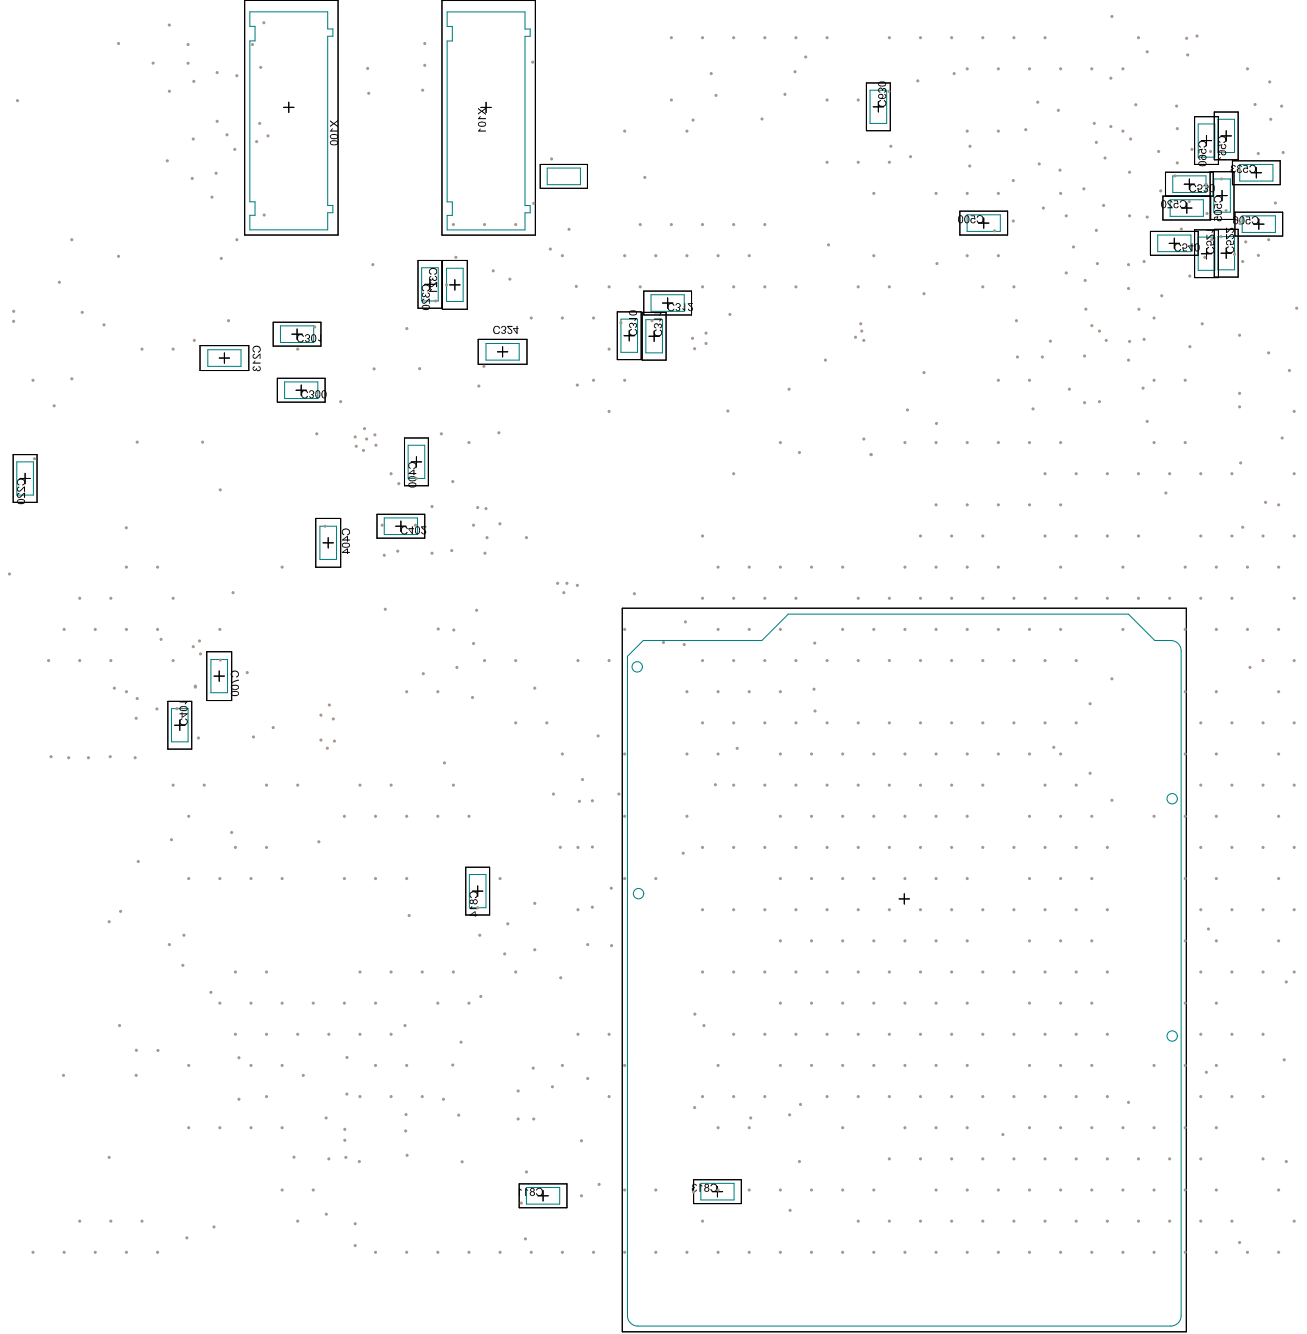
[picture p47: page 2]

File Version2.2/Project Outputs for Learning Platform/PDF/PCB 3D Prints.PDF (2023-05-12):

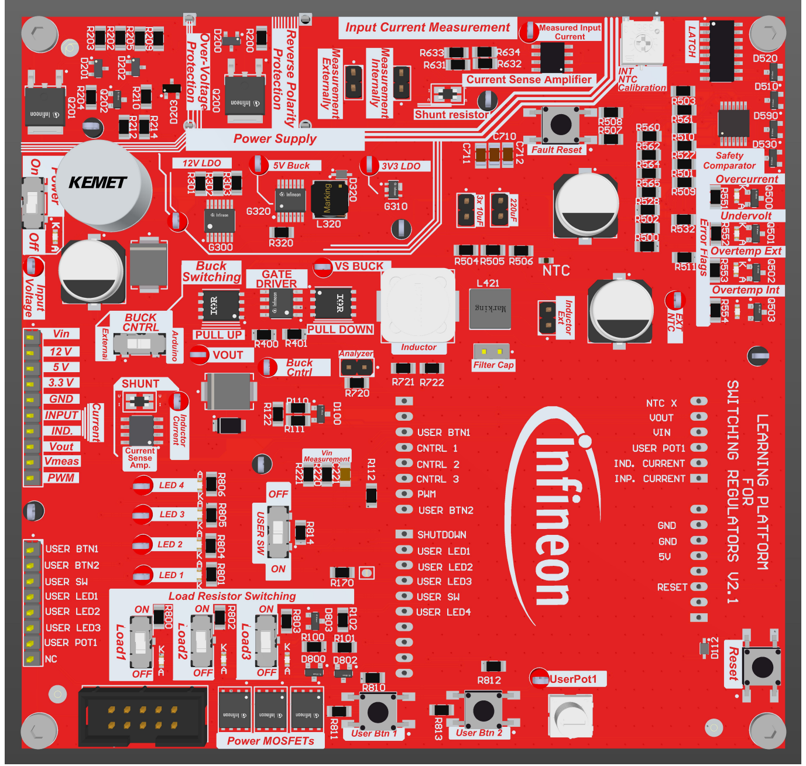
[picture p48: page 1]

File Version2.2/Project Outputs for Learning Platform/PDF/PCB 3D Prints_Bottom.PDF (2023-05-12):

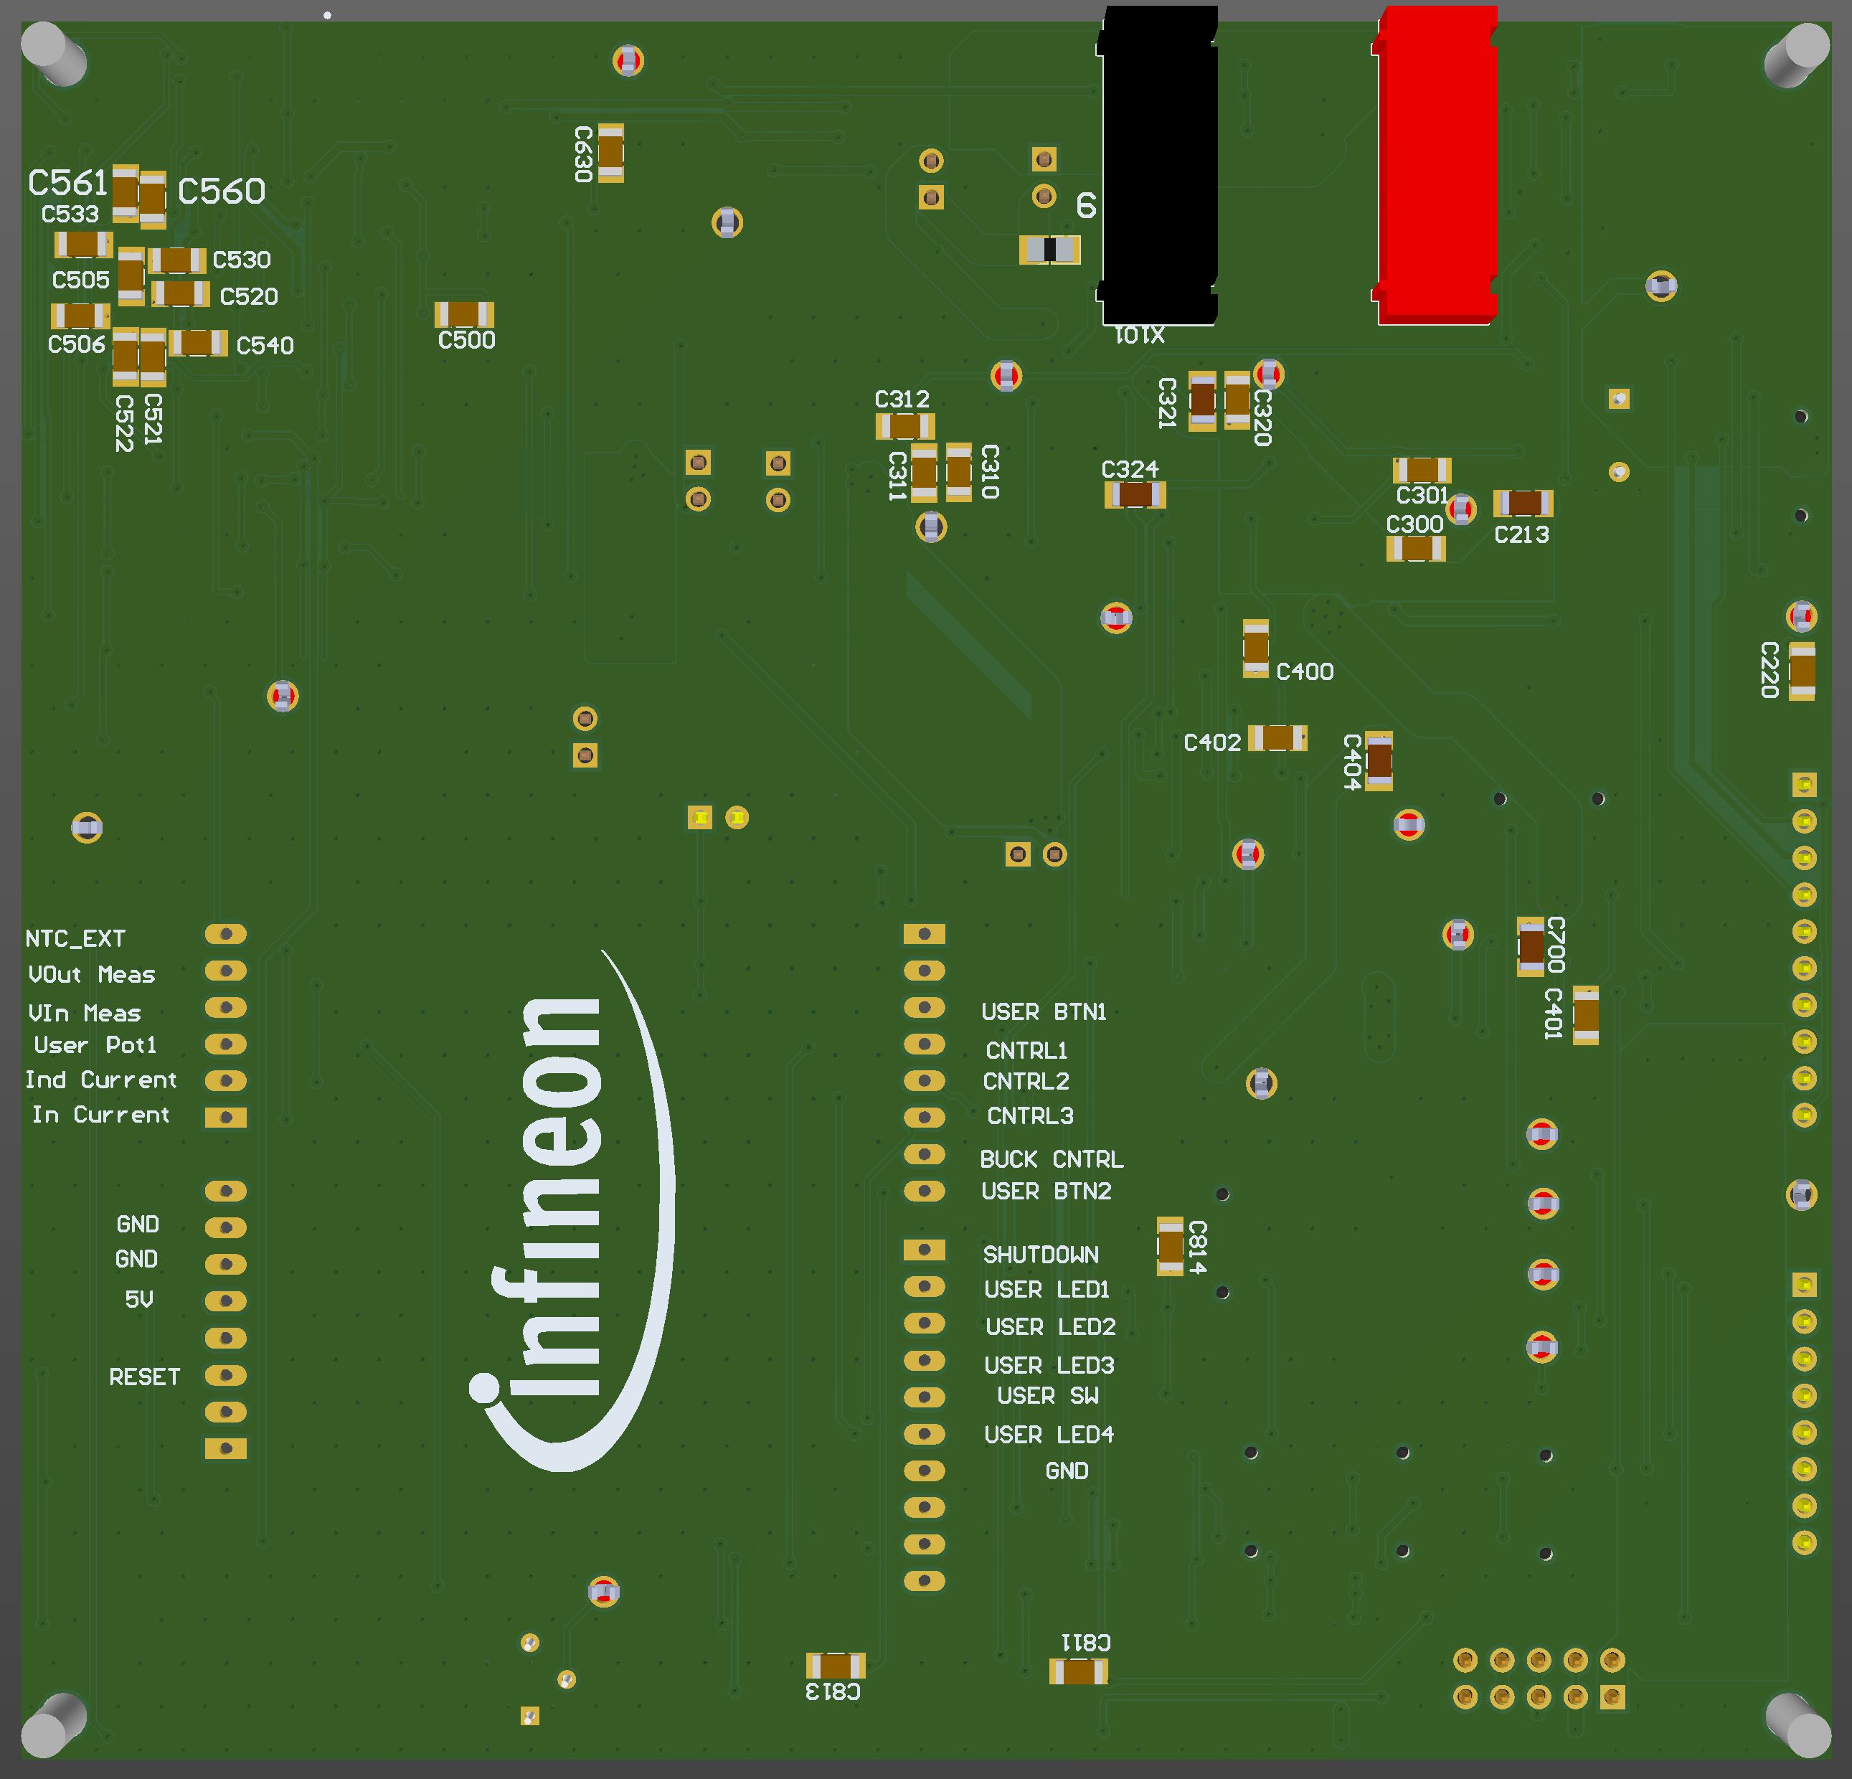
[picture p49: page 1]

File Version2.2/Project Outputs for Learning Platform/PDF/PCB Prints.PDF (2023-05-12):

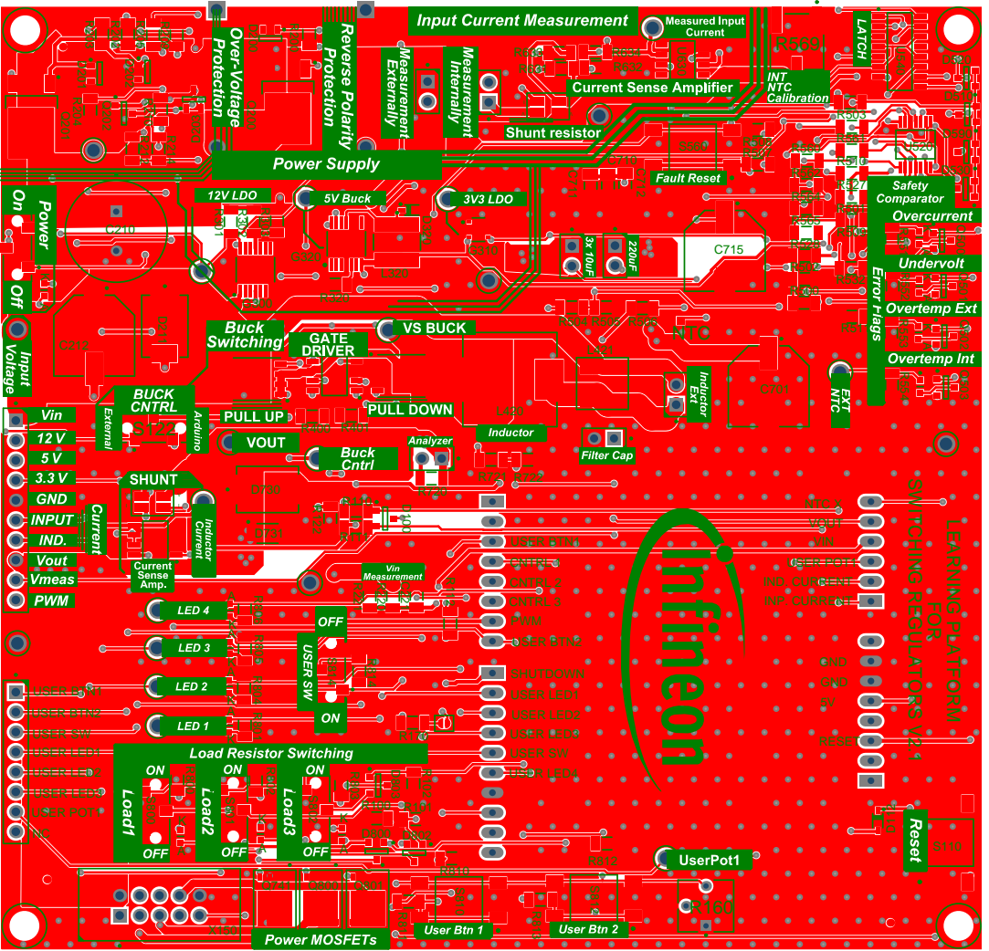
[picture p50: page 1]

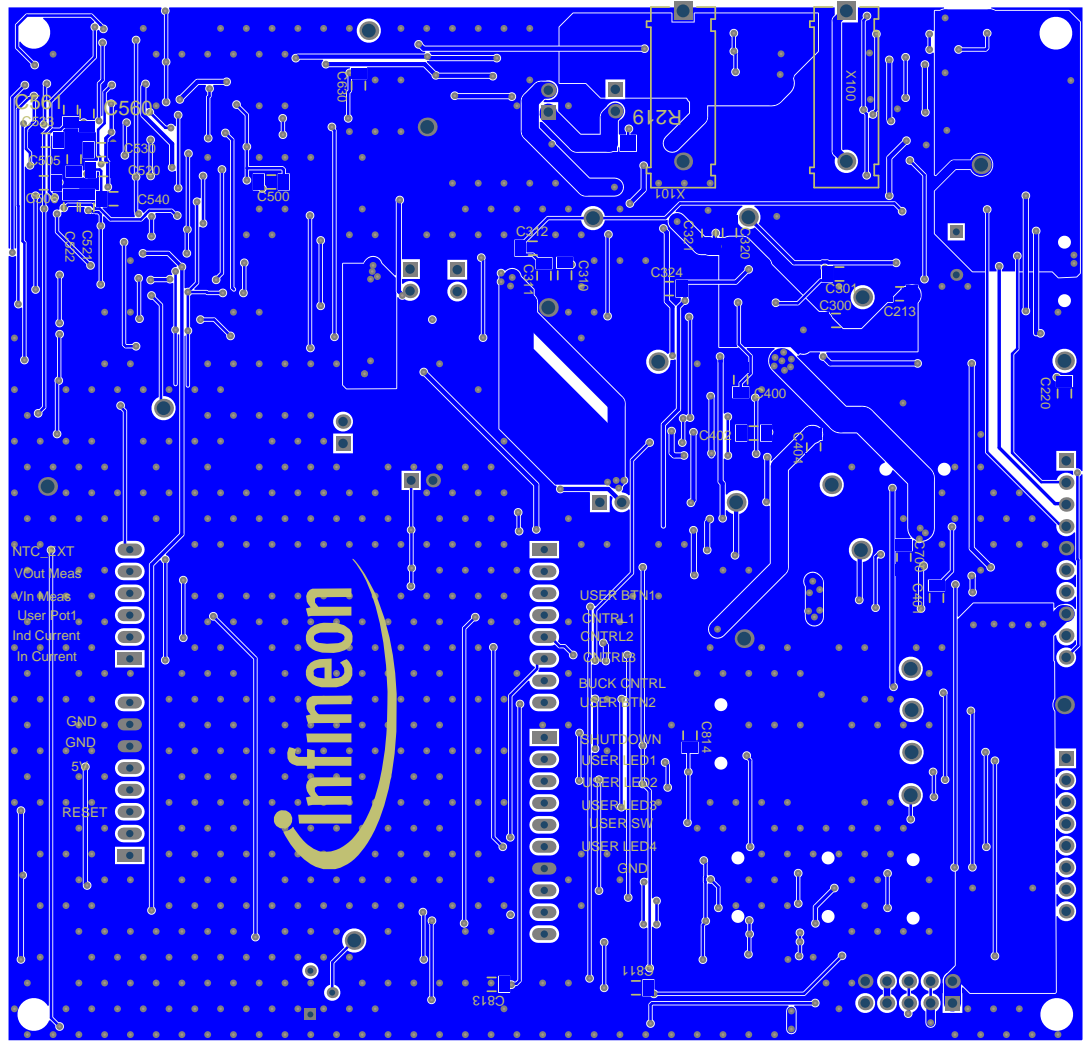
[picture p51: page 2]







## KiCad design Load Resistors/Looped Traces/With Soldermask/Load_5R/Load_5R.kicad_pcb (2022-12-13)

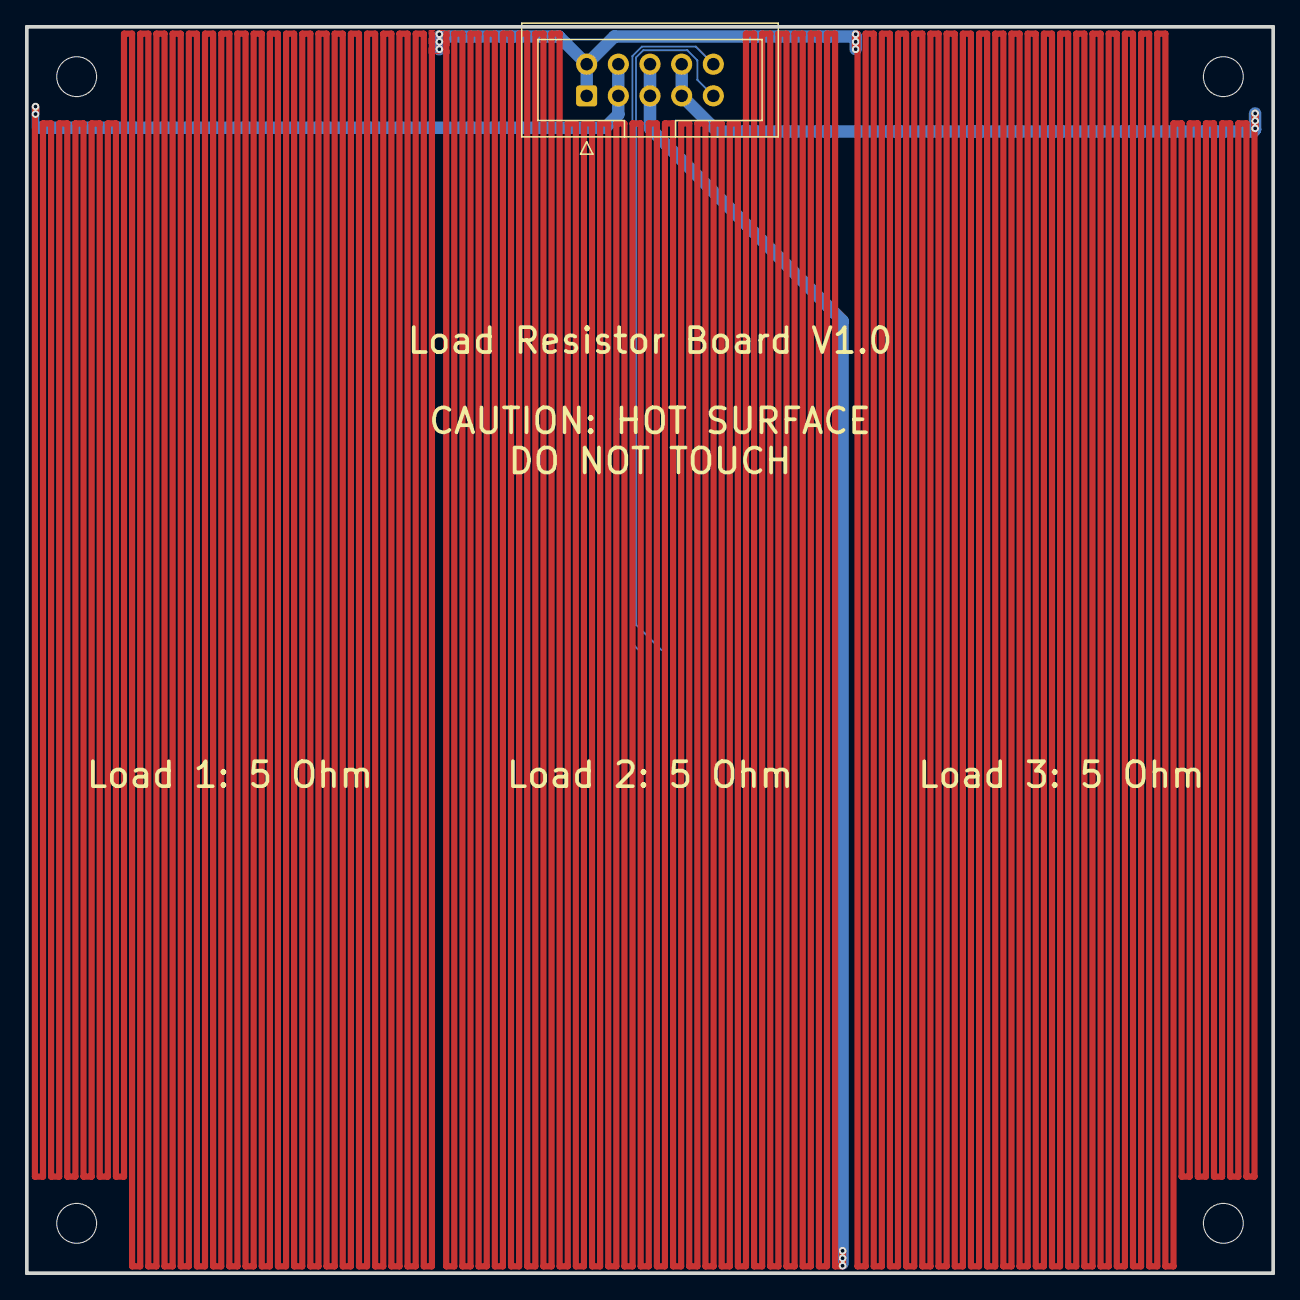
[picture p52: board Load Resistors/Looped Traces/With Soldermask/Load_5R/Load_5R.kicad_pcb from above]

Board: 2 copper layers, 100.0 x 100.0 mm, 6 parts (1 on the bottom side), 3 nets.

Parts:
H1, H2, H3, H4: MountingHole; MountingHole_3.2mm_M3
J1: Conn_02x05_Odd_Even; IDC-Header_2x05_P2.54mm_Vertical
TH1: Thermistor_NTC; R_0603_1608Metric_Pad0.98x0.95mm_HandSolder

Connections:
/Loads: J1.1, J1.2, J1.3, J1.4, J1.5, J1.6, J1.7, J1.8
/NTC_ext: J1.9, TH1.2
GND: J1.10, TH1.1

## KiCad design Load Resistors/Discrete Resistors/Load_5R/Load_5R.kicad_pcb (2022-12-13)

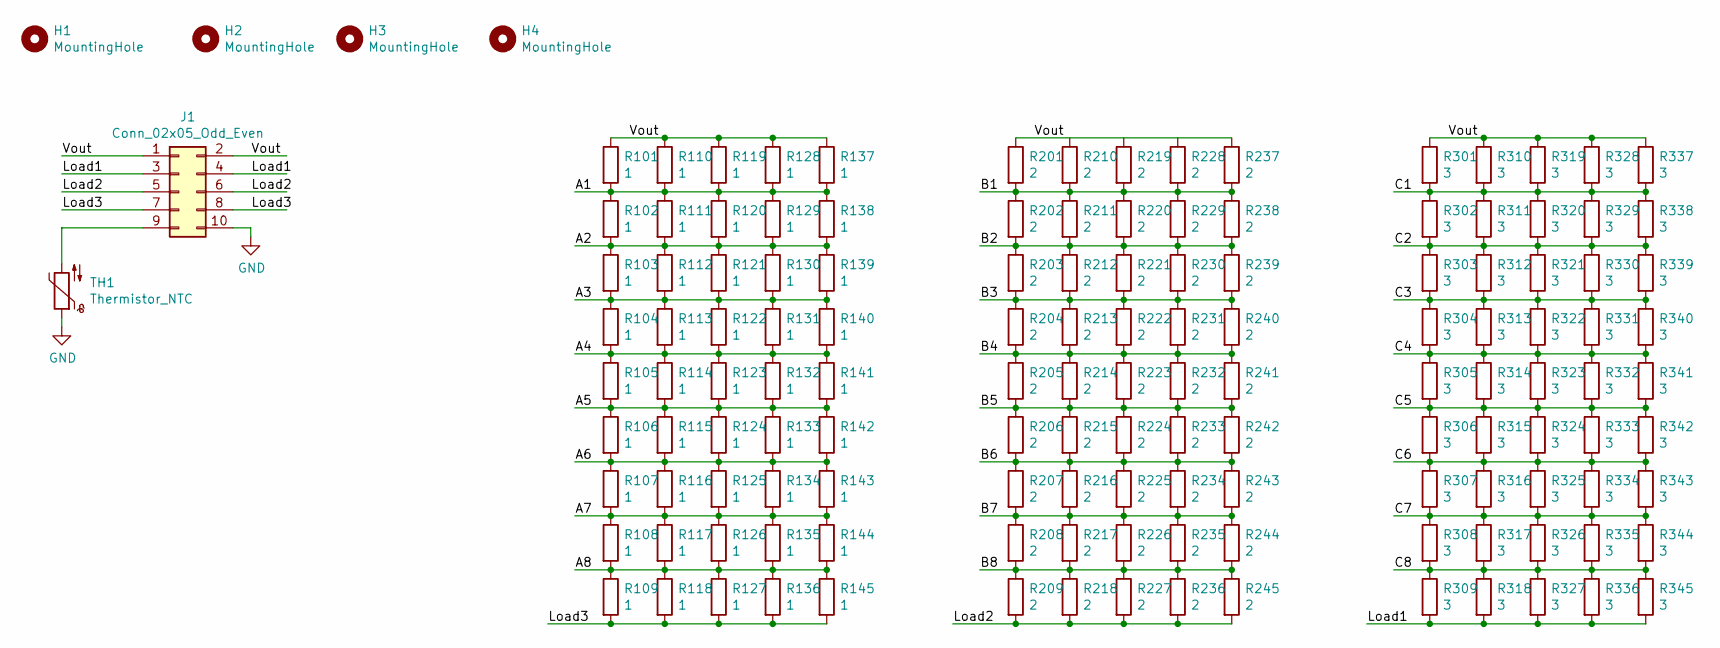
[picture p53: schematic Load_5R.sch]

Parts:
H1, H2, H3, H4: MountingHole; MountingHole_3.2mm_M3
J1: Conn_02x05_Odd_Even; IDC-Header_2x05_P2.54mm_Vertical
R101, R102, R103, R104, R105, R106, R107, R108, R109, R110, R111, R112, R113, R114, R115, R116, R117, R118, R119, R120, R121, R122, R123, R124, R125, R126, R127, R128, R129, R130, R131, R132, R133, R134, R135, R136, R137, R138, R139, R140, R141, R142, R143, R144, R145: 1; R_2512_6332Metric; LCSCPart C10000
R201, R202, R203, R204, R205, R206, R207, R208, R209, R210, R211, R212, R213, R214, R215, R216, R217, R218, R219, R220, R221, R222, R223, R224, R225, R226, R227, R228, R229, R230, R231, R232, R233, R234, R235, R236, R237, R238, R239, R240, R241, R242, R243, R244, R245: 2; R_2512_6332Metric; LCSCPart C20000
R301, R302, R303, R304, R305, R306, R307, R308, R309, R310, R311, R312, R313, R314, R315, R316, R317, R318, R319, R320, R321, R322, R323, R324, R325, R326, R327, R328, R329, R330, R331, R332, R333, R334, R335, R336, R337, R338, R339, R340, R341, R342, R343, R344, R345: 3; R_2512_6332Metric; LCSCPart C30000
TH1: Thermistor_NTC; R_0603_1608Metric_Pad0.98x0.95mm_HandSolder; LCSCPart C92367

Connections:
/A1: R101.2, R102.1, R110.2, R111.1, R119.2, R120.1, R128.2, R129.1, R137.2, R138.1
/A2: R102.2, R103.1, R111.2, R112.1, R120.2, R121.1, R129.2, R130.1, R138.2, R139.1
/A3: R103.2, R104.1, R112.2, R113.1, R121.2, R122.1, R130.2, R131.1, R139.2, R140.1
/A4: R104.2, R105.1, R113.2, R114.1, R122.2, R123.1, R131.2, R132.1, R140.2, R141.1
/A5: R105.2, R106.1, R114.2, R115.1, R123.2, R124.1, R132.2, R133.1, R141.2, R142.1
/A6: R106.2, R107.1, R115.2, R116.1, R124.2, R125.1, R133.2, R134.1, R142.2, R143.1
/A7: R107.2, R108.1, R116.2, R117.1, R125.2, R126.1, R134.2, R135.1, R143.2, R144.1
/A8: R108.2, R109.1, R117.2, R118.1, R126.2, R127.1, R135.2, R136.1, R144.2, R145.1
/B1: R201.2, R202.1, R210.2, R211.1, R219.2, R220.1, R228.2, R229.1, R237.2, R238.1
/B2: R202.2, R203.1, R211.2, R212.1, R220.2, R221.1, R229.2, R230.1, R238.2, R239.1
/B3: R203.2, R204.1, R212.2, R213.1, R221.2, R222.1, R230.2, R231.1, R239.2, R240.1
/B4: R204.2, R205.1, R213.2, R214.1, R222.2, R223.1, R231.2, R232.1, R240.2, R241.1
/B5: R205.2, R206.1, R214.2, R215.1, R223.2, R224.1, R232.2, R233.1, R241.2, R242.1
/B6: R206.2, R207.1, R215.2, R216.1, R224.2, R225.1, R233.2, R234.1, R242.2, R243.1
/B7: R207.2, R208.1, R216.2, R217.1, R225.2, R226.1, R234.2, R235.1, R243.2, R244.1
/B8: R208.2, R209.1, R217.2, R218.1, R226.2, R227.1, R235.2, R236.1, R244.2, R245.1
/C1: R301.2, R302.1, R310.2, R311.1, R319.2, R320.1, R328.2, R329.1, R337.2, R338.1
/C2: R302.2, R303.1, R311.2, R312.1, R320.2, R321.1, R329.2, R330.1, R338.2, R339.1
/C3: R303.2, R304.1, R312.2, R313.1, R321.2, R322.1, R330.2, R331.1, R339.2, R340.1
/C4: R304.2, R305.1, R313.2, R314.1, R322.2, R323.1, R331.2, R332.1, R340.2, R341.1
/C5: R305.2, R306.1, R314.2, R315.1, R323.2, R324.1, R332.2, R333.1, R341.2, R342.1
/C6: R306.2, R307.1, R315.2, R316.1, R324.2, R325.1, R333.2, R334.1, R342.2, R343.1
/C7: R307.2, R308.1, R316.2, R317.1, R325.2, R326.1, R334.2, R335.1, R343.2, R344.1
/C8: R308.2, R309.1, R317.2, R318.1, R326.2, R327.1, R335.2, R336.1, R344.2, R345.1
/Load1: J1.3, J1.4, R309.2, R318.2, R327.2, R336.2, R345.2
/Load2: J1.5, J1.6, R209.2, R218.2, R227.2, R236.2, R245.2
/Load3: J1.7, J1.8, R109.2, R118.2, R127.2, R136.2, R145.2
/Vout: J1.1, J1.2, R101.1, R110.1, R119.1, R128.1, R137.1, R201.1, R237.1, R301.1, R310.1, R319.1, R328.1, R337.1
GND: J1.10, TH1.1
unnamed: J1.9, TH1.2

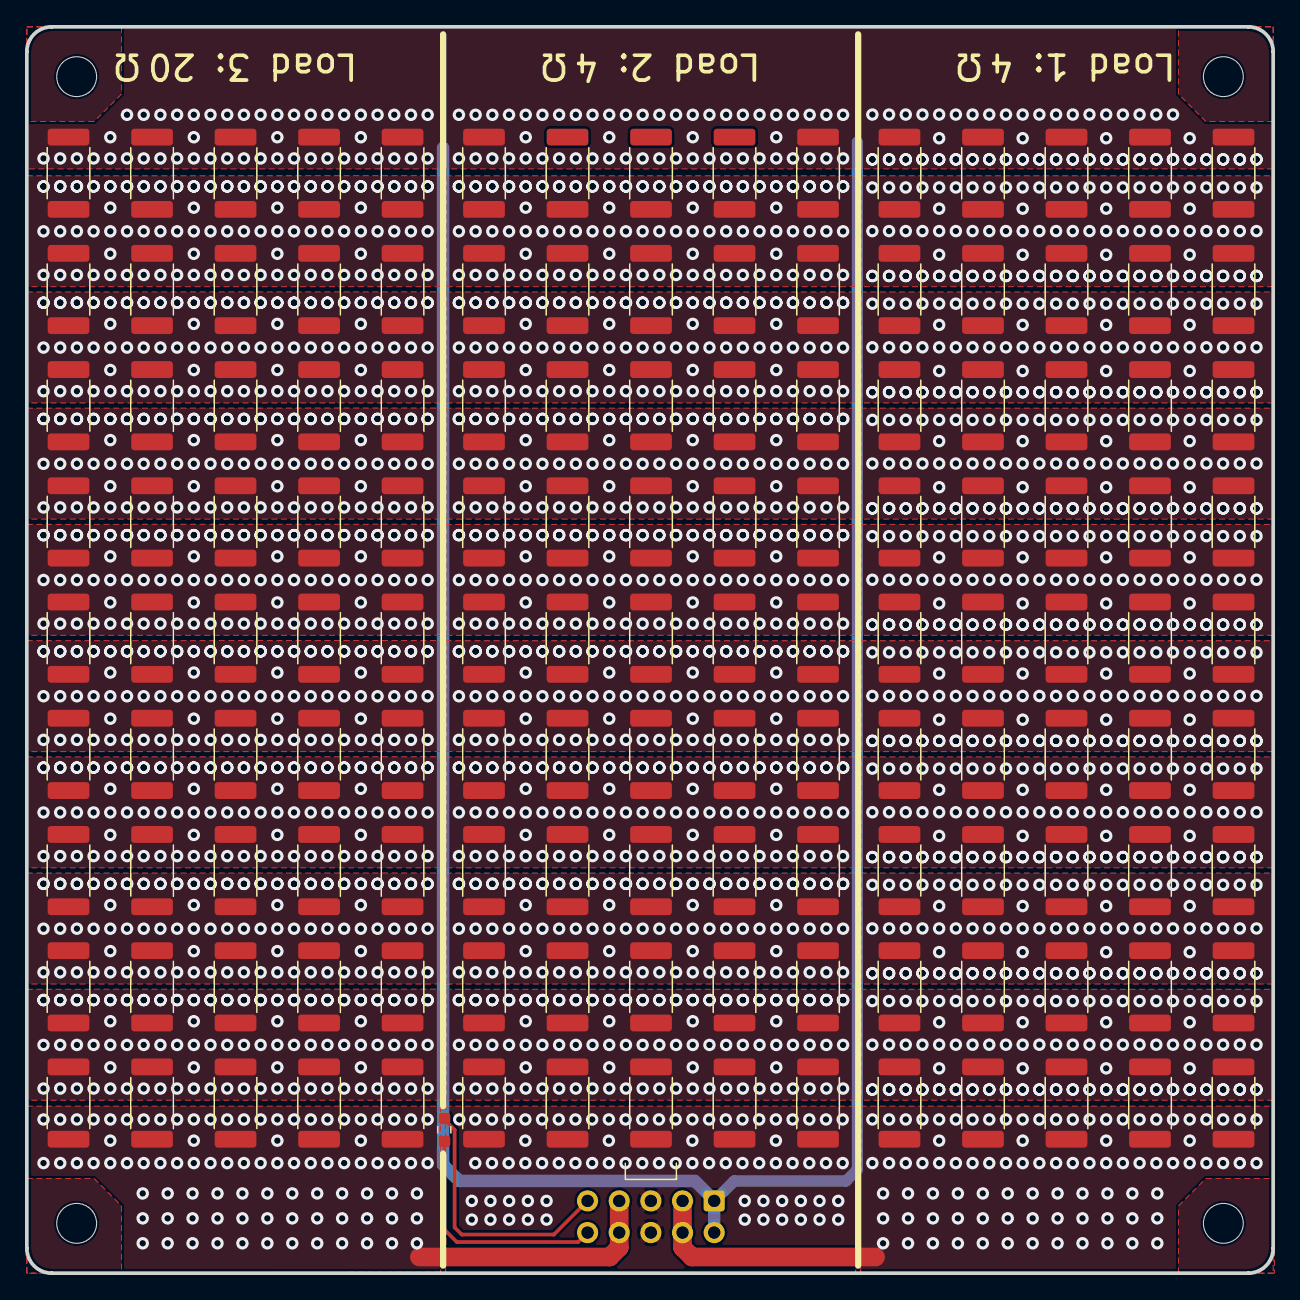
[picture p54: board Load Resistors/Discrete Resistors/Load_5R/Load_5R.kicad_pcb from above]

Board: 2 copper layers, 100.0 x 100.0 mm, 141 parts (0 on the bottom side), 30 nets.

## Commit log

2022-12-13 primary import
    [01_Revision_History.SchDoc, 02_Top_Level.SchDoc, AnalogControlBoard.PcbDoc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]
2023-01-10 Changed to ATL431BQDBZR
    [Input.SchDoc, Vreg_Learning_Platform.PrjPcb]
2023-01-12 basic MD Update
    [BOM_JLC.xlsx, Bill of Materials.xlsx, Pick and Place Files.csv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]
2023-05-11 version 2.2 stable
    [02_Top_Level.SchDoc, BOM_JLC.xlsx, Bill of Materials.xlsx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]
2023-05-12 stabil 2.2
    [02_Top_Level.SchDoc, Bill of Materials.xlsx, Input.SchDoc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]
2023-05-12 output management
    [Bill of Materials.xlsx, Pick and Place Files.csv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]
